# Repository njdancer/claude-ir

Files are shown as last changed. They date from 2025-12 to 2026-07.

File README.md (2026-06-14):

# claude-ir — ESP32 IR smart controller for ActronAir AC

A smart IR controller for an **ActronAir** (rebranded Midea) air conditioner.
The remote's IR protocol has been fully reverse-engineered, and a working
ESP8266 breadboard transmits real commands to the AC. The active mission is a
custom **ESP32-C3** dev board, taken from schematic → PCB → fabricated,
verified unit → production firmware → eventual HomeKit.

> 🤖 **Designed end-to-end by [Claude](https://claude.ai)** (Anthropic),
> directed by Nick Dancer. Reverse engineering, schematic, PCB layout,
> firmware, and the web UI were produced autonomously. Non-commercial hobby
> project.

📦 **Published board artifacts** (regenerated on every merge):
**<https://njdancer.github.io/claude-ir/>** — interactive 3D board viewer,
schematic PDF/SVGs, BOM, and the JLCPCB fabrication package.

## Status

| Part | State |
|---|---|
| **IR protocol** | ✅ Reverse-engineered (BOSCH144 + COOLIX), documented in `re-findings.md` |
| **Breadboard POC** | ✅ Working — ESP8266 transmits to the real AC (the verified reference) |
| **ESP32-C3 board** | 🟢 v2 cost-down redesign — schematic + PCB complete, CI-green; **pre-fabrication** |
| **Firmware (ESP32-C3)** | 🟢 Ported (`pio run -e esp32-c3`); production hardening in progress |
| **Web control UI** | ✅ React Router app with mock + real serial |
| **HomeKit** | ⏸️ Not started |

See **[`ROADMAP.md`](./ROADMAP.md)** for the live project state and next
actions — it is the authoritative state file.

## Sources of truth

| Artifact | Truth for |
|---|---|
| `hardware/*.kicad_sch` / `.kicad_pcb` | The board design (edit only via KiCad) |
| `hardware/esp32-ir-remote.net` | Reviewable electrical state (regenerated by `scripts/hardware-check.sh`) |
| `specs/hardware-dev-board-v1.md` | Board requirements (RFC-style spec) |
| `re-findings.md` | IR protocol knowledge (byte maps, timings) |
| `ROADMAP.md` | Project state & next actions |
| `hardware/notes/*.md` | Design rationale (if a note contradicts the schematic, the schematic wins) |

## The ESP32-C3 board (`hardware/`)

The custom board uses an **ESP32-C3-WROOM-02** module whose native
USB-Serial-JTAG controller means no USB-UART bridge chip: flash and monitor run
straight over USB-C. Key subsystems: 4× IR-emitter array (TSAL6200 via an
AO3400A driver), TSOP38238 IR receiver, AHT20 I²C temp/humidity sensor,
AMS1117-3.3 LDO from USB-C 5 V, and status/user LEDs. GPIO map and
per-subsystem rationale live in [`hardware/notes/README.md`](./hardware/notes/README.md).

**CI is the authoritative hardware gate** (`.github/workflows/ci.yml`): every PR
runs ERC/DRC vs `hardware/ci-baseline.json`, netlist freshness, schematic↔PCB
parity, page-extent and 3D-model checks, BOM LCSC lint, firmware builds + native
tests, and the app's typecheck/unit/e2e. Open a PR and watch CI rather than
re-running the battery by hand.

```bash
./scripts/hardware-check.sh              # ERC + regenerate netlist (needs kicad-cli)
python3 scripts/ci/hardware_validate.py  # full design gate (what CI runs)
python3 scripts/fab-outputs.py           # regenerate the JLCPCB order package
./scripts/build-site.sh                  # build the Pages site (schematic, 3D viewer, fab)
```

> ⚠️ KiCad work happens on Nick's Mac (KiCad 9 + the kicad MCP). Remote/web
> sessions do firmware, analysis, app, docs, and planning only — they queue
> KiCad tasks in `ROADMAP.md`.

## IR protocol

ActronAir is controlled with two protocols, both natively supported by
IRremoteESP8266:

- **BOSCH144** (144-bit) — climate state: power-on, temperature, mode, fan.
- **COOLIX** (24-bit) — discrete commands: power-off (`0xB27BE0`), swing, boost, LED.

The two payloads carry **disjoint** attributes, so AC state can be partially
stale after any single command — firmware must track per-payload freshness.
Full byte maps and timings are in [`re-findings.md`](./re-findings.md).

## Breadboard reference (working POC)

The proven ESP8266 reference that the board is based on:

- **Board:** ESP8266 NodeMCU (ESP-12E)
- **IR RX:** TSOP/VS1838B-class receiver OUT → GPIO14 (D5)
- **IR TX:** IR LED (940 nm) driven by a 2N2222 on GPIO4 (D2), 470 Ω base / current-limited LED

Full wiring is in [`wiring.md`](./wiring.md). The firmware exposes a 115200-baud
serial command interface:

| Command | Example | Description |
|---|---|---|
| `POWER:ON` / `POWER:OFF` | `POWER:ON` | On (BOSCH144) / Off (COOLIX) |
| `TEMP:<16.0–30.0>` | `TEMP:22.5` | Set temperature (0.5° steps) |
| `MODE:<COOL\|HEAT\|DRY\|FAN\|AUTO>` | `MODE:COOL` | Set mode |
| `FAN:<AUTO\|20…100>` | `FAN:60` | Set fan speed |
| `SWING` / `BOOST` / `LED` | `BOOST` | Special functions (COOLIX) |
| `STATE` | `STATE` | Query tracked state |

Responses are `OK:<message>` or `ERROR:<message>`.

## Web control UI (`app/`)

A React Router (v7) full-stack app for AC control over serial, with a mock
serial mode for hardware-free development.

```bash
cd app && pnpm install
MOCK_SERIAL=true pnpm dev   # http://localhost:5173, no hardware needed
pnpm test                   # vitest unit tests
pnpm test:e2e               # playwright e2e
```

For real hardware, set the serial port in `app/app/lib/serial.server.ts`.

## Build & test

```bash
pio run -e esp32-c3              # build the ESP32-C3 board firmware
pio run -e nodemcuv2             # build the ESP8266 breadboard firmware
pio test -e native              # host-side unit tests
./scripts/flash.sh              # flash from the macOS host
./scripts/monitor.sh            # serial monitor (115200)
python3 scripts/capture.py <lbl># capture one IR signal to captures/
python3 analysis/decoder.py     # analyze the capture corpus
```

Firmware builds run in the podman devcontainer (or host); flash/monitor run on
the macOS host (USB passthrough doesn't work under podman/macOS).

## References

- [IRremoteESP8266](https://github.com/crankyoldgit/IRremoteESP8266)
- [PlatformIO](https://docs.platformio.org/)
- [Claude Code on the web](https://code.claude.com/docs/en/claude-code-on-the-web)

## License

Non-commercial, educational/personal hobby project. The spark mark on the
published site is an original homage to Claude's logo.

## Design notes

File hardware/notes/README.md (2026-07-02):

# Hardware Engineering Notes

> ⚠️ **The board is now the v2 ESP32-C3 cost-down redesign** (ESP32-C3-WROOM-02,
> AMS1117 LDO, AHT20 sensor, SMD USB-C; CH340C/JTAG/buck removed). Several notes
> below still describe the v1 WROOM-32E architecture and are being updated. The
> as-built description is the v2 change set in [`ROADMAP.md`](../../ROADMAP.md);
> where a note disagrees with the schematic, the schematic wins.

Design rationale for the ESP32 IR Remote Control Development Board (v1.1).

**Source of truth: the KiCad project** (`hardware/esp32-ir-remote.kicad_sch` /
`.kicad_pcb`). These notes capture *why* the circuit is the way it is — design
decisions, calculations, and constraints. They intentionally do not enumerate
connections; the schematic and exported netlist do that. If a note and the
schematic disagree, the schematic wins and the note should be fixed.

## Verification workflow

Every schematic change should be followed by:

```bash
./scripts/hardware-check.sh
```

This runs ERC and regenerates `hardware/esp32-ir-remote.net` via `kicad-cli`
(found in PATH or the macOS KiCad.app bundle). Commit the regenerated netlist
alongside the schematic change — the netlist diff is the reviewable record of
what changed electrically, since `.kicad_sch` diffs are dominated by graphics.

## Subsystems

| Note | Scope |
|---|---|
| [power-supply.md](./power-supply.md) | USB-C input, protection, AP63203 buck regulation |
| [usb-serial.md](./usb-serial.md) | v2 native USB (no bridge); USB-C connector data path + hand-solder note |
| [esp32-mcu.md](./esp32-mcu.md) | WROOM-32E module, strapping pins, buttons, breakout header |
| [ir-transmitter.md](./ir-transmitter.md) | 4× TSAL6200 array with MOSFET driver |
| [ir-receiver.md](./ir-receiver.md) | TSOP38238 development receiver |
| [temp-sensor.md](./temp-sensor.md) | DHT22/AM2302 for Follow Me |
| [status-leds.md](./status-leds.md) | Serial activity and user LEDs |
| [layout.md](./layout.md) | PCB layout constraints: placement, routing, stackup (H2) |

## GPIO pin assignments (v2 board, ESP32-C3; r2 GPIO remap 2026-07-02)

The r2 autoresearch loop remapped the free GPIOs so each signal exits the
module on the side facing its board zone (B.Cu ground-plane slotting fell
390→167 mm). `scripts/ci/golden_netlist_v2.py` asserts this map; firmware
pins live in `platformio.ini` `[env:esp32-c3]` build_flags.

| GPIO | Function | Direction | Notes |
|---|---|---|---|
| EN | Reset (SW1)  | Input | R5 pull-up + C6 POR RC |
| 9 | Boot (SW2) | Input | strapping, R6 pull-up |
| 10 | IR transmit  | Output | 38 kHz → R13 → Q3 gate; D10 TX indicator  |
| 6 | IR receive | Input | TSOP38238 |
| 20 | I2C SDA | I/O | AHT20 + J4; R28 pull-up (UART0-RX pin) |
| 21 | I2C SCL | Output | AHT20 + J4; R29 pull-up (UART0-TX pin) — ROM boot spew clocks the bus once per boot; firmware must bus-clear at init |
| 3 | User LED 1 | Output | direct drive, yellow 0805 |
| 1 | User LED 2 | Output | direct drive, yellow 0805 |
| 18/19| USB D−/D+ | I/O | native USB-Serial-JTAG |
| 2, 8 | (strapping)  | — | pull-ups only, left NC |
| 0,4,5,7 | spares | I/O | broken out on J4 |

## Top-level design rationale

**Power architecture.** v2 uses a single AMS1117-3.3 LDO from USB 5 V (the v1
AP63203 buck was dropped in the cost-down: a 1S LiPo can't feed the buck's
dropout anyway, and on USB power the LDO's ~0.85 W is handled by a ~1050 mm²
top-side thermal pour + B.Cu island stitched under the tab — θ_JA ≈ 45–55 °C/W,
T_J ≈ 72 °C worst case). See [power-supply.md](./power-supply.md).

**IR LED drive.** A single MOSFET drives all four LEDs so they emit
simultaneously for maximum coverage. ~86 mA per LED (22 Ω Basic-part series
resistors) gives good range at reasonable power.

**Boot configuration.** The C3's strapping pins (IO2, IO8, IO9) carry
pull-ups; flashing runs over native USB-Serial-JTAG (no auto-reset circuit
needed — SW1/SW2 remain for manual recovery).

**Development-board posture.** The board prioritizes ease of assembly and
debugging over miniaturization: hand-solderable packages only, DevKitC-
compatible breakout header, and features (IR receiver, extensive status LEDs)
that a production board would omit. See `specs/hardware-dev-board-v1.md` for
the full requirements spec.

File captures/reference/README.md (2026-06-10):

# Reference IR captures (protocol ground truth)

Curated, de-duplicated subset of the local capture corpus, copied here from
the gitignored `captures/*.txt` scratch files so the protocol fixtures are
version-controlled. Each file is a real capture of the ActronAir remote
decoded by the ESP8266 + IRremoteESP8266 (see `re-findings.md`).

Selection: one clean, valid-decode capture per documented state. The physical
remote is the only way to regenerate these, so treat them as fixtures —
cross-checked against the `include/bosch144_protocol.h` unit tests.

Notes:
- Temp sweep (`temp-16`..`temp-26`, COOL mode) shares the `3FC0` prefix; the
  temperature nibble varies. Half-degree variants (`16.5`, `18.5`) exercise the
  byte-14 bit-5 half-degree flag.
- `power-on` (3FC0) vs `power-on-2`/`power-button` (BF40) capture different base
  states; both retained intentionally.
- COOLIX commands are discrete toggles: power-off `0xB27BE0`, swing `0xB9F504/5`
  (alternating), boost `0xB9F501`, LED `0xB9F509`.
- No valid `temp-28` capture exists (both bench attempts failed to decode) —
  this is the open item flagged for F1.5 bench verification.

| Fixture | Protocol | Decoded code | Bits | Original capture |
|---|---|---|---|---|
| `boost-button-coolix.txt` | COOLIX | `0xB9F501` | 24 Bits | `20251229_145919_boost-button.txt` |
| `fan-press-1.txt` | BOSCH144 | `0xB24DFF0020DFB24DFF0020DFD514000000E9` | 144 Bits | `20251228_153501_fan-press-1.txt` |
| `fan-press-2.txt` | BOSCH144 | `0xB24D9F6020DFB24D9F6020DFD528000000FD` | 144 Bits | `20251228_153530_fan-press-2.txt` |
| `fan-press-3.txt` | BOSCH144 | `0xB24D5FA020DFB24D5FA020DFD53C00000011` | 144 Bits | `20251228_153548_fan-press-3.txt` |
| `fan-press-4.txt` | BOSCH144 | `0xB24D3FC020DFB24D3FC020DFD55000000025` | 144 Bits | `20251228_153621_fan-press-4.txt` |
| `fan-press-5.txt` | BOSCH144 | `0xB24D3FC020DFB24D3FC020DFD56400000039` | 144 Bits | `20251228_153656_fan-press-5.txt` |
| `fan-press-6-back-to-auto.txt` | BOSCH144 | `0xB24DBF4020DFB24DBF4020DFD5660000003B` | 144 Bits | `20251228_153724_fan-press-6-back-to-auto.txt` |
| `led-button-coolix.txt` | COOLIX | `0xB9F509` | 24 Bits | `20251229_145934_led-button.txt` |
| `mode-press-1-dry.txt` | BOSCH144 | `0xB24D1FE024DBB24D1FE024DBD5650000003A` | 144 Bits | `20251228_153224_mode-press-1.txt` |
| `mode-press-2-heat.txt` | BOSCH144 | `0xB24DBF402CD3B24DBF402CD3D5660000003B` | 144 Bits | `20251228_153253_mode-press-2.txt` |
| `mode-press-3.txt` | BOSCH144 | `0xB24DBF40E41BB24DBF40E41BD5660000003B` | 144 Bits | `20251228_153316_mode-press-3.txt` |
| `mode-press-4.txt` | BOSCH144 | `0xB24D1FE028D7B24D1FE028D7D5650000003A` | 144 Bits | `20251228_153337_mode-press-4.txt` |
| `mode-press-5-back-to-cool.txt` | BOSCH144 | `0xB24DBF4020DFB24DBF4020DFD5660000003B` | 144 Bits | `20251228_153409_mode-press-5-back-to-cool.txt` |
| `power-button.txt` | BOSCH144 | `0xB24DBF4040BFB24DBF4040BFD5662000005B` | 144 Bits | `20251229_145719_power-button.txt` |
| `power-off-coolix.txt` | COOLIX | `0xB27BE0` | 24 Bits | `20251229_145838_power-off.txt` |
| `power-on-2.txt` | BOSCH144 | `0xB24DBF4040BFB24DBF4040BFD5662000005B` | 144 Bits | `20251229_145901_power-on-2.txt` |
| `power-on.txt` | BOSCH144 | `0xB24D3FC040BFB24D3FC040BFD56400000039` | 144 Bits | `20251228_085537_power-on.txt` |
| `swing-test-coolix-a.txt` | COOLIX | `0xB9F504` | 24 Bits | `20251228_155349_swing-test.txt` |
| `swing-test-coolix-b.txt` | COOLIX | `0xB9F505` | 24 Bits | `20251228_155423_swing-test-2.txt` |
| `temp-16.5.txt` | BOSCH144 | `0xB24D3FC000FFB24D3FC000FFD56420100069` | 144 Bits | `20251228_091732_temp-16.5-retry.txt` |
| `temp-16.txt` | BOSCH144 | `0xB24D3FC000FFB24D3FC000FFD56400100049` | 144 Bits | `20251228_091151_temp-16.txt` |
| `temp-18.5.txt` | BOSCH144 | `0xB24D3FC010EFB24D3FC010EFD56420000059` | 144 Bits | `20251228_091832_temp-18.5.txt` |
| `temp-18.txt` | BOSCH144 | `0xB24D3FC010EFB24D3FC010EFD56400000039` | 144 Bits | `20251228_091759_temp-18.txt` |
| `temp-20.txt` | BOSCH144 | `0xB24D3FC020DFB24D3FC020DFD56400000039` | 144 Bits | `20251228_085719_temp-20.txt` |
| `temp-22.txt` | BOSCH144 | `0xB24D3FC0708FB24D3FC0708FD56400000039` | 144 Bits | `20251228_092757_temp-22.txt` |
| `temp-24.txt` | BOSCH144 | `0xB24D3FC040BFB24D3FC040BFD56400000039` | 144 Bits | `20251228_085741_temp-24.txt` |
| `temp-26.txt` | BOSCH144 | `0xB24D3FC0D02FB24D3FC0D02FD56400000039` | 144 Bits | `20251228_092834_temp-26.txt` |
| `temp-max-cool.txt` | BOSCH144 | `0xB24D3FC0B04FB24D3FC0B04FD56400000039` | 144 Bits | `20251228_092000_temp-max-cool.txt` |

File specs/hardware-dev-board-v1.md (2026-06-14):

# ESP32 IR Remote Control Development Board - Hardware Specification v1.4

## Overview

This specification defines the hardware requirements for a development board that enables testing and development of an ESP32-based smart AC remote control system using infrared transmission. The board serves as a transition from the current ESP8266 breadboard proof-of-concept to a manufacturable design suitable for firmware development and eventual production refinement.

> ⚠️ **SUPERSEDED ARCHITECTURE — read this first (v2.0, 2026-06).** The
> fabricated board is the **v2 ESP32-C3 cost-down redesign**, NOT the
> ESP32-WROOM-32E architecture described in the body of this document below.
> The as-built board:
> - **MCU: ESP32-C3-WROOM-02-N4** (LCSC C2934560), not WROOM-32E. The C3's
>   native USB-Serial-JTAG let the **entire CH340C USB-serial subsystem be
>   deleted** (no bridge, no auto-reset FETs).
> - **Power: AMS1117-3.3 LDO** (U1), not the AP63203 buck + inductor.
> - **Temp/humidity: AHT20** I2C sensor (U5), not the AM2302/DHT22.
> - **USB-C: SMD 16P XKB U262** receptacle (J2), not the THT GCT part.
> - Status LEDs moved to 0805 SMD; JTAG header and TX/RX activity LEDs removed.
>
> The **as-built description is the v2 change set in [`ROADMAP.md`](../ROADMAP.md)**
> (the project state file) and the live schematic/netlist under `hardware/`.
> The WROOM-32E content below is retained for v1.4 design rationale only and
> is being rewritten for v2 as a follow-up. Where this spec body and the
> schematic disagree, **the schematic wins.**

> **Revision note (v1.4):** Pre-order cost/availability pass. The assembly
> model is now explicitly **SMT-only machine assembly plus a hand-solder
> kit** (see [Assembly Considerations](#assembly-considerations)): JLCPCB
> places only top-side SMD parts, and every through-hole part plus the easy
> two-terminal SMD Extended parts ship loose. Two Basic-part substitutions:
> the IR driver MOSFET Q3 (IRLML6344 → AO3400A, same SOT-23/pinout, meets
> all stated requirements) and the BOOT/RESET switches (TS-1088R → XKB
> TS-1187A-B-A-B, SMD 5.1×5.1mm 4-pad — same-row terminals internally
> common). Only three Extended parts remain machine-placed: the buck
> regulator, the CH340C, and the WROOM module.
>
> **Revision note (v1.3):** Auto-reset transistors Q1/Q2 changed from NPN BJTs
> (S8050) to 2N7002 N-channel MOSFETs. The SOT-23 pinouts map 1:1 (B→G, E→S,
> C→D), so the change is layout-neutral; it consolidates Q1/Q2 onto the same
> BOM line as Q4/Q5 (JLCPCB Basic part C8545). Circuit topology and truth
> table are unchanged. The R21/R26 bypass links changed from 0Ω to **470Ω**
> to limit FET body-diode current into the CH340C while RESET/BOOT is held
> (restores BJT-grade benignity); they remain desolder-to-disable. See
> [Auto-Reset Circuit](#auto-reset-circuit).
>
> **Revision note (v1.2):** The board target shifted toward "get it fabricated." The
> bulky 2×19 ESP32-DevKitC debug breakout header is **removed** and replaced with a
> small set of purposeful connection points (I2C Qwiic, a compact spare-GPIO + power
> header, an external IR-emitter header, and an unpopulated JTAG footprint) — see
> [Connection Points and Expansion](#connection-points-and-expansion). The
> WROOM-32E (PCB antenna) is retained; the U.FL external-antenna option is deferred.
> This revision also reconciles the spec to the KiCad schematic (the source of
> truth): auto-reset bypass jumpers JP2/JP3 are now R21/R26 0Ω SMD links, and the
> buck inductor L1 is 4.7µH. Several H1.4 datasheet-review fixes are folded in (IR-TX
> gate resistor, IR-RX supply filter). The Bill of Materials below lags the schematic
> on reference designators and MUST be regenerated from it (see the BOM note).

### Design Philosophy

The board prioritizes ease of assembly and debugging over miniaturization. Components MUST be hand-solderable, which excludes packages like BGA but permits both through-hole and large SMD components (SOT-223, SOIC, etc.). Standard 2.54mm (0.1") pin headers are PREFERRED for development flexibility, but other pitches and connection methods are acceptable where hand assembly remains feasible.

The design intentionally includes features (such as IR receiver and extensive status LEDs) that may be omitted from production boards but facilitate rapid development iteration.

### Manufacturing Target

The board MUST be manufacturable through JLCPCB's standard PCB service with components readily available through common distributors (Digikey, Mouser, LCSC). Two-layer PCB construction is acceptable given the modest component count and frequency requirements.

## Functional Requirements

### Primary Functions

The board MUST provide:

1. **Omnidirectional IR Transmission**: Reliable infrared signal transmission across a 180-degree horizontal arc at distances up to 10 meters. The system must function with indirect line-of-sight (wall reflections) to match typical consumer remote control behavior.

2. **Environmental Sensing**: Accurate room temperature measurement (±1°C) for implementing "Follow Me" functionality where the AC unit adjusts output based on temperature at the remote's location.

3. **Development Support**: Comprehensive debugging capabilities including IR signal reception verification, serial communication monitoring, and visual feedback of system state.

### IR Transmission Characteristics

The IR transmitter MUST generate 940nm infrared pulses modulated at 38kHz carrier frequency compatible with the COOLIX and BOSCH144 protocols identified in the reverse engineering phase. The transmission pattern must support both sustained transmission (for BOSCH144's 144-bit messages) and short burst commands (for COOLIX's 24-bit special functions).

Unlike the current breadboard implementation which requires precise aiming, the production system must achieve reliable communication when the remote is casually pointed toward the AC unit or nearby surfaces. This requires multiple IR emitters with overlapping coverage areas rather than a single high-power directional emitter.

### Power Delivery

The board MUST operate from USB-C power (5V nominal) and maintain stable 3.3V regulation under varying load conditions. Peak current draw during WiFi transmission with simultaneous IR emission (approximately 350-400mA) must not cause voltage droop exceeding 100mV at the ESP32's power pins.

The power subsystem MUST implement overcurrent protection (trip at 2A) and overvoltage protection (clamp below 6V). Reverse polarity protection is omitted for the USB-C input as the connector enforces correct orientation; reverse protection MAY be added on the battery input path when that feature is implemented.

### Battery Support

Battery operation is **deferred to v2**. This development board is USB-powered only.

The spare-GPIO + power header (see [Connection Points and Expansion](#connection-points-and-expansion)) exposes 3.3V and 5V rails, enabling experimentation with external battery and power management circuits on a separate prototyping board. A jumper (JP1) on the buck converter's EN pin allows disabling the internal regulator when testing external power solutions (see Voltage Regulation section).

## Component Specifications

### Microcontroller Module

**Specified Module**: ESP32-WROOM-32E-N4 (Espressif WiFi+BT module)

The board MUST use the ESP32-WROOM-32E-N4 module directly, rather than a development board. This provides full control over the supporting circuitry while using a proven, FCC/CE certified RF module. The module integrates:

- ESP32-D0WD-V3 dual-core Xtensa LX6 @ 240MHz
- 4MB SPI flash (N4 variant)
- 520KB internal SRAM
- 40MHz crystal oscillator
- PCB trace antenna
- All required RF matching and filtering

**Module Specifications**:

- Dimensions: 18mm × 25.5mm × 3.1mm
- Pins: 38 castellated pads at 1.27mm pitch
- Operating voltage: 3.0-3.6V (3.3V nominal)
- Operating temperature: -40°C to +85°C
- Deep sleep current: <5µA

The module exposes sufficient GPIO pins to support:

- 4× IR LED driver signals
- 1× IR receiver input
- I2C interface (SDA/SCL) for temperature sensor
- UART0 (programming and debug)
- User programmable GPIO for expansion

**Required Support Circuitry**: Unlike a development board, the bare module requires external circuitry for:

1. **Power regulation**: 3.3V supply (provided by AP63203 synchronous buck converter per this spec)
2. **USB-to-UART bridge**: For programming and serial communication (see USB-to-UART Bridge section)
3. **Auto-reset circuit**: Transistor network for automatic bootloader entry (see Auto-Reset Circuit section)
4. **EN pin conditioning**: RC delay circuit for reliable power-on reset
5. **Strapping pin management**: Pull-ups/pull-downs on boot mode pins

**Power Architecture**: The board provides 3.3V regulation via the AP63203 synchronous buck converter specified in the Voltage Regulation section. The module draws:

- Typical: 80-120mA (WiFi idle)
- Peak: 240mA (WiFi TX burst)
- Deep sleep: <5µA

The 2A-rated buck converter provides adequate headroom for the module plus all peripherals.

**Mounting**: The module's castellated pads can be hand-soldered to the PCB. For easier assembly, the PCB layout SHOULD include:

- Extended pads beyond the module footprint for solder iron access
- Solder mask relief around pads
- Clear silkscreen indicating pin 1 orientation

### Infrared Emitters

**Quantity**: 4 emitters
**Package**: 5mm (T-1 3/4) through-hole or equivalent hand-solderable package

The board MUST position four IR LEDs with their optical axes oriented at approximately 0°, 45°, 90°, and 135° from the board's centerline, providing overlapping hemispherical coverage. All emitters drive simultaneously during transmission to maximize signal strength across the coverage area.

**LED Requirements**:

- Peak wavelength: 940nm ±10nm (matches TSOP receiver sensitivity peak)
- Continuous forward current: ≥100mA
- Peak pulsed current: ≥1A (at 10% duty cycle, for future high-power modes)
- Forward voltage: 1.2-1.5V typical
- Radiant intensity: ≥30 mW/sr @ 100mA
- Viewing angle: ≥20° for adequate coverage overlap

**Suggested Part**: Vishay TSAL6200 meets all requirements and is widely available.

Each LED MUST be driven through an independent NPN transistor with base current limiting and collector current limiting resistors. The current limiting resistor value MUST provide 80-100mA LED current when driven from the regulated supply, balancing transmission power against LED lifetime and power dissipation.

### Infrared Receiver

**Quantity**: 1
**Purpose**: Development and debugging only
**Package**: Through-hole 3-pin module or equivalent hand-solderable package

**Receiver Requirements**:

- Center frequency: 38kHz (matches COOLIX/BOSCH144 carrier frequency)
- Supply voltage: 3.3V compatible
- Output: Active-low demodulated signal
- Built-in bandpass filter and AGC
- Minimum detectable power: <1 mW/m² typical for IR receiver modules

**Suggested Parts**: Vishay TSOP1838, TSOP4838, or equivalent 38kHz receiver modules.

The IR receiver enables verification of transmitted waveforms and debugging of protocol encoding. It MUST connect to a GPIO pin configured with interrupt capability to capture timing-accurate signal edges. While essential during development, production boards may omit this component.

### Temperature Sensor

**Interface**: Single-wire (proprietary protocol)
**Mounting**: Through-hole module with pin headers

**Sensor Requirements**:

- Temperature accuracy: ±0.5°C across 18-28°C range (typical indoor AC environment)
- Supply voltage: 3.3V compatible
- Sleep current: <10µA (for battery operation testing)
- Response time: <2 seconds for room temperature changes

**Additional Capabilities**:

- Humidity sensing (enables comfort index calculations)

**Specified Part**: DHT22 (AM2302) temperature and humidity sensor module. The module includes the required pull-up resistor on the data line. Connect to any available GPIO pin.

### USB-C Power Connector

**Connector Requirements**:

- Mounting: Through-hole or large SMD with hand-solderable pins (not fine-pitch SMT-only)
- Pinout: USB 2.0 minimum (VBUS, GND, CC1, CC2 accessible; D+/D- optional)
- Mechanical strength: Through-hole anchor pins or large mounting pads
- Current rating: ≥3A continuous

**Specified Connector**: GCT USB4085-GF-A (fully through-hole USB-C receptacle)

This connector is specified due to its through-hole construction enabling reliable hand assembly and its availability from major distributors. Alternative through-hole USB-C receptacles with equivalent pinout are acceptable.

**Power Delivery Configuration**: CC1 and CC2 pins MUST connect to ground through 5.1kΩ ±5% resistors to signal 5V/3A power capability to USB-PD sources. This resistor configuration enables the board to draw sufficient current from modern USB-C chargers without implementing complex PD negotiation.

**USB Data Lines**: D+ and D- pins connect to the USB-to-UART bridge IC for programming and serial communication (see USB-to-UART Bridge section).

### USB-to-UART Bridge

The board MUST include a USB-to-UART bridge IC to enable programming and serial communication with the ESP32 module. This replaces the functionality provided by the CP2102 on the ESP32-DevKitC.

**Bridge IC Requirements**:

- USB 2.0 Full Speed (12 Mbps) support
- 3.3V I/O compatible (no level shifting required)
- Baud rates up to 921600 (required for fast firmware upload)
- DTR and RTS flow control signals (required for auto-reset circuit)
- Package: Hand-solderable (SOIC, SSOP, or QFN with exposed pad)
- Built-in oscillator preferred (reduces external component count)
- Windows/macOS/Linux driver support

**Recommended ICs** (in order of preference):

1. **CP2102N** (Silicon Labs) - QFN-28 or QFN-24
   - Direct replacement for DevKitC's CP2102
   - Excellent driver support across all platforms
   - Built-in oscillator, minimal external components
   - Configurable GPIO pins (optional features)
   - Note: QFN package requires careful hand-soldering or reflow

2. **CH340C** (WCH) - SOP-16
   - Lower cost alternative
   - Built-in oscillator (no external crystal needed)
   - Wider pin pitch (easier hand soldering than QFN)
   - Good driver support (built into modern OS versions)
   - Requires 100nF decoupling capacitor

3. **CH340G** (WCH) - SOP-16
   - Similar to CH340C but requires external 12MHz crystal
   - Slightly lower cost, slightly more complex BOM

**Recommended Implementation**: CH340C in SOP-16 package

The CH340C offers the best balance of hand-solderability, cost, and simplicity for this development board. Its SOP-16 package (1.27mm pitch) is manageable with a fine-tip soldering iron, and the built-in oscillator eliminates the need for an external crystal.

**CH340C Circuit Requirements**:

```
USB D+ ──────────────────── CH340C UD+
USB D- ──────────────────── CH340C UD-
3.3V ────┬─────────────── CH340C VCC
         │
         └─────────────── CH340C V3 ───[100nF]─── GND
GND ─────────────────────── CH340C GND
GND ─────────────────────── CH340C R232 (pin 15)
CH340C TXD ─────────────── ESP32 U0RXD (GPIO3)
CH340C RXD ─────────────── ESP32 U0TXD (GPIO1)
CH340C DTR# ────[R21 470Ω]── Auto-reset circuit (cross-coupled, DTR side)
CH340C RTS# ────[R26 470Ω]── Auto-reset circuit (cross-coupled, RTS side)
```

**Notes**:
- TX/RX are crossed: CH340C TXD connects to ESP32 RXD, and vice versa
- **3.3V Operation**: V3 must be tied to VCC (both connected to 3.3V). This bypasses the internal regulator. Add 100nF decoupling capacitor from V3 to GND.
- **R232 Pin**: Must be tied to GND for TTL-level output compatible with ESP32. If tied high, outputs RS232 levels (wrong).
- DTR# and RTS# are active-low outputs used by the auto-reset circuit
- Refer to CH340C datasheet for physical pin assignments during PCB layout

**ESD Protection**: A USB ESD protection device (e.g., USBLC6-2SC6) SHOULD be placed on D+/D- lines near the USB connector to protect the bridge IC from electrostatic discharge.

### Voltage Regulation

The board MUST regulate the USB 5V input to stable 3.3V for powering the ESP32 module, IR receiver, temperature sensor, and status LEDs. A synchronous buck (step-down) switching regulator is REQUIRED for efficiency and thermal performance.

**Regulator Requirements**:

- Type: Synchronous buck (step-down) switching regulator
- Input voltage: 3.8-32V (wide input range)
- Output voltage: 3.3V ±1%
- Output current: ≥2A continuous
- Switching frequency: ≥500kHz (enables smaller external components)
- Efficiency: ≥90% at typical loads
- Package: Hand-solderable (TSOT26 or larger)
- Protection: Thermal shutdown, overcurrent protection, overvoltage protection

**Specified Implementation**: AP63203 (Diodes Incorporated) - Fixed 3.3V synchronous buck converter

- **Datasheet**: https://www.diodes.com/assets/Datasheets/AP63200-AP63201-AP63203-AP63205.pdf
- Synchronous topology (no external catch diode needed)
- Fixed 3.3V output (±1% accuracy, no feedback resistors needed)
- 2A output capability (ample headroom)
- 1.1MHz switching frequency (small external components)
- ~92-93% efficiency at typical loads
- TSOT26 package (0.95mm pitch, hand-solderable with fine-tip iron)
- Built-in soft-start (4ms), OVP, OCP, thermal shutdown
- Frequency spread spectrum for EMI reduction

**Required Support Components**:

1. **Input capacitor (C1)**: 10µF ceramic, 10V or higher (placed close to VIN pin)
2. **Output capacitors (C2, C3)**: 2× 22µF ceramic, 10V or higher (placed close to output)
3. **Bootstrap capacitor (C4)**: 100nF ceramic (between BST and SW pins)
4. **Inductor (L1)**: 4.7µH, ≥2.7A saturation current, low DCR (AP63203 datasheet typical; prefer a JLCPCB Basic part)
   - Package: SMD power inductor (hand-solderable)
   - Size: 4x4mm or 5x5mm typical

**No catch diode required** - the AP63203's synchronous topology uses an integrated low-side MOSFET instead.

**PCB Layout Considerations**:

- Keep switching node (SW pin to inductor) trace short and away from sensitive signals
- Input capacitor must be placed immediately adjacent to VIN and GND pins
- Output capacitors placed close to FB pin and load
- Use multiple vias for ground connections to bottom plane
- Bootstrap capacitor placed close to BST and SW pins

**Buck Converter Disable Jumper (JP1)**:

A 2-pin header (JP1) connects the AP63203 EN pin to GND, allowing the internal regulator to be disabled for external power experimentation:

```
AP63203 EN pin ────┬──── (internal pullup to VIN)
                   │
                  JP1 (2-pin header)
                   │
                  GND
```

- **JP1 open (default)**: EN floats high via internal pullup → buck converter enabled, normal USB operation
- **JP1 shorted**: EN pulled to GND → buck converter disabled, output goes high-impedance

**Use case**: When prototyping external battery/buck-boost circuits on a separate board, install the JP1 jumper to disable the internal regulator, then feed external 3.3V via the GPIO expansion header's 3V3 pin.

### Protection Components

The power input path MUST include:

**Overcurrent Protection**:

- Type: Resettable PTC fuse (polyfuse) or equivalent resettable overcurrent device
- Hold current: 1.0-1.2A (allows normal operation)
- Trip current: 1.8-2.2A (protects against shorts)
- Package: Through-hole radial or SMD
- **Suggested Part**: Bourns MF-R110 or equivalent

**Overvoltage Protection**:

- Type: TVS (Transient Voltage Suppression) diode
- Clamp voltage: 5.5-6.5V (protects 5V circuit, below regulator absolute maximum)
- Transient power rating: ≥400W
- Package: Hand-solderable (DO-214AA/SMB, DO-214AB/SMC, or through-hole)
- Placement: After fuse, before voltage regulator
- **Suggested Part**: SMBJ5.0A or equivalent

**Reverse Polarity Protection**: Omitted for USB-C input. The USB-C connector physically enforces correct orientation, and the CC resistor configuration ensures proper power negotiation. Reverse protection SHOULD be added on the battery input path when that feature is implemented (P-MOSFET recommended for efficiency).

### Status Indicators

The board MUST include visible LED indicators for debugging and status monitoring. All status LEDs use 3mm through-hole package for compact layout while maintaining hand-solderability.

**Power Rail LEDs** (direct-driven from power rails):

These LEDs connect directly to their respective power rails through current-limiting resistors, providing immediate visual confirmation of power presence without GPIO involvement.

*5V Rail Indicator* (Red):
- Function: Illuminated whenever USB 5V input is present (before buck converter)
- Connection: 5V rail → resistor → LED → GND
- Resistor value: 680Ω for ~5mA with Vf=1.9V red LED
- Purpose: Distinguishes input power issues from buck converter failures

*3.3V Rail Indicator* (Green):
- Function: Illuminated whenever regulated 3.3V is present (after buck converter)
- Connection: 3.3V rail → resistor → LED → GND
- Resistor value: 470Ω for ~3mA with Vf=2.0V green LED
- Purpose: Confirms buck converter operation

**GPIO-Controlled LEDs** (MOSFET-driven from 5V rail):

All GPIO-controlled status LEDs are driven through individual N-channel MOSFETs configured as low-side switches. This design provides:
- Consistent brightness across all LED colors (including blue with Vf ~3.2V)
- Minimal GPIO current draw (~nA gate current vs mA LED current)
- GPIO protection from LED faults
- Ability to use any LED color regardless of forward voltage

*Circuit per LED*:
```
5V ─── R_limit ─── LED(+) ─── LED(-) ─── MOSFET drain
                                         MOSFET source ─── GND
                              GPIO ─── MOSFET gate
                              100kΩ ─── GND (gate pulldown)
```

*MOSFET Requirements*:
- Type: N-channel enhancement mode, logic-level
- Gate threshold: <2V (fully enhanced at Vgs=3.3V)
- Drain current: ≥50mA (adequate for indicator LEDs)
- Package: SOT-23
- **Suggested Part**: 2N7002 or equivalent small-signal MOSFET

*Serial TX/RX LEDs* (Amber, qty 2):
- Function: Visual confirmation of serial communication during programming
- Connection: GPIO-controlled via MOSFET
- Resistor value: 150Ω for ~10mA with Vf=2.0V amber LED (brighter for brief pulses)

*IR Transmit Indicator* (Red):
- Function: Indicates IR transmission activity
- Connection: GPIO-controlled via MOSFET
- Resistor value: 330Ω for ~10mA with Vf=1.9V red LED

*User Programmable LEDs* (Blue, qty 2):
- Function: Software-controlled for debugging and status indication
- Connection: GPIO-controlled via MOSFET
- Resistor value: 330Ω for ~5mA with Vf=3.2V blue LED
- PCB silkscreen MUST label GPIO numbers for firmware reference

**LED Package Requirements**:

- All status indicator LEDs: 3mm (T-1) through-hole package
- IR emitter LEDs remain 5mm (T-1 3/4) for maximum optical output
- Mounting: Positioned for visibility when board is horizontal

**LED Summary Table**:

| Function | Color | Qty | Drive Method | Supply | R_limit |
|---|---|-----|---|---|---|
| 5V Power | Red | 1 | Direct | 5V | 680Ω |
| 3.3V Power | Green | 1 | Direct | 3.3V | 470Ω |
| Serial TX | Amber | 1 | MOSFET | 5V | 150Ω |
| Serial RX | Amber | 1 | MOSFET | 5V | 150Ω |
| IR TX | Red | 1 | MOSFET | 5V | 330Ω |
| User LED 1 | Blue | 1 | MOSFET | 5V | 330Ω |
| User LED 2 | Blue | 1 | MOSFET | 5V | 330Ω |

### Control Switches

The board MUST include two momentary push buttons for ESP32 control:

**RESET Button**:

- Function: Initiates complete ESP32 system reset (equivalent to power cycle)
- Connection: Connects ESP32 EN (enable) pin to ground when pressed
- Pull-up: Shared with auto-reset circuit (see Auto-Reset Circuit section)

**BOOT Button**:

- Function: Enters bootloader/programming mode when held during reset
- Connection: Connects GPIO0 to ground when pressed
- Pull-up: Shared with auto-reset circuit (see Auto-Reset Circuit section)
- Usage: Hold BOOT, press RESET, release both to enter programming mode (manual override of auto-reset)

**Switch Requirements**:

- Type: Tactile momentary switch, normally-open (NO)
- Package: SMD or through-hole, hand-rework-friendly
- Actuation force: 100-300gf (comfortable for frequent development use)
- Positioning: Accessible while USB cable is connected
- **Specified Part (v1.4)**: XKB TS-1187A-B-A-B (LCSC C318884, JLCPCB Basic),
  SMD 5.1×5.1mm, 4 gull-wing terminals. Terminals on the same row are
  internally common, so the part behaves as SPST between the two rows; the
  footprint numbers the rows 1/1 and 2/2 and bridge tracks under the body
  join each pair. (Replaces the Extended TS-1088R from v1.2/v1.3.)

**Note**: With the auto-reset circuit in place, manual button presses are typically only needed for:
- Recovery from crashed firmware
- Debugging boot mode issues
- Testing without USB connection

Normal firmware upload uses the auto-reset circuit automatically.

### Connection Points and Expansion

The large 2×19 ESP32-DevKitC breakout header of earlier revisions is **removed**.
In its place the board MUST provide a small set of purposeful connection points so
that GPIO access, I2C expansion, and external-power prototyping survive without the
bulky header. The intent is to design in headroom now — footprints are cheap before
fabrication and impossible to add after — while keeping the populated board compact.

GPIO budget: after removing the breakout, the following ESP32 GPIOs are free and
safe to expose — GPIO5, 13, 14, 21, 22, 23, 25, 26, 27, 32, 33, 34, 35. GPIO6–11 are
the module's internal SPI-flash bus and MUST NOT be exposed or used as I/O. GPIO12 is
a flash-voltage strapping pin and MUST NOT be pulled high; it MAY be wired only to the
unpopulated JTAG footprint (see below), which presents no load unless a debugger is
attached.

**I2C Qwiic/STEMMA-QT connector** (REQUIRED): A 4-pin JST-SH (1.0mm) Qwiic-standard
connector on `GND, 3V3, SDA=GPIO21, SCL=GPIO22`. This is the primary expansion path —
it gives plug-and-play access to the I2C sensor/display ecosystem (light level,
pressure, air quality, an OLED status display, etc.) with no future board changes,
satisfying the deferred "additional I2C sensors" provision. Onboard I2C pull-ups
(see Optional Components) MUST have footprints; populate them if the attached module
lacks its own.

**Spare-GPIO + power header** (REQUIRED): A compact 2.54mm header exposing a versatile
subset of the free GPIOs plus power rails, replacing the breakout's "user GPIO" and
"3V3/5V rails for external-power prototyping" roles. RECOMMENDED signal set, chosen for
peripheral coverage: GPIO25 (DAC1), GPIO26 (DAC2), GPIO32 (ADC1/touch), GPIO33
(ADC1/touch), GPIO34 (ADC1, input-only), GPIO23 (general). The header MUST also expose
`3V3`, `5V`, and at least one `GND`. A 2×5 (10-pin) arrangement is suggested. The 3V3/5V
pins together with the buck-disable jumper JP1 provide the external-battery prototyping
hook referenced in [Battery Support](#battery-support).

**External IR-emitter header** (REQUIRED): A 2-pin 2.54mm header allowing an IR LED on
a flying lead to be aimed at the AC unit when the enclosure lacks line-of-sight. It
MUST tie an additional IR-LED branch (its own series current-limit resistor footprint)
across the existing IR drive — anode side to the IR supply rail through the resistor,
cathode to the IR MOSFET (Q3) drain — so the external emitter switches with the onboard
array and no extra driver is needed. The series-resistor footprint MAY be left
unpopulated until an external emitter is used.

**JTAG debug footprint** (OPTIONAL, unpopulated): A 2×5 2.54mm footprint on the ESP32
JTAG pins (GPIO12=TDI, GPIO13=TCK, GPIO14=TMS, GPIO15=TDO) plus 3V3 and GND, for an
ESP-PROG/OpenOCD hardware debugger. Left unpopulated (DNP); serial flashing over the
CH340C is the default path. Because the footprint is unloaded when no debugger is
attached, the GPIO12 flash-voltage strap and the GPIO15 default state are preserved.

**Common requirements**: 2.54mm pitch where pin headers are used, for jumper-wire and
ribbon compatibility. Every exposed pin MUST be silkscreen-labelled with its function
(e.g. `GPIO21/SDA`, `5V`, `GND`, `TDI`). Connectors SHOULD be selected from JLCPCB
**Basic** parts where a suitable one exists, to avoid assembly feeder fees.

## Circuit Design Requirements

### IR Transmitter Driver Circuit

All four IR LEDs are driven through a single N-channel MOSFET configured as a low-side switch. This design was chosen over individual NPN transistors for:

- **Power efficiency**: MOSFETs have no base current draw and lower on-state losses
- **Simpler drive**: Single GPIO controls all LEDs simultaneously
- **3.3V compatibility**: Logic-level MOSFET fully enhances at 3.3V gate drive

**MOSFET Requirements**:

- Type: N-channel enhancement mode MOSFET
- Drain current: ≥500mA continuous (handles 4 × 100mA LEDs)
- Gate threshold: <2V (must be fully enhanced at Vgs = 3.3V)
- Rds(on): <50mΩ at Vgs = 2.5V (minimizes power loss)
- Package: SOT-23 (hand-solderable with fine-tip iron)
- **Specified Part (v1.4)**: AO3400A (Alpha & Omega, LCSC C20917, JLCPCB
  Basic) - Vgs_th ≤ 1.45V, Rds_on = 48mΩ @ Vgs = 2.5V, Id = 5.7A. Meets
  every requirement above; replaces the Extended IRLML6344 (~19mV / ~8mW
  difference at the 0.42A burst — immaterial).

**LED Power Supply**:

LEDs are powered from the 3.3V regulated rail (not 5V) for improved efficiency:

- 3.3V supply reduces voltage drop across current-limiting resistors
- Power dissipated in resistors: 0.18W per LED (vs 0.35W from 5V)
- Total system efficiency improved ~28% during IR transmission
- Buck converter has adequate headroom (675mA peak vs 2A rating)

**Current Limiting Circuit**:

- Supply voltage (3.3V) → Current-limiting resistor → IR LED anode
- IR LED cathode → MOSFET drain (all 4 cathodes joined)
- Current-limiting resistor calculation for 100mA target current:
  ```
  R_limit = (V_supply - V_LED_forward - V_DS_on) / I_target
  R_limit = (3.3V - 1.5V - 0.01V) / 0.1A = 17.9Ω
  ```
- Use nearest standard value (18Ω, E24 series)
- Resistor power rating: ≥0.25W (dissipates ~0.18W during transmission)

**Gate Drive Circuit**:

- ESP32 GPIO18 (IR_TX) → gate series resistor → MOSFET gate
- 100kΩ pull-down resistor from gate to GND
- MOSFET source → GND
- Gate series resistor provides ESD protection and edge control, but MUST be small
  enough to switch the MOSFET cleanly at the 38kHz carrier: a 10kΩ value against
  the MOSFET input capacitance slows the gate edges to several microseconds — a
  large fraction of the ~13µs carrier half-period. The gate series resistor MUST
  be in the **~330Ω–1kΩ** range (H1.4 review; the schematic fits 470Ω).
- Gate pull-down ensures MOSFET is OFF during boot/reset when GPIO is high-impedance

The external IR-emitter header (see [Connection Points and Expansion](#connection-points-and-expansion))
adds an optional fifth IR branch on this same drain node, switched by the same MOSFET.

### IR Receiver Interface

The IR receiver module connects directly to the 3.3V rail, ground, and an ESP32 GPIO pin.

**Connection Requirements**:

- Power: 3.3V and GND from regulated supply
- Signal: GPIO19 (IR_RX), interrupt-capable, not a strapping pin
- Supply filter: the TSOP datasheet RECOMMENDS a series resistor (~100Ω) from 3.3V to
  the receiver Vs pin plus a ≥100nF capacitor from that local Vs node to GND. This RC
  filter MUST be provided here: the high-current IR transmitter shares the same 3.3V
  rail, so TX-induced supply spikes are exactly the disturbance the filter rejects.
  Place the cap as close to the receiver package as practical. (H1.4 review.)
- Output pull-up: NOT required. The TSOP382 output stage has an internal ~30kΩ
  pull-up; no external pull-up should be added.

**Signal Characteristics**:

- Output type: Active-low demodulated pulses (receiver outputs LOW when 38kHz modulated IR detected)
- Timing: Preserves pulse timing from original IR transmission after demodulation
- Pull-up: none required (TSOP382 has an internal ~30kΩ pull-up; see above)
- **GPIO Assignment**: GPIO19 (IR_RX) - interrupt-capable, not a strapping pin

The GPIO pin MUST support external interrupts to capture timing-accurate signal edges for protocol decoding.

### Temperature Sensor Interface

The DHT22 temperature/humidity sensor connects via a single-wire proprietary protocol to any available GPIO pin.

**Connection Requirements**:

- Data pin: GPIO4 (TEMP_DATA) - not a strapping pin
- Pull-up resistor: 10kΩ on data line (typically included on DHT22 module)
- Supply voltage: 3.3V and GND from regulated supply

**Mounting**:

- Connection method: Pin headers (female headers on main board recommended)
- Rationale: Allows sensor removal for testing or replacement without desoldering
- Alternative: Direct soldering acceptable if header mounting is impractical

### USB-C Power Entry

The USB-C connector's VBUS pin connects to the protection circuit as follows:

```
USB VBUS ----[PTC Fuse]----+----[TVS to GND]----[Voltage Regulator]
                           |
                          GND (TVS clamps overvoltage)
```

CC1 and CC2 pins each connect through 5.1kΩ resistors to GND. Shield pins connect to PCB ground plane. D+/D- pins connect to the USB-to-UART bridge IC for programming and serial communication.

### Auto-Reset Circuit

The auto-reset circuit enables automatic bootloader entry when programming tools (esptool, cargo-espflash) assert DTR and RTS signals. This eliminates the need to manually press BOOT and RESET buttons during firmware upload.

**Circuit Function**:

The ESP32 enters bootloader mode when:
- EN (enable) pin is pulsed LOW (reset)
- GPIO0 is held LOW during reset release

The auto-reset circuit uses two cross-coupled N-channel MOSFETs (2N7002) that form an XOR-like gate. This prevents the chip from being held in reset when both DTR and RTS are asserted together (which happens when opening a serial port).

**Truth Table**:

| DTR | RTS | EN | GPIO0 |
|-----|-----|----|---|
| 0 | 0 | HIGH | HIGH | (normal operation) |
| 0 | 1 | HIGH | LOW | (boot mode select) |
| 1 | 0 | LOW | HIGH | (reset) |
| 1 | 1 | HIGH | HIGH | (normal operation) |

**Circuit Schematic** (per ESP32-S2-SAOLA-1 reference design):

```
                    ┌────────────────────────────────────────┐
                    │                                        │
DTR ───┬───[10kΩ]───┴──┤Gate                                 │
       │               │     Q1 (2N7002)                     │
       │          ┌────┤Drain ────────┬──[10kΩ]── 3.3V       │
       │          │    │              │                      │
       │          │    └Source────────│────┐                 │
       │          │                   │    │                 │
       │          │                   EN   │                 │
       │          │                   │    │                 │
       │          │              [1µF cap] │                 │
       │          │                   │    │                 │
       │          │                  GND   │                 │
       │          │                        │                 │
       └──────────│────────────────────────│─────────────────┘
                  │                        │
RTS ───┬──────────│────────────────────────┘
       │          │
       └──[10kΩ]──┴──┤Gate
                     │     Q2 (2N7002)
                ┌────┤Drain ────────┬──[10kΩ]── 3.3V
                │    │              │
                │    └Source────────│──── DTR (cross-coupled)
                │                   │
                │                 GPIO0
                │
                └──── RTS (to Q1 source, cross-coupled)
```

**Key insight**: The sources are NOT grounded - each transistor's source connects to the opposite input signal (DTR to Q2 source, RTS to Q1 source). This cross-coupling creates the XOR behavior: with both inputs asserted, neither FET sees a gate-source voltage, so neither can pull its output low.

**MOSFET body diodes**: Each 2N7002's body diode (source→drain) creates a path from its input line into its output node (RTS→EN via Q1, DTR→GPIO0 via Q2) that conducts only when the output is pulled ~0.6V below the source line — in practice only while RESET or BOOT is held pressed with the serial port idle (lines high). The 470Ω R21/R26 links (v1.3) limit this current to ~5mA; the buttons still dominate the node, and desoldering R21/R26 breaks the paths entirely.

**Component Requirements**:

| Ref | Value | Purpose |
|-----|---|---|
| Q1, Q2 | 2N7002 N-channel MOSFET | Cross-coupled signal translation (shared BOM line with Q4/Q5) |
| R (×2) | 10kΩ | Gate series resistors (carried over from the BJT design; not required for FETs but layout-neutral) |
| R (×2) | 10kΩ | Pull-ups for EN and GPIO0 |
| C | 1µF ceramic | EN pin RC delay (power-on reset) |

**Reference**: This circuit matches the ESP32-S2-SAOLA-1 topology from Espressif (which uses NPN BJTs; this board substitutes pin-compatible 2N7002 MOSFETs on the same SOT-23 pads). See also: [Espressif's Automatic Reset](https://qsantos.fr/2025/05/09/espressifs-automatic-reset/) for detailed explanation.

**Manual Override**:

The BOOT and RESET buttons (see Control Switches section) remain functional and can override the auto-reset circuit for manual bootloader entry when needed.

**Auto-Reset Bypass Links (R21, R26 — 470Ω)**:

Two inline links allow disabling the auto-reset circuit for debugging. Earlier
revisions used through-hole header+shunt jumpers (JP2/JP3), then 0Ω SMD links;
since v1.3 they are **470Ω** so they also limit the 2N7002 body-diode current
into the CH340C during button presses (see MOSFET body diodes above). 470Ω is
electrically transparent to auto-reset: EN/GPIO0 still reach ~0.15V against
their 10kΩ pull-ups, well below the 0.825V V_IL. JLCPCB places them at assembly
and the populated board stays low-profile.

```
CH340C DTR# ────[R21 470Ω]──── Auto-reset circuit (DTR side)
CH340C RTS# ────[R26 470Ω]──── Auto-reset circuit (RTS side)
```

| Link | Populated (default) | Removed |
|---|---|---|
| R21 | DTR connected, auto-reset enabled | DTR disconnected |
| R26 | RTS connected, auto-reset enabled | RTS disconnected |

- **Default configuration**: Both links populated. Auto-reset works normally for programming.
- **Debug configuration**: Desolder one or both links to use serial communication without triggering resets.

The board ships with R21 and R26 populated. (Note: the cross-coupled circuit ties each
transistor's emitter to the *opposite* DTR/RTS signal rather than to ground — verified
correctly wired in the H1.4 netlist review, but it is a finicky topology worth
confirming during bring-up.)

## Power Budget Analysis

### Current Consumption Estimates

**3.3V Rail Loads** (WiFi active, periodic IR transmission):

- ESP32 module: 80-120mA (WiFi idle)
- WiFi transmission peaks: 240mA for <1s bursts
- CH340C USB-UART bridge: ~15mA (active)
- IR receiver: 0.5mA
- BME280: 1.8µA (negligible)
- Status LEDs (6× @ 3mA): 18mA
- **3.3V rail total: ~345mA average, ~485mA peak**

**5V Rail Loads** (IR transmission):

- IR LEDs (4× @ 100mA, 30% duty cycle): 120mA average during active periods
- IR LEDs powered directly from 5V (not through buck converter)

**Buck Converter Power Analysis**:

- Input power (from USB): ~345mA × 3.3V / 0.92 efficiency = ~1.24W → 248mA @ 5V
- Peak input power: ~485mA × 3.3V / 0.92 = ~1.74W → 348mA @ 5V
- Buck converter power dissipation: ~0.09W at average load (vs 0.6W for LDO)
- Thermal performance: Minimal heat generation, TSOT26 package adequate without heatsinking

**Total USB Current Draw**:

- Average: 268mA (3.3V loads) + 120mA (IR LEDs) = ~388mA
- Peak: 376mA (3.3V loads) + 400mA (IR LEDs 100% duty) = ~776mA
- Well within USB-C 3A capability

### Voltage Rail Requirements

The board requires two voltage rails:

**5V Rail** (from USB-C):

- Powers IR LED driver circuits directly (for maximum LED brightness)
- Input to buck converter
- Available at header pins for 5V-tolerant peripherals
- Protected by PTC fuse and TVS diode

**3.3V Rail** (buck converter output):

- Powers ESP32 module via its 3V3 pin
- Powers IR receiver module
- Powers temperature sensor breakout board
- Powers status LEDs
- Maximum load: 2A continuous (AP63203 rated capacity)

## PCB Design Constraints

### Board Dimensions

The board SHOULD maintain dimensions approximately 100mm × 70mm (similar to Arduino Mega footprint) providing adequate spacing for through-hole components while fitting standard project enclosures. Exact dimensions may adjust based on final component layout.

### Layer Stack

A standard 2-layer PCB is REQUIRED:

- **Top Layer**: Component placement and signal routing
- **Bottom Layer**: Continuous ground plane with minimal signal routing

### Copper Requirements

**Power Traces**:

- USB 5V input: ≥25 mil (0.635mm) width
- Buck converter switching node (SW pin to inductor/diode): ≥30 mil (0.762mm) width, keep as short as possible
- 3.3V regulated output: ≥20 mil (0.508mm) width
- IR LED collector traces: ≥15 mil (0.381mm) width

**Buck Converter Critical Traces**:

- VIN to buck IC: ≥25 mil, keep input capacitor close
- SW (switching node): ≥30 mil, minimize length and area to reduce EMI
- Output (VOUT): ≥20 mil, place output capacitor close to load
- Ground connections: Use multiple vias to bottom ground plane

**Signal Traces**:

- General GPIO: 10 mil (0.254mm) minimum
- I2C lines (SDA/SCL): 12 mil (0.305mm) with matched lengths where practical

**Ground Plane**:

- Solid pour on bottom layer
- Top layer ground fills in unused areas
- Thermal reliefs on through-hole ground connections to enable soldering
- Buck converter ground connections: NO thermal reliefs (direct connection for low impedance)

### Component Spacing

Through-hole components MUST maintain minimum 2.54mm (0.1") spacing between adjacent component bodies to enable hand soldering with standard soldering irons. Pin headers SHOULD align on 2.54mm grid to support standard jumper wires and ribbon cables.

### Mounting Holes

The board MUST include four mounting holes (3.2mm diameter) positioned near corners, inset 5mm from board edges. These holes enable standoff mounting at standard 3mm spacing.

### Silkscreen Requirements

The silkscreen MUST clearly label:

- All pin headers with function (e.g., "GPIO21/SDA", "BAT+", "GND")
- Positive orientation for polarized components (LEDs, electrolytic capacitors, diodes)
- Reference designators for all components
- USB-C connector position and orientation
- Board revision number and date code

Component values MAY be omitted from silkscreen if space is limited, relying on reference designator cross-reference to BOM.

## Manufacturing Notes for JLCPCB

### PCB Specification

Order the PCB with the following JLCPCB standard options:

- Base Material: FR-4
- Layers: 2
- Thickness: 1.6mm
- Copper Weight: 1 oz (35µm)
- Surface Finish: HASL (lead-free) or ENIG if budget permits
- Silkscreen: White on green solder mask
- Remove Order Number: No (specify location if desired)

### Assembly Considerations

The board targets **JLCPCB SMT-only machine assembly** (top side only) with parts
sourced from **LCSC**, plus a **hand-solder kit** of loose parts ordered alongside.
The split is definitive and lives in one place — the `HAND_SOLDER` table in
`scripts/fab-outputs.py`, which generates the assembly BOM/CPL and the kit list
(`hardware/fab/esp32-ir-remote-hand-solder-kit.csv`) so they cannot drift apart.

The kit MUST contain every through-hole part (machine assembly cannot bend the IR
LEDs over the board edge at their fan angles, and THT lines carry both Extended
loading and per-joint fees) and SHOULD contain easy two-terminal SMD Extended parts
(TVS, polyfuse, power inductor) and optional connectors (Qwiic). Parts in the
series power path (USB-C receptacle, polyfuse, inductor, TVS) MUST be flagged
fit-before-first-power in the kit notes and in `hardware/bring-up.md`.

To minimize assembly cost, part selection MUST prefer JLCPCB **"Basic"** parts (kept
permanently loaded on the pick-and-place, no per-part feeder fee) over **"Extended"**
parts wherever a suitable Basic part exists. Where a choice forces an Extended part,
that SHOULD be noted with the reason — as of v1.4 the machine-placed Extended lines
are exactly three: the AP63203 buck regulator, the CH340C bridge, and the
ESP32-WROOM-32E module (no Basic equivalents exist). Every SMD component MUST carry
an LCSC part number and footprint in the schematic so the BOM and CPL export cleanly
to JLCPCB.

### Component Sourcing

All components SHOULD be sourced from LCSC. Prefer JLCPCB Basic parts (see above). Where
a required through-hole component is unavailable from LCSC, specify a Digikey/Mouser
alternative.

## Expansion and Future Provisions

### Deferred Features

Several previously-deferred provisions are now **implemented as on-board connection
points** (see [Connection Points and Expansion](#connection-points-and-expansion)):
the I2C Qwiic connector covers "additional I2C sensors", and the unpopulated JTAG
footprint covers hardware debug. The following remain genuinely deferred:

**Battery Charging Circuit** (deferred to v2):

Battery operation requires power-path management beyond simple charging (charger IC,
load-sharing, protection, reverse-polarity). It is more than a footprint and stays out
of v1. The spare-GPIO + power header exposes 3.3V and 5V rails, and JP1 disables the
internal buck converter, enabling external battery-circuit prototyping before
integrating into a future battery-capable board.

**External Antenna** (deferred):

The board retains the WROOM-32**E** module with its built-in PCB trace antenna — the
simplest, lowest-cost path, adequate for an in-room AC remote. Adding a U.FL external
antenna would require switching to the WROOM-32**UE** variant plus a U.FL footprint;
this is deferred unless WiFi range proves inadequate during bring-up.

**Additional I2C Sensors** — *now provided* via the Qwiic connector; no separate
per-sensor footprints are designed in (any I2C light/pressure/air-quality sensor or
OLED display attaches over Qwiic).

**JTAG Debug** — *now provided* as an unpopulated 2×5 footprint on GPIO12–15.

### Future Board Revisions

Subsequent board revisions MAY:

- Migrate to SMD components for reduced size
- Remove IR receiver (development-only component)
- Integrate battery charging circuit
- Reduce status LED count
- Minimize GPIO header exposure
- Integrate external antenna permanently

This development board intentionally over-provisions debugging and expansion features. Production boards will optimize for cost and size based on lessons learned during development.

## Bill of Materials

> **⚠️ This BOM lags the schematic and MUST be regenerated from it.** The KiCad
> schematic is the source of truth for reference designators and parts. The tables
> below were authored earlier and use stale designators (e.g. they list `J2` as the
> breakout header, whereas in the schematic `J2` is the USB-C receptacle; LED and
> resistor numbers also differ). Once the schematic carries an LCSC field on every
> symbol, regenerate the BOM with `kicad-cli sch export bom` (or the kicad MCP) and
> treat that export — plus `hardware/BOM.md`'s curated LCSC numbers, matched **by
> function, not by designator** — as the live BOM. The tables here are retained only
> for requirement intent (values, ratings, suggested parts), not designators. See
> ROADMAP H1.2.

This BOM specifies exact parts only where necessary for compatibility (e.g., ESP32 module pinout, USB-C connector footprint). For other components, requirements are listed with suggested parts.

**BOM Status**: Work in progress. The following items require confirmation after selecting specific vendor parts:

- **TVS diode (D1)**: Confirm polarity orientation (unidirectional vs bidirectional) based on selected part
- **Status LED resistors (R11-R16)**: Calculate values based on selected LED forward voltage to achieve 2-5mA target current
- **IR LED resistors (R3-R6)**: Verify 18Ω value against selected LED forward voltage for 100mA target

### Core Components

| Qty | Reference | Part/Requirement | Description | Package/Notes |
| --- | --- | --- | --- | --- |
| 1 | U1 | **ESP32-WROOM-32E-N4** | ESP32 WiFi+BT Module (4MB flash) | 38-pin castellated, 1.27mm pitch |
| 1 | U2 | **CH340C** | USB-to-UART Bridge IC | SOP-16 (1.27mm pitch) |
| 4 | LED1-LED4 | 940nm IR LED, ≥100mA | Suggested: TSAL6200 (Vishay) | 5mm through-hole |
| 1 | Q1 | **IRLML6344** | IR LED driver MOSFET (logic-level N-ch)  | SOT-23 |
| 2 | Q5-Q6 | **2N7002** N-channel MOSFET | Auto-reset circuit (schematic refs Q1/Q2) | SOT-23 |
| 1 | U3 | 38kHz IR Receiver | Suggested: TSOP1838, TSOP4838 (Vishay) | 3-pin through-hole module |
| 1 | U4 | DHT22 (AM2302) | Temperature/humidity sensor module | 3-pin through-hole module |
| 1 | J1 | USB-C Receptacle | Through-hole preferred for hand assembly | Through-hole |
| 1 | U5 | **AP63203** | Synchronous buck converter (fixed 3.3V)  | TSOT26 |

### Protection and Power

| Qty | Reference | Part/Requirement | Description | Package/Notes |
| --- | --- | --- | --- | --- |
| 1 | F1 | PTC Fuse, 1.1A/2A | Overcurrent protection | Through-hole or SMD |
| 1 | D1 | TVS Diode, 5.5-6.5V clamp | Overvoltage protection | DO-214AA or larger |
| 2 | R1-R2 | 5.1kΩ ±5% | USB-C CC resistors | 0805 or 1206 SMD |

### USB-to-UART Bridge Circuit

| Qty | Reference | Part/Requirement | Description | Package/Notes |
| --- | --- | --- | --- | --- |
| 1 | C9 | 100nF ceramic | CH340C V3 pin decoupling | 0805 or 1206 SMD |
| 2 | R23-R24 | 10kΩ 1/4W | Auto-reset base resistors | Axial or 1206 SMD  |

### Buck Converter Support Components

| Qty | Reference | Part/Requirement | Description | Package/Notes |
| --- | --- | --- | --- | --- |
| 1 | L1 | 4.7µH, Isat ≥2.7A, DCR <100mΩ | Power inductor for AP63203 (datasheet typical; better JLCPCB Basic stock than 3.9µH) | SMD 4x4mm or 5x5mm |
| 1 | C1 | 10µF ceramic, ≥10V | Buck input capacitor | 0805 or 1206 SMD |
| 2 | C2-C3 | 22µF ceramic, ≥10V | Buck output capacitors | 0805 or 1206 SMD |
| 1 | C4 | 100nF ceramic | Bootstrap capacitor (BST to SW) | 0603 or 0805 SMD |

### IR Transmitter Circuit

| Qty | Reference | Part/Requirement | Description | Package/Notes |
| --- | --- | --- | --- | --- |
| 4 | R3-R6 | 18Ω ≥0.25W | LED current limiting (~100mA) | Axial or 1206 SMD  |
| 1 | R7 | 10kΩ 1/4W | MOSFET gate series resistor | Axial or 1206 SMD  |
| 1 | R8 | 100kΩ 1/4W | MOSFET gate pull-down | Axial or 1206 SMD  |

### Status LEDs

| Qty | Reference  | Part/Requirement | Description | Package/Notes |
| --- | --- | --- | --- | --- |
| 1 | LED5 | LED (Green sugg.)  | Power indicator | 3mm or 5mm through-hole |
| 2 | LED6-LED7  | LED (Amber sugg.)  | Serial TX/RX indicators | 3mm or 5mm through-hole |
| 1 | LED8 | LED (Red sugg.) | IR transmit indicator | 3mm or 5mm through-hole |
| 2 | LED9-LED10 | LED (Blue sugg.) | User programmable | 3mm or 5mm through-hole |
| 6 | R11-R16 | Resistor, calc. | LED current limiting (2-5mA) | Calculated per LED Vf |

### Controls and Headers

| Qty | Reference | Part/Requirement | Description | Package/Notes |
| --- | --- | --- | --- | --- |
| 2 | SW1-SW2 | Tactile Switch, NO | RESET and BOOT buttons | Through-hole, 6×6mm typical |
| 2 | R17-R18 | 10kΩ 1/4W | Pull-up resistors (EN, GPIO0) | Axial or 1206 SMD |
| 1 | C10 | 1µF ceramic | EN pin RC delay capacitor | 0805 or 1206 SMD |
| 1 | — | 4-pin JST-SH (Qwiic) | I2C Qwiic/STEMMA-QT connector (GPIO21/22 + 3V3/GND) | 1.0mm SH; prefer JLCPCB Basic |
| 1 | — | 2×5 2.54mm header | Spare-GPIO + power header (GPIO25/26/32/33/34/23 + 3V3/5V/GND) | 2.54mm |
| 1 | — | 2-pin 2.54mm header | External IR-emitter header (+ series-resistor footprint) | 2.54mm |
| 1 | JP1 | 2-pad solder jumper | Buck converter disable (EN→GND) | SMD, open by default |
| 2 | R21, R26  | 470Ω SMD resistor | Auto-reset bypass links (DTR/RTS) + body-diode current limit, populated by default | 0603 SMD |

*(Designators marked "—" are assigned in the schematic; the 2×19 breakout header of
earlier revisions is removed.)*

### Optional Components (Unpopulated)

These components have PCB footprints but are not populated in initial builds:

| Qty | Reference | Part/Requirement | Description | Purpose/Notes |
| --- | --- | --- | --- | --- |
| 2 | — | 4.7kΩ SMD | I2C pull-ups for the Qwiic bus | Populate if attached module lacks its own |
| 1 | — | 2×5 2.54mm header | JTAG debug footprint (GPIO12–15 + 3V3/GND) | DNP; for ESP-PROG/OpenOCD |
| 1 | — | series resistor (IR) | External IR-emitter current limit | Populate when an external emitter is used |

*(U.FL external-antenna footprint is **not** designed in — the board keeps the
WROOM-32E PCB antenna; adding U.FL would require the WROOM-32UE variant. See Deferred
Features.)*

---

**Document Version**: 1.3
**Date**: 2026-06-11
**Author**: Development Team
**Status**: In Implementation - layout complete, fab outputs ready; auto-reset Q1/Q2 moved to 2N7002 MOSFETs (v1.3)

**Design Decisions Made**:
- ESP32 Module: ESP32-WROOM-32E-N4 selected for full control over support circuitry while using certified RF module (PCB antenna retained; U.FL/-32UE deferred)
- USB-to-UART Bridge: CH340C selected for hand-solderability (SOP-16), built-in oscillator, and low cost
- Auto-Reset Circuit: Cross-coupled 2N7002 N-channel MOSFETs (v1.3; pin-compatible swap from S8050 NPN BJTs, BOM-consolidated with Q4/Q5) with R21/R26 470Ω bypass links (debug disconnect + body-diode current limit)
- Voltage Regulation: AP63203 synchronous buck converter (L1 = 4.7µH) with disable jumper (JP1) for external power experimentation
- Protection: PTC fuse + TVS diode; USB D+/D- ESD protection omitted (adequate for dev board use)
- IR LED Driver: Single IRLML6344 logic-level MOSFET (SOT-23) with gate pull-down (gate series resistor ~330Ω–1kΩ, not 10kΩ); LEDs powered from 3.3V rail
- IR GPIO Assignment: GPIO18 (IR_TX), GPIO19 (IR_RX) - adjacent pins, avoids strapping pins
- Temperature Sensor GPIO: GPIO4 (TEMP_DATA)
- User LEDs: GPIO16 (USER_LED1), GPIO17 (USER_LED2)
- Temperature Sensor: DHT22 (AM2302) single-wire module replacing BME280
- Connection Points: 2×19 DevKitC breakout header REMOVED; replaced by I2C Qwiic (GPIO21/22), spare-GPIO + power header, external IR-emitter header, and an unpopulated JTAG footprint (GPIO12–15)
- Jumper Configuration: JP1 ships open (buck enabled); R21/R26 470Ω auto-reset links ship populated
- Assembly: JLCPCB PCBA from LCSC parts, preferring JLCPCB "Basic" parts; through-hole parts hand-soldered or via JLCPCB THT option; BGA excluded

**Remaining Implementation Tasks**:
- Footprint assignment for all schematic components
- PCB layout design following constraints in this specification
- BOM finalization with specific vendor part numbers (see BOM Status section for pending confirmations)

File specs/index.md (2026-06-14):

# Specifications Index

This directory contains technical specifications for the ActronAir IR Remote Control project.

## Hardware Specifications

- [Development Board v1.4](./hardware-dev-board-v1.md) - **⚠️ Superseded by the v2 ESP32-C3 redesign** (as-built: ESP32-C3-WROOM-02, AMS1117 LDO, AHT20 sensor, SMD USB-C; CH340C/JTAG/buck removed — see [`ROADMAP.md`](../ROADMAP.md)). The v1.4 doc describes the prior ESP32-WROOM-32E board: 4× IR emitter array, IR receiver, DHT22 temp/humidity, USB-C power (AP63203 buck), CH340C UART with cross-coupled auto-reset (2N7002 MOSFETs). Connection points: I2C Qwiic, spare-GPIO + power header, external IR-emitter header, unpopulated JTAG footprint (the large DevKitC breakout header was removed in v1.2). Targets JLCPCB SMT-only assembly (LCSC Basic parts, only 3 Extended lines machine-placed) plus a hand-solder kit for all THT and easy 2-terminal SMD parts.

The KiCad project in [`hardware/`](../hardware/) is the source of truth for the board design. Per-subsystem design rationale lives in [`hardware/notes/`](../hardware/notes/README.md), and `scripts/hardware-check.sh` runs ERC and regenerates the netlist after schematic changes.

## Protocol Documentation

See [re-findings.md](../re-findings.md) in the project root for comprehensive ActronAir IR protocol reverse engineering documentation including BOSCH144 and COOLIX protocol specifications.

---

**Last Updated**: 2026-06-11

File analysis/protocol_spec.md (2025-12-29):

# ActronAir IR Protocol Specification (BOSCH144)

## Overview
- **Protocol**: BOSCH144 (144 bits / 18 bytes)
- **Transmission**: Message sent 3× for redundancy
- **Structure**: State-based (complete AC state in every transmission)
- **Remote**: Compatible with multiple ActronAir remote models

## Byte Structure

```
Bytes 0-5:   First copy of state (header + temp + mode/fan bits)
Bytes 6-11:  Exact duplicate of bytes 0-5
Bytes 12-17: Footer (mode/fan/swing flags + checksums)
```

## Detailed Byte Map

| Byte | Function | Description |
|---|---|---|
| 0 | Header | Always 0xB2 |
| 1 | Header | Always 0x4D |
| 2 | Fan Speed (High) | Upper bits of fan encoding |
| 3 | Fan Speed (Low) | Lower bits of fan encoding |
| 4 | Temperature + Mode | Combined temp and mode encoding |
| 5 | Checksum | Bitwise inverse of byte 4 (~byte[4]) |
| 6-11 | Repeat | Exact duplicate of bytes 0-5 |
| 12 | Footer | Always 0xD5 |
| 13 | Fan Speed % | Direct fan percentage (or 0x66 for AUTO) |
| 14 | Temperature +0.5°C | 0x00=whole degree, 0x20=+0.5°C |
| 15 | Unknown | Usually 0x00 |
| 16 | Unknown | Usually 0x00 |
| 17 | Checksum | Likely checksum of footer bytes |

## Temperature Encoding

### Whole Degrees (Byte 4 - Base Component)
Temperature uses a **lookup table** (non-linear encoding):

| Temp (°C) | Byte 4 (COOL mode) | Byte 4 (hex) | Binary |
|---|---|---|---|
| 16 | 0 | 0x00 | 0000 0000 |
| 18 | 16 | 0x10 | 0001 0000 |
| 20 | 32 | 0x20 | 0010 0000 |
| 21 | 96 | 0x60 | 0110 0000 |
| 22 | 112 | 0x70 | 0111 0000 |
| 23 | 80 | 0x50 | 0101 0000 |
| 24 | 64 | 0x40 | 0100 0000 |
| 25 | 192 | 0xC0 | 1100 0000 |
| 26 | 208 | 0xD0 | 1101 0000 |
| 27 | 144 | 0x90 | 1001 0000 |
| 30 | 176 | 0xB0 | 1011 0000 |

**Note**: Values above are for COOL mode. Other modes add mode bits to byte 4 (see Mode Encoding).

### Half Degree (Byte 14)
- `0x00` = whole degree (e.g., 20.0°C)
- `0x20` = add 0.5°C (e.g., 20.5°C)

### Temperature Range
- **COOL mode**: 16°C - 30°C (may vary by model)
- **Other modes**: Range may differ

## Mode Encoding

Modes are encoded in **bytes 2-3** and **byte 4** (mode bits added to temperature value):

### Byte 2-3 Patterns
- **Group A** (0xBF, 0x40): COOL, HEAT, FAN
- **Group B** (0x1F, 0xE0): DRY, AUTO

### Byte 4 Mode Bits (at 20°C example)
| Mode | Byte 4 | Binary | Mode Bits |
|---|---|---|---|
| COOL | 0x20 | 0010 0000 | (base) |
| DRY  | 0x24 | 0010 0100 | bit 2 |
| HEAT | 0x2C | 0010 1100 | bits 2+3 |
| FAN  | 0xE4 | 1110 0100 | bits 2+5+6+7 |
| AUTO | 0x28 | 0010 1000 | bit 3 |

**Pattern**: Mode bits are **OR'd** with the base temperature value.

### Complete Mode Map
| Mode | Bytes 2-3 | Byte 4 (20°C) | Byte 13 |
|---|---|---|---|
| COOL | 0xBF, 0x40 | 0x20 | varies by fan |
| DRY  | 0x1F, 0xE0 | 0x24 | varies by fan |
| HEAT | 0xBF, 0x40 | 0x2C | varies by fan |
| FAN  | 0xBF, 0x40 | 0xE4 | varies by fan |
| AUTO | 0x1F, 0xE0 | 0x28 | varies by fan |

## Fan Speed Encoding

Fan speed is encoded in **bytes 2-3** and **byte 13**:

### Byte 13 - Direct Percentage
| Fan Speed | Byte 13 (hex) | Byte 13 (decimal) |
|---|---|---|
| AUTO | 0x66 | 102 |
| 20% | 0x14 | 20 |
| 40% | 0x28 | 40 |
| 60% | 0x3C | 60 |
| 80% | 0x50 | 80 |
| 100% | 0x64 | 100 |

**Pattern**: Byte 13 = fan percentage in decimal (except AUTO = 0x66)

### Bytes 2-3 - Fan Encoding
| Fan Speed | Byte 2 | Byte 3 | Bytes 2-3 |
|---|---|---|---|
| AUTO | 0xBF | 0x40 | 10111111 01000000 |
| 20% | 0xFF | 0x00 | 11111111 00000000 |
| 40% | 0x9F | 0x60 | 10011111 01100000 |
| 60% | 0x5F | 0xA0 | 01011111 10100000 |
| 80% | 0x3F | 0xC0 | 00111111 11000000 |
| 100% | 0x3F | 0xC0 | 00111111 11000000 |

**Note**: 80% and 100% share same bytes 2-3 (0x3F, 0xC0), differentiated only by byte 13.

## Swing / Air Direction

**Finding**: SWING button does **NOT** send standalone IR signals.

Swing may be:
- A local remote display feature only
- Encoded within other command transmissions (not yet identified)
- Model-specific feature not present in all remotes

## Checksums

### Byte 5
- **Always** bitwise inverse of byte 4: `byte[5] = ~byte[4]`
- Validates temperature + mode encoding

### Byte 17
- Appears to be checksum of footer bytes (12-16)
- Algorithm not yet fully reverse-engineered
- Changes with byte 13, 14, and other footer bytes

## Example State Decoding

### Example 1: Cool 24°C, Fan AUTO
```
State: {0xB2, 0x4D, 0xBF, 0x40, 0x40, 0xBF, 0xB2, 0x4D, 0xBF, 0x40, 0x40, 0xBF, 0xD5, 0x66, 0x00, 0x00, 0x00, 0x39}

Byte 0-1: 0xB2, 0x4D (header)
Byte 2-3: 0xBF, 0x40 (Group A - COOL/HEAT/FAN)
Byte 4: 0x40 (temp 24°C in COOL mode)
Byte 5: 0xBF (checksum: ~0x40 = 0xBF ✓)
Byte 6-11: Repeat of 0-5
Byte 12: 0xD5 (footer)
Byte 13: 0x66 (Fan AUTO)
Byte 14: 0x00 (whole degree, not +0.5°C)
Byte 17: 0x39 (checksum)

Decoded: COOL mode, 24.0°C, Fan AUTO
```

### Example 2: Heat 20.5°C, Fan 60%
```
State: {0xB2, 0x4D, 0x5F, 0xA0, 0x2C, 0xD3, 0xB2, 0x4D, 0x5F, 0xA0, 0x2C, 0xD3, 0xD5, 0x3C, 0x20, 0x00, 0x00, 0x??}

Byte 2-3: 0x5F, 0xA0 (Fan 60%)
Byte 4: 0x2C (0x20 temp base + 0x0C HEAT mode bits)
Byte 5: 0xD3 (checksum: ~0x2C = 0xD3 ✓)
Byte 13: 0x3C (60 decimal = Fan 60%)
Byte 14: 0x20 (+0.5°C)

Decoded: HEAT mode, 20.5°C, Fan 60%
```

## Implementation Notes

### Encoding a Command
1. Start with header: `0xB2, 0x4D`
2. Set bytes 2-3 for fan speed (see fan table)
3. Look up temperature base value from table
4. Add mode bits to temperature value → byte 4
5. Calculate byte 5 = ~byte 4
6. Duplicate bytes 0-5 to bytes 6-11
7. Set byte 12 = 0xD5
8. Set byte 13 = fan percentage (or 0x66 for AUTO)
9. Set byte 14 = 0x00 (whole) or 0x20 (+0.5°C)
10. Set bytes 15-16 = 0x00
11. Calculate byte 17 checksum (TBD algorithm)

### Decoding a Capture
1. Verify byte 0-1 = 0xB2, 0x4D (valid header)
2. Verify bytes 6-11 match bytes 0-5 (redundancy check)
3. Verify byte 5 = ~byte 4 (checksum)
4. Read byte 13 for fan speed percentage
5. Read bytes 2-3 to determine mode group
6. Read byte 4 and lookup temperature from table
7. Read byte 14 for +0.5°C flag

## Testing Coverage

✅ Temperature: 16-30°C in 0.5°C increments
✅ Modes: COOL, DRY, HEAT, FAN, AUTO
✅ Fan Speeds: AUTO, 20%, 40%, 60%, 80%, 100%
✅ Swing: Confirmed no standalone IR signal
⚠️ Power: Not yet tested (likely separate command)
⚠️ Other features: Boost, LED, Humidity, Timer (if present)

## Known Limitations

1. **Temperature lookup table incomplete**: Only tested 16-30°C range
2. **Byte 17 checksum algorithm**: Not fully reverse-engineered
3. **Swing encoding**: Not identified (may not be transmitted)
4. **Mode-specific temperature ranges**: Not fully tested
5. **Power ON/OFF**: Separate command format (if different)

## Hardware Used

- **ESP8266 NodeMCU** with CHQ1838 IR receiver
- **ActronAir Remote** (multiple models tested)
- **IRremoteESP8266 library** for protocol decoding

## Capture Date

Initial reverse engineering: 2025-12-28

---

*This specification is based on empirical testing and may not cover all edge cases or remote models.*

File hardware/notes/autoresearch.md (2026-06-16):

# Autoresearch loop for board layout + routing

> Nick (2026-06-16): "take a look at Andrej Karpathy's autoresearch project and
> see if there's anything we might try to replicate here in terms of iteratively
> improving the board layout and routing. I'm happy to give you plenty of time
> to iterate. Also if it helps we can totally remap GPIO — I don't care what
> pins we use."

## What Karpathy's autoresearch is

[autoresearch](https://github.com/karpathy/autoresearch) (released 2026-03) is a
**ratchet loop** for autonomous ML research. Three-file contract:

| File | Owner | Role |
|---|---|---|
| `prepare.py` | nobody (immutable) | data + the **single fitness metric** (`val_bpb`). Never edited, so every experiment is measured identically. |
| `train.py` | the agent | the ~630-line artifact under optimisation (model + training loop). The agent rewrites it freely. |
| `program.md` | the human | research directions, constraints, exact run commands, and the rule **"NEVER STOP — don't pause to ask the human."** |
| `results.tsv` | the harness | audit trail: commit, score, pass/fail, description. The agent reads it to inform the next hypothesis. |

The **loop**: read `program.md` + `results.tsv` → propose a hypothesis → edit
`train.py` → run a **fixed-budget** experiment → evaluate the one metric → **keep
the commit if it improved, else `git reset` it**. Unidirectional: experiments
either advance the artifact or vanish. The LLM is *both* the mutation operator
(proposes edits) *and* the selection pressure (decides what to try from history);
the harness only enforces the immutable metric + the budget. ~12 experiments/hr.

## The 1:1 mapping onto this board

We already had the **dumb** version of this (`pcb_search.py`: random `rng.choice`
over placement zones — an AutoML fixed parameter space). Autoresearch's lessons
upgrade it on two axes: a wider, *physically-meaningful* search space, and an
*intelligent, history-aware* mutation operator instead of a random sampler.

| autoresearch | here | artifact |
|---|---|---|
| `prepare.py` (immutable metric) | the route+legality+score **oracle** | `pcb_experiment.py` runs `floorplan → gpio_remap → place_v2 → rip → route_fr → pour → DRC → pcb_score`. FreeRouting is the routability oracle (~12 s, deterministic), `pcb_score` the fitness, kicad-cli DRC the legality gate. **Edit only with care — it is the ruler.** |
| `train.py` (editable artifact) | the **candidate spec** = floorplan anchors **+ GPIO→pad assignment** | `pcb_floorplan.ANCHORS` + a GPIO map (`pcb_gpio_remap.py`). Nick opened up GPIO remap, which is the big new degree of freedom (below). |
| `program.md` (direction + protocol) | this note's **Protocol** section | goal, hard constraints, run commands, ratchet rule. |
| `results.tsv` | experiment log | `hardware/fab/experiments.jsonl` (gitignored; one line per candidate: tag, score, drc, unrouted, usb metrics, the spec). |
| the LLM (mutation + selection) | **the agent driving the loop** | reads the log + the routed board's *which-nets-are-unrouted/long*, reasons geometrically, proposes the next spec. This is the faithful replication — the agent IS the loop, exactly as autoresearch uses an external LLM to edit `train.py`. |
| keep-if-better ratchet | keep the best board aside, restore pristine otherwise | the driver keeps `/tmp/ar_best.kicad_pcb`; the working tree stays pristine until a winner is finalised through the normal ritual. |

## The new lever: GPIO remap (Nick unlocked it)

On a 2-layer board, routability is dominated by **which module pad each net
attaches to** — a signal whose module pad faces *away* from its peripheral zone
forces a crossing (this is exactly why the USB pair is stuck: IO18/IO19 are
hardware-fixed and face away from the USB-C). The ESP32-C3's GPIO matrix means
*almost every peripheral function can be assigned to almost any GPIO*, so we can
permute net→pad to make each signal exit the side facing its zone.

U3 (ESP32-C3-WROOM-02) pad map (from the netlist), classed by remappability:

| class | pads (GPIO) | nets | search role |
|---|---|---|---|
| **free** | 3(IO4) 4(IO5) 5(IO6) 6(IO7) 10(IO10) 15(IO3) | USER_LED2, IR_TX, IR_RX, SDA, SCL, USER_LED1 | permute freely |
| **spare** | 11(IO20) 12(IO21) 17(IO1) 18(IO0) | SPARE_RX/TX/IO1/IO0 → J4 | permute (J4 just breaks out whatever lands here) |
| **strap** | 7(IO8) 16(IO2) | strap pull-ups | leave fixed (boot-level risk) |
| **fixed** | 1(3V3) 2(EN) 8(IO9/BOOT) 9/19(GND) 13(IO18/USB-) 14(IO19/USB+) | power / reset / boot / USB | never touch (USB is hardware) |

So 6 peripheral signals (and 4 spares) permute over 10 pads spread across all
four module edges. The placement re-seat (`pcb_place_v2`) is **net-driven**, so
it automatically re-clusters each peripheral's support parts (R13/R19, pull-ups,
RC) against the new pad — remap + re-place is self-consistent.

**Caveat — reflecting a remap into the sources of truth.** A GPIO remap is a real
schematic change (a different module pad wired to the peripheral) + a firmware
`build_flags` change. The *search* manipulates PCB net assignments in-container
(cheap routability probing); a *winning* remap is then reflected as: firmware
`-D *_PIN=` (trivial), schematic net reattach (KiCad GUI / Mac, or a validated
surgical script), netlist regen → CI parity. The search's job is to prove a
remap is worth that reflection before we spend it.

## Protocol (the "program.md")

**Goal.** Minimise `pcb_score` on a **2-layer** board subject to the hard gates
**0 DRC errors + 0 unrouted**, with a strong preference for **USB D± on F.Cu, 0
vias** (the SI win that motivated the whole U3-rotation thread). Beat the merged
baseline (USB-on-B.Cu 56 mm, score ~710).

**Hard constraints (never violated by a candidate).**
- 2 layers only (no 4-layer escape).
- Physics-fixed anchors stay put: antenna over a board edge (RF keepout clear),
  IR LED fan firing E, TSOP lens clear of the fan, USB-C on the edge by U3's USB
  pads.
- USB pads 13/14 (IO18/19) never remapped; strap/boot/power pads never remapped.

**Run commands.**
```bash
export JAVA25=/tmp/fr/jdk-25.0.3+9-jre/bin/java
export FREEROUTING_JAR=/tmp/fr/freerouting-2.2.4.jar
# one candidate (floorplan from pcb_floorplan.ANCHORS, optional gpio map json):
/usr/bin/python3.12 scripts/pcb_experiment.py --tag <name> [--gpio gpio.json]
# logs a line to hardware/fab/experiments.jsonl, keeps best at /tmp/ar_best.*
```

**Loop (the agent runs this, NEVER STOP mid-search).**
1. Read `experiments.jsonl` + the last routed board's unrouted/long nets.
2. Form a hypothesis: a placement nudge and/or a GPIO swap that removes a
   specific crossing (geometric reasoning, not random).
3. Edit the spec (ANCHORS and/or the gpio map), run `pcb_experiment.py`.
4. Ratchet: if score improved (and gates pass) keep it as the new base; else
   discard and try the next hypothesis.
5. Repeat until a candidate clears the gates with USB on F.Cu, or the space is
   demonstrably exhausted (then report the best + why).

**Finalise the winner** through the normal ritual (ldo_pour, silk, stamp,
`hardware_validate.py`, baseline refresh in `kicad/kicad:10.0.2`), render for a
human serviceability call, and write up the GPIO-remap reflection (firmware +
schematic) if the win needed one.

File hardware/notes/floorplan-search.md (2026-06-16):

# Generative floorplan search

> Bold approach to "find a better layout" (Nick, 2026-06-15): stop hand-nudging
> anchors — **generate many candidate floorplans, route each with FreeRouting,
> score the routed result, and rank.** FreeRouting (~10 s/board, deterministic)
> is the routability *oracle*; `scripts/pcb_score.py` is the fitness function.
> This orchestrates the mature tools we already use (pcbnew place / FreeRouting
> route / kicad-cli DRC) — it does **not** reinvent routing or DRC, so it clears
> the CLAUDE.md "stand on giants / has a machine validator" bar.

## Pieces

| Script | Role |
|---|---|
| `scripts/pcb_score.py` | Read a *routed* board, emit a quality vector + scalar (lower = better): USB-on-B.Cu length + vias, B.Cu signal slotting, total track/via, decoupling distance, sensor↔heat separation. |
| `scripts/pcb_floorplan.py` | `apply_anchors(b, anchors, holes, draw_outline)` places a candidate anchor dict (refactored out of Phase A `main()`). |
| `scripts/pcb_place_v2.py` | Phase B support re-seat (ASSIGN map) — reused per candidate. |
| `scripts/pcb_search.py` | The driver: generate → legalize → route → DRC-gate → score → rank. |

## Search space

Physics-fixed anchors are **never moved** (only treated as obstacles): the
antenna/MCU at the N long edge, USB-C at the W short edge, the IR LED fan firing
E, the TSOP on the S edge, the VBUS chain in the W power zone. The search varies
the **flexible** groups Nick flagged:

- status-LED row (D6/D7/D10/D11/D12): zone + orientation
- buttons (SW1/SW2): zone
- J4 spare header: zone (incl. "under the ESP")
- LDO group (U1): NW corner vs. NW
- sensor (U5): far-from-heat corner (SE vs. E)

plus ±0.6 mm jitter. Two named candidates always run: **baseline** (the merged
floorplan — a control that must reproduce its exact score) and **user_hyp**
(Nick's LEDs+buttons-bottom-left / J4-under-ESP / LDO-alone idea).

## Per-candidate pipeline (each stage its own process — SWIG-safe)

```
copy pristine board → _apply (place anchors + LEGALIZE flex off collisions +
outline) → pcb_place_v2 (re-seat support) → pcb_rip → FreeRouting
(export/route/import) → pcb_pour (GND) → kicad-cli DRC → pcb_score
```

Hard gates: **0 DRC errors + 0 unconnected** (illegal candidates are scored
below every legal one). The **legalizer** (`_legalize`) spiral-nudges each flex
anchor to the nearest collision-free slot near its zone target (reusing
`pcb_place_v2`'s courtyard/overlap/keepout helpers) so a chosen zone arrangement
becomes a *legal* placement before routing — without it every rearrangement
collided.

## Run

```bash
JAVA25=/tmp/fr/jdk-25*/bin/java FREEROUTING_JAR=/tmp/fr/freerouting-2.2.4.jar \
  /usr/bin/python3.12 scripts/pcb_search.py <N> <seed>
# results -> hardware/fab/search_results.json (gitignored); best -> /tmp/search_best.kicad_pcb
```

The winner is a *placement*; finalize it through the normal route ritual
(ldo_pour, silk, DRC, `hardware_validate.py`, baseline refresh in
`kicad/kicad:10.0.2`) and **render the top few for a human serviceability call**
(the scorer rewards SI/routability, not button reachability or aesthetics).

## Results (2026-06-15, N=40 + item-2 probe)

**Verdict: the merged 2-layer floorplan is already near-optimal; the board is
the constraint, not the placement.**

- Of 40 candidates only **3 were DRC-legal**; the best (`rand31`, score **687.9**
  vs baseline **709.7**, ~3 %) differs from baseline in **one** way — the **LDO
  tucked into the NW corner** (everything else identical), which trims
  USB-on-B.Cu 56→49 mm and decoupling distance. That margin is within the
  run-to-run jitter noise (the same zone combo scored 619 legal in one pilot and
  6553 illegal in another when ±0.6 mm jitter tipped a tight courtyard) — i.e.
  not a robust win, not worth churning the board + re-baselining for.
- Nick's "everything bottom-left + J4 under the ESP" hypothesis routed **worse /
  illegal** — a 5-LED row + 2 buttons + caps don't fit cleanly in the SW corner.
- **Item 2 (USB → F.Cu) does NOT yield to a keepout here (hard data).** Forcing
  the pair off B.Cu pushed USB-on-B.Cu **49→108 mm with +1 unrouted** — strictly
  worse. Root cause is geometric: U3's USB pins (IO18/IO19) sit on the module's
  **east** side (x≈158) facing *away* from the **west** USB-C (J2, x≈113), so the
  shortest path ducks **under the module on B.Cu** (F.Cu is blocked by the module
  pads; N is the antenna keepout). The B.Cu run is the natural optimum and is
  functional for full-speed USB (note: `autorouting-freerouting.md`). `pcb_usb_keepout.py`
  is kept for the record / a future 4-layer board.

**Real levers (for a future re-spin, where the search has room):**
1. **Module orientation/placement** so the C3's USB pins face J2 — the only
   placement fix for the USB pair, but it moves the antenna off the N edge
   (RF implications — needs care).
2. **4-layer board** (dedicated GND plane + coupled D+/D−) — already the
   documented next-rev lever; the search tooling will have real degrees of
   freedom there (layer assignment, module rotation).

## Notes / limits

- The scorer rewards USB-on-F.Cu but placement alone can't force it to 0 vias —
  that needs the B.Cu-keepout / per-net layer rule (brief item 2). Run that on
  the chosen winner.
- Weights in `pcb_score.WEIGHTS` are for *ranking*, not physical units — tune
  them if priorities shift.
- Determinism: FreeRouting is single-threaded sequential (no seed needed); the
  generator's RNG is seeded, so a run is reproducible.

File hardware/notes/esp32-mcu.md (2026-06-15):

# ESP32 MCU

> ⚠️ **v2 (as-built): ESP32-C3-WROOM-02-N4** (LCSC C2934560), swapped in during
> the v2 cost-down redesign — see the v2 change set in
> [`ROADMAP.md`](../../ROADMAP.md). The C3 has a **native USB-Serial-JTAG**
> controller, so the CH340C bridge + auto-reset FETs were deleted (flash/monitor
> run straight over USB-C). The WROOM-32E rationale below is retained for v1
> history; where it disagrees with the schematic, the schematic wins.

ESP32-WROOM-32E-N4 module (WiFi+BT, 4MB flash) used directly rather than as a
dev board — the module integrates antenna, crystal, and RF matching, so the
board only needs to supply power, boot configuration, and GPIO breakout.

## Power and decoupling

3.3V supply with 100nF close to the VDD pin (high-frequency decoupling) plus
10µF bulk for load transients. WiFi TX bursts are the demanding case; the
spec budget allows ≤100mV droop at the module pins.

## Boot configuration (strapping pins)

| Pin | Requirement at boot | Provision |
|-----|---|---|
| EN | HIGH for normal operation | 10kΩ pull-up + 1µF to GND (RC ≈ 10ms power-on reset delay); auto-reset Q1 can pull LOW |
| GPIO0 | HIGH = flash boot, LOW = download mode | 10kΩ pull-up; auto-reset Q2 / BOOT button pull LOW |
| GPIO2 | LOW or floating | 10kΩ pull-down |
| GPIO15 | sets UART debug output | 10kΩ pull-down — deliberately suppresses boot ROM messages |

## Manual buttons

- **RESET (SW1):** pulls EN low. Recovery from crashed firmware.
- **BOOT (SW2):** pulls GPIO0 low. Hold BOOT, press RESET, release both to
  force download mode if auto-reset fails.

## Expansion connectors

The original 2×19 DevKitC-style breakout header (J1) was removed in the v1.2
change set — it dominated routing for little benefit and exposed the module's
internal flash pins (GPIO6–11). Expansion is now:

- **J4 spare-GPIO header (2×5):** 3V3, 5V, GPIO23/32/33/34, 2× GND.
  GPIO25/26 were sacrificed to routing congestion during layout (pins NC'd at
  the module). Note **GPIO34 is input-only** (no output driver, no internal
  pulls) — don't try to drive it.
- **On-board I²C (v2):** the AHT20 sensor (U5) sits on the C3's I²C bus —
  SDA = IO7, SCL = IO10 — with **populated** 4.7 kΩ pull-ups (R28/R29). The
  bus is also broken out on J4. (v1's separate J3 Qwiic connector was dropped;
  the GPIO21/22 mapping above was the WROOM-32E's.)
- **J6 JTAG (2×5, DNP):** ARM 10-pin layout, EN wired as nRESET.

The exposed power rails on J4 are the hook for v2 battery/power experiments
on an external board (with JP1 disabling the onboard buck).

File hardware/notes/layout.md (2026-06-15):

# PCB Layout Constraints (H2.1)

> ⚠️ Predates the **v2 ESP32-C3 redesign** (see [`ROADMAP.md`](../../ROADMAP.md)).
> The WROOM-32E antenna-keepout constraint below still applies in spirit to the
> C3 module (U3), but exact references are v1; the schematic/PCB win.

Placement and routing constraints for the v1.2 board. Written before any
placement so layout (H2.2+) is execution against a checklist, not
improvisation. Board design rules and net classes live in the KiCad project
(`.kicad_pro` net_settings + board rules) — this note records *why* and the
constraints that rules can't express.

## Stackup & fab rules (set in project, 2026-06-11)

- JLCPCB 2-layer, 1oz copper. Board minimums: clearance 0.15 mm, track
  0.15 mm, via 0.5/0.3 mm, through-hole drill 0.3 mm, copper-to-edge 0.3 mm.
  (JLCPCB's absolute floor is 0.127 mm/5 mil; we keep margin.)
- Net classes:
  - **Power** (0.6 mm track, 0.8/0.4 via): `+5V`, `+3.3V`, `GND`,
    `Net-(U1-SW)`, `Net-(F1-Pad2)` — sized for ~400 mA IR pulses + WiFi
    peaks (≥0.5 mm @1oz handles 1 A+ with trivial rise).
  - **IR_Drive** (0.5 mm): `IR_DRAIN`, `EXT_IR_A`, `Net-(D2-A..D5-A)` —
    each LED string pulses ~100 mA; the shared drain return carries all four.
  - Default 0.2 mm for signals.

## Placement constraints (hard)

1. **WROOM-32E antenna keepout (U3):** module at a board edge, antenna
   section overhanging or flush with the edge; **no copper on any layer
   under the antenna** (the section past the module's shield can), and keep
   other components ≥5 mm from the antenna zone. KiCad's footprint shows the
   keepout outline — respect it on both layers and in the GND pour.
2. **IR LEDs (D2–D5, THT, 5 mm) on the board edge**, each bent 90° at
   solder time to lie horizontal and fire outward over the edge, fanned at
   −67.5°/−22.5°/+22.5°/+67.5° from the edge normal (TSAL6200 half-intensity
   beam is ±17°, so 45° splay covers a ~170° arc — the spec's 180°
   requirement leans on wall reflections at the extremes, per
   ir-transmitter.md). Footprints sit ≥4 mm behind the edge for the bend
   radius, rotated to their fan angle, with silkscreen aim guides. Each LED
   is an independent string (own 18Ω resistor from +3.3V, all cathodes to
   `IR_DRAIN`) — they are NOT series pairs. Hand-soldered; leave finger room.
3. **AMS1117 LDO (U1) caps tight (v2 — no buck):** the v2 board uses a
   SOT-223 AMS1117-3.3 linear LDO, NOT the v1 AP63203 buck — there is no
   inductor or SW node. Place the input cap (C1) hard against VIN/GND and the
   **10 µF output cap within ~3 mm of VOUT** (PSRR/transient for the C3 WiFi
   bursts — SI review). No switching loop / SW-keepout applies any more.
4. **USB-C (J2) native USB (v2 — no CH340C):** v2 uses the C3's native USB
   PHY (the CH340C bridge is gone). J2 on the board edge; route D+/D− as a
   tight pair on F.Cu over continuous ground, < 30 mm, no layer
   change if possible. ESD/TVS (D1) and fuse (F1) sit between J2 and the
   rest: order on VBUS must be J2 → F1 → D1 → U1 (fuse before TVS,
   per H1.4).
5. **AHT20 (U5) away from heat (v2 — was DHT22):** the v2 sensor is the
   **AHT20 I²C** part (SCL = C3 IO10, SDA = C3 IO7; bus also broken out on
   header J4), NOT the v1 AM2302/DHT22 single-wire part. Place it the maximum
   practical distance from U1 (LDO) and U3 (WiFi heat); prefer a board corner
   with slots/perimeter routing between it and heat sources if space allows.
   Sensor must sample room air, not board air. Its 100 nF decoupling and the
   I²C pull-ups (R28/R29, 4.7 kΩ, populated) travel with it — see constraint 10.
6. **TSOP receiver (U4) faces the user/room AND keeps its distance from the
   TX array (revised 2026-06-14):** board edge, lens unobstructed; its RC
   filter (R27/C9, net `IR_RX_VS`) directly at the Vs pin. **Hard separation:
   ≥20 mm from Q3 and from *every* IR LED (D2–D5).** Rationale: U4 is a
   dev/debug part used both to capture fresh reference signals from the OEM
   remote and to self-validate our own TX. The earlier east-corner placement
   put it ~11 mm from D2 and ~19 mm from Q3 — that is *near-field*: the TSOP's
   wide (~±45°) acceptance cone + enclosure reflection saturate its AGC during
   TX, so self-validation reads a clipped blob, not recoverable mark/space
   timing, and the receiver (the most EMI-sensitive part on the board) sits in
   the 400 mA / 38 kHz drive loop's near field. **As-built (2026-06-14):** U4
   moved to the **south long edge at (153.0, 110.5), rot 180 so the lens fires
   south (+y, outward)**, between the MCU and the U5 sensor; the Vs RC filter
   sits in-line to its west — C9 at (144.5, 110.5), R27 at (140.0, 110.5).
   Achieved separation: **31 mm to Q3, 34–46 mm to D2–D5**, 44 mm to USB. At
   that distance it still hears its own TX via room/enclosure bounce (good for
   "did it fire + coarse timing") without saturating. Re-routed via the
   standard pipeline (rip → router → stub_heal → pour); DRC = 0 errors (the
   lone unconnected is the pre-existing accepted USB_D+ J2/A6 item, unrelated).
   **Enclosure: add an optical baffle rib between the TX window (east) and the
   RX window (south) in the 3D print.** Tight near-field loopback timing, if
   ever wanted, is a job for an external aimed RX (breadboard-style), not the
   onboard window.

## Placement constraints (soft / serviceability)

7. **Connection points on edges:** J3 (Qwiic JST-SH) on an edge for cable
   access; J4 (spare-GPIO 2×5) and J6 (JTAG 2×5, DNP) in reachable positions
   with pin-1 marked; J5 (ext-IR, DNP) near the IR array edge.
8. **Buttons (SW1 RESET, SW2 BOOT)** on the same edge/face, reachable when
   the board is on a bench with USB plugged in; don't put them under the
   antenna end.
9. **Status LEDs (D6–D12)** visible from one viewing angle; group serial
   TX/RX (D8/D9) together; user LEDs (D11/D12) together. THT 3 mm,
   hand-soldered.
10. **Decoupling (v2 — U2/CH340C and C4 deleted):** the +3.3V rail carries
    **two identical bypass banks, one per IC** — *not* a duplication bug.
    There are two consumers on the rail: U3 (the C3 module) and U5 (the AHT20),
    so each gets a 100 nF + 10 µF pair (C5/C7 are the 100 nF, C8/C10 the 10 µF;
    all four sit on +3.3V↔GND, so the exact ref↔IC assignment is free — Phase B
    picks by shortest route).
    - **U3 (ESP32-C3):** 100 nF + 10 µF hard against the 3V3 pin (pin 1); the
      100 nF gets the shorter loop. The module courtyard bounds the caps to
      ~7 mm on this 2-layer board (accepted — see ROADMAP; the module also has
      internal decoupling).
    - **U5 (AHT20):** 100 nF at VDD (pin 2); the second 10 µF rides along as
      local rail bulk. (The AHT20 strictly needs only the 100 nF — the 10 µF is
      generous; keep for rail stiffness or drop to save a part.)
    - **As-built the placer scattered these** (both 10 µF landed at U3, both
      100 nF orphaned ~50 mm SW, U5 left with no local cap). **Phase B must
      re-pair one bank to each IC.**
    - **C6 (1 µF) is NOT a decoupling cap** — it is U3's EN power-on-reset RC
      (with the 10 kΩ EN pull-up, ~10 ms POR delay) at the EN pin. (The old
      "CH340C V3" note was wrong; that chip is gone.)
    - LDO caps (C1 at VIN; C2/C3 at VOUT) are covered by constraint 3.
11. **No jumpers / no auto-reset links (v2):** JP1 (LDO-disconnect), the
    R21/R26 auto-reset 0 Ω links, and the Q1/Q2 reset FETs were all **deleted**
    in v2 — the C3's native USB-Serial-JTAG handles reset/boot/download over
    USB-C, and the rail runs from the single LDO (desolder U1 to bench-inject).
    Silkscreen pin-1 / button labels still required (H2.4).

## Layer policy (signal vs power on a 2-layer GND-pour board)

The rule for what drops to B.Cu when a power trace and a signal trace must
cross on F.Cu:

- **Keep the high-frequency / sensitive signal contiguous on F.Cu; dip the
  POWER trace to B.Cu to cross — short and perpendicular.** The signal needs
  the intact GND plane directly beneath it as its return reference; a DC power
  trace does not (it carries current at ~0 Hz and only wants copper + low IR
  drop). Routing the *signal* on B.Cu instead would strip its reference (B.Cu's
  "reference" up on F.Cu is signals/power, not a plane) and add via
  discontinuities — all to a trace whose edges are the thing that cares.
- The one cost of a B.Cu power dip is that it **slots the GND pour** for its
  length, forcing return currents of any signal crossing that slot to detour.
  So keep the dip short, cross perpendicular, **flank it with GND stitching
  vias**, and never run a long power trace on B.Cu. Priority order: (1) signal
  on F.Cu over solid GND, (2) power on F.Cu if it can, (3) when they must
  cross, power takes the short B.Cu dip — never the signal.
- On *this* board the stakes are modest (38 kHz IR carrier; fastest edges are
  the C3's digital/flash/crystal, not controlled-impedance nets), but the
  discipline is free and pays off for WiFi-adjacent and IR_RX nets.

**Autorouter rulesets — what's standard vs not (researched 2026-06-15):**

- **Per-layer "preferred direction" (H-on-top/V-on-bottom) does NOT apply
  here.** It's a multi-*signal*-layer convention to reduce crossings when both
  layers route; with B.Cu as a near-solid GND pour it would just force more
  vias and break the reference. KiCad doesn't even export a `(direction …)`
  token to the DSN; FreeRouting's `preferred_direction_horizontal` is a soft
  cost set via CLI/`.rules`, not the board. Skip it. To reduce layer changes,
  raise FreeRouting's `via_costs` (CLI/JSON) instead.
- **Set width/clearance/via-size/membership in KiCad net classes** — these *do*
  export into the Specctra DSN (`(class …)` with per-class `(rule (width…)
  (clearance…))` + `(via …)`), so FreeRouting consumes them. Prefer this over
  hand-coding per-net geometry in our pcb_*.py. (Gap: KiCad always writes the
  *default* netclass clearance for copper-to-hole in the DSN — verify hole
  clearance with DRC after import.)
- **Keep USB on F.Cu** the only way FreeRouting honours it: a B.Cu keepout
  corridor under the J2→module USB lane, or a saved FreeRouting `.rules` file
  fed with `-dr` (KiCad can't express "this net F.Cu-only" in the DSN). USB-FS
  needs no length/skew matching (skew budget ≫ our lengths).
- **Net classes are already the rule home** (Default/IR_Drive/Power in
  `.kicad_pro`, JLC-appropriate via 0.3/0.6), and FreeRouting + DRC honour
  them — nothing to migrate out of Python here. The JLC floors (edge clearance,
  via/track/hole minima, silk) are already enforced by `design_settings`, so a
  wholesale community `.kicad_dru` (labtroll) would be redundant. We added a
  *focused* `hardware/esp32-ir-remote.kicad_dru` instead: an **IR_Drive
  min-track-width (0.45 mm)** rule that locks the 400 mA drive nets.
- ⚠️ **Finding:** the FreeRouting `+3.3V` (Power-class) routing has 0.2 mm
  segments (only IR_Drive is uniformly at class width). Not dangerous at our
  currents but under the Power nominal 0.6 mm — widen on the next re-route, then
  add a Power min-width DRU. (This is why the bridge across the old JP1 gap is
  0.4 mm: 0.6 mm clears the GND pour by <0.3 mm there, and the rail is the weak
  link anyway, not the bridge.)
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

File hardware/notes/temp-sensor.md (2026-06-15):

# Temperature / Humidity Sensor

> **v2 (as-built): AHT20** (U5), an **I²C** temperature + humidity sensor,
> swapped in during the v2 redesign. It replaced the v1 AM2302/DHT22 single-wire
> part. Where this note disagrees with the schematic, the schematic wins.

The AHT20 provides temperature (±0.3 °C, inside the spec's ±1 °C requirement)
and relative humidity for the "Follow Me" feature, where the AC adjusts output
based on the temperature at the remote's location.

## Interface

- **I²C bus** (not single-wire): SCL on C3 **IO10** (U3 pin 10), SDA on C3
  **IO7** (U3 pin 6). The bus is also broken out on the spare header **J4**
  (SCL = pin 4, SDA = pin 3) for external I²C devices.
- **VDD** on +3.3V (pin 2), **GND** on pin 5; pins 1 and 6 are NC.
- **Decoupling:** 100 nF at VDD, placed with the sensor (see `layout.md`
  constraint 10 — U5 gets one 100 nF + 10 µF bank).
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

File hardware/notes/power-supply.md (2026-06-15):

# Power Supply

USB-C power entry with overcurrent and overvoltage protection, followed by an
**AMS1117-3.3 LDO** for 3.3V regulation. (This replaced the v1 AP63203 buck in
the v2 cost-down redesign — see the v2 change set in `ROADMAP.md`.)

## USB-C input
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

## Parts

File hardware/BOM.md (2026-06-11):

# ESP32 IR Remote - Bill of Materials (HISTORICAL — do not order from this)

> **⚠️ DEMOTED 2026-06-11.** This hand-curated document is **stale**: it
> disagrees with the schematic on reference designators (it predates the
> v1.2 changes: J1 removed, J3–J6 added, R27–R30 added) and carried several
> wrong LCSC codes that have since been fixed in the schematic (R13/R22 had
> the 18Ω code, Q3 had the 2N7002 code, R14/R15 had 0805 codes on 1206
> footprints). **The schematic is the single source of truth for parts;
> the generated [`esp32-ir-remote_bom.csv`](esp32-ir-remote_bom.csv)
> (regenerate via `kicad-cli sch export bom`, see `scripts/build-site.sh`)
> is the orderable BOM.** This file is kept only for the part-selection
> rationale and supplier notes below.

## Status

- [x] Power - complete
- [x] USB-UART - complete
- [x] ESP32 & Auto-Reset - complete
- [x] IR Transmitter - complete
- [x] IR Receiver & Sensors - complete
- [x] Status LEDs - complete
- [x] Headers & Mechanical - complete

## Preferences

- **Passives**: Through-hole preferred
- **LCSC**: Basic or Extended OK

---

## 1. Power Subsection

| Ref | Description | Value | LCSC Part | Stock | Datasheet | Verified | Notes |
| ----- | --- | --- | --- | --- | --- | --- | --- |
| U5 | Buck Converter | AP63203WU-7 | C780769 | 3838 | local | ✓ | Fixed 3.3V, TSOT-23-6 |
| D1 | TVS Diode | SMBJ5.0A | C83333 | 71460 | | ✓ | Littelfuse, DO-214AA, 5V standoff |
| F1 | Polyfuse | 1812L110/33MR | C142747 | 62380 | | ✓ | Littelfuse, 1.1A hold, 1812 SMD |
| L1 | Inductor | SRP5030T-4R7M | C2045677  | 222 | | ✓ | BOURNS, 4.7µH, 4.6A, 5x5mm |
| C1 | Input Cap | 10µF 16V X5R  | C18185764 | 413200 | | ✓ | CCTC, 0805 MLCC |
| C2,C3 | Output Cap | 22µF 16V X5R  | C98190 | 1694250  | | ✓ | Samsung, 0805 MLCC, qty 2 |
| C4 | Bootstrap Cap  | 100nF 50V X7R | C1591 | 20454800 | | ✓ | Samsung, 0603 MLCC |

---

## 2. USB-UART Subsection

| Ref | Description | Value | LCSC Part | Stock | Datasheet | Verified | Notes |
| ----- | --- | --- | --- | --- | --- | --- | --- |
| U2 | USB-UART Bridge | CH340C | C84681 | 12199 | | ✓ | WCH, SOP-16 |
| J1 | USB-C Connector | USB4085-GF-A | C7095263  | 342 | | ✓ | GCT, through-hole USB-C |
| R1,R2 | CC Resistors | 5.1kΩ 1% | C26033 | 230100 | | ✓ | UNI-ROYAL, 1206 SMD, qty 2 |
| C9 | V3 Decoupling | 100nF 50V | C1591 | 20454800 | | ✓ | Samsung, 0603 (same as C4) |

---

## 3. ESP32 & Auto-Reset Subsection

| Ref | Description | Value | LCSC Part | Stock | Datasheet | Verified | Notes |
| --- | --- | --- | --- | --- | --- | --- | --- |
| U1 | ESP32 Module | ESP32-WROOM-32E-N4 | C701341 | 1001 | local | ✓ | ESPRESSIF, 4MB flash |
| Q1,Q2 | N-MOSFET | 2N7002 | C8545 | 779450  | | ✓ | CJ, SOT-23, qty 2 (v1.3: was S8050 NPN; shares line with Q4,Q5) |
| C6 | EN Delay Cap | 1µF 16V X5R | C52923 | 1182500 | | ✓ | Samsung, 0805 MLCC |
| R4,R5,R17,R18 | Pull-ups/Base  | 10kΩ 1% | C17902 | 896900  | | ✓ | UNI-ROYAL, 1206, qty 4 |
| SW1,SW2 | Tactile Switch | TS-1088R-02026 | C455280 | 52750 | | ✓ | XUNPU, 6x6mm TH, qty 2 |

---

## 4. IR Transmitter Subsection

| Ref | Description | Value | LCSC Part | Stock | Datasheet | Verified | Notes |
| --- | --- | --- | --- | --- | --- | --- | --- |
| D2,D3,D4,D5 | IR LED | TSAL6200  | C55528 | 955 | | ✓ | Vishay, 940nm 5mm TH, qty 4  |
| Q3 | N-ch MOSFET | IRLML6344 | C5364313  | 38870 | | ✓ | Hottech, SOT-23, logic-level |
| R3,R6,R10,R12 | LED Current | 18Ω 1% | C711458 | 75600 | | ✓ | FOJAN, 1206, qty 4 |
| R7 | Gate Resistor | 10kΩ 1% | C17902 | 896900  | | ✓ | (same as pull-ups) |
| R8 | Gate Pulldown | 100kΩ 1%  | C25803 | 1034300 | | ✓ | UNI-ROYAL, 1206 |

---

## 5. IR Receiver & Sensors Subsection

| Ref | Description | Value | LCSC Part | Stock | Datasheet | Verified | Notes |
| --- | --- | --- | --- | --- | --- | --- | --- |
| U3  | IR Receiver | TSOP38238 | C141632 | 2829 | | ✓ | Vishay, 38kHz, 3-pin TH |
| U4  | Temp/Humidity | AM2302N | C6705248  | 1680 | | ✓ | VBsemi, DHT22 compatible |
| C7  | Decoupling | 100nF 50V | C1591 | 20454800 | | ✓ | Samsung, 0603 (same as C4,C9) |

---

## 6. Status LEDs Subsection

All indicator LEDs are 3mm through-hole Everlight 204 series. Target brightness: ~15-30 mcd.
- Power rail LEDs: direct-driven from rails
- TX/RX LEDs: direct-driven active-low from 3.3V to GPIO
- IR TX LED: direct-driven active-high from GPIO
- Blue user LEDs: MOSFET low-side switching from 5V (Vf=3.4V requires 5V supply)

### 6a. 3mm LEDs

| Ref | Description | Value | LCSC Part | Stock  | Vf | Iv@20mA | Notes |
| --- | --- | --- | --- | --- | ---- | --- | --- |
| D6 | 5V Power LED | 204-10SURD/S530-A3  | C99772 | 14860  | 2.0V | 80mcd | Everlight, 3mm Red |
| D7 | 3.3V Power LED  | 204-10SYGD/S530-E3  | C85161 | 66860  | 2.0V | 100mcd  | Everlight, 3mm Y-Green |
| D8,D9 | Serial TX/RX | 204-10UYD/S530-A3-L | C85160 | 103440 | 2.0V | 200mcd  | Everlight, 3mm Amber ×2 |
| D10 | IR TX Indicator | 204-10SURD/S530-A3  | C99772 | 14860  | 2.0V | 80mcd | Everlight, 3mm Red |
| D11,D12 | User LEDs | 204-10SUBC/S400-A4  | C86881 | 33130  | 3.4V | 800mcd  | Everlight, 3mm Blue ×2 |

### 6b. LED Driver MOSFETs (for blue LEDs only)

| Ref | Description | Value  | LCSC Part | Stock  | Notes |
| ----- | --- | --- | --- | --- | --- |
| Q4,Q5 | LED Drivers | 2N7002 | C8545 | 798650 | JSCJ, SOT-23, N-ch, qty 2 |

### 6c. LED Resistors

Target: ~20-30 mcd brightness. Using only 470Ω and 1kΩ to minimize unique parts.

| Ref | Description | Value | LCSC Part | Stock | Current | ~mcd | Notes |
| --- | --- | --- | --- | --- | --- | ---- | --- |
| R15 | 5V LED Resistor | 1kΩ 1% | C4410 | 870400  | 3.0mA | 12 | UNI-ROYAL 1206 |
| R16 | 3.3V LED Resistor  | 470Ω 1%  | C4502 | 53000 | 2.8mA | 14 | UNI-ROYAL 1206 |
| R17,R18 | TX/RX Resistors | 470Ω 1%  | C4502 | 53000 | 2.8mA | 28 | UNI-ROYAL 1206, qty 2 |
| R19 | IR TX LED Resistor | 470Ω 1%  | C4502 | 53000 | 2.8mA | 11 | UNI-ROYAL 1206 |
| R20,R21 | Blue LED Resistors | 1kΩ 1% | C4410 | 870400  | 1.6mA | 64 | UNI-ROYAL 1206, qty 2 |
| R23,R24 | Gate Pulldowns | 100kΩ 1% | C25803 | 1034300 | - | - | UNI-ROYAL 1206, qty 2 |

**Note**: Only 3 unique resistor values for LEDs: 470Ω, 1kΩ, 100kΩ. Blue LEDs brighter due to InGaN efficiency.

---

## 7. Headers & Mechanical

| Ref | Description | Value | LCSC Part | Stock  | Datasheet | Verified | Notes |
| --- | --- | --- | --- | --- | --- | --- | --- |
| J2 | Breakout Header | 2x20 Female | C50982 | | | ✓ | BOOMELE, 2.54mm, cut to 2x19 |
| JP1 | Buck Disable | 1x2 Male | C124375 | | | ✓ | Ckmtw, 2.54mm TH |
| JP2,JP3 | Auto-reset Bypass | 1x2 Male | C124375 | | | ✓ | qty 2 (same as JP1) |
| - | Jumper Shunts | 2.54mm | C5305 | 165800 | | ✓ | BOOMELE, qty 2-3 |

---

## Summary

| Category | Unique Parts | Total Qty |
| --- | --- | --- |
| ICs | 5 | 5 |
| Transistors | 2 | 3 |
| Diodes/LEDs | 6 | 12 |
| Capacitors | 4 | 9 |
| Resistors | ~7 | ~22 |
| Inductors | 1 | 1 |
| Connectors | 2 | 2 |
| Switches | 1 | 2 |
| Jumpers/Shunts | 2 | 5-6 |
| Fuses | 1 | 1 |
| **Total** | **~31** | **~62** |

---

## Schematic Update Notes

1. **Blue LEDs use MOSFET drivers** - 2× 2N7002 with 100kΩ gate pulldowns, powered from 5V rail
2. **LED resistor values** - use 1kΩ for 5V LEDs (red power, blue user), 470Ω for 3.3V LEDs (green power, amber TX/RX, red IR)
3. **Fix R15** - currently shows "22µF" (should be 1kΩ)
4. **L1** - BOM specifies 4.7µH, schematic may show 3.9µH (both acceptable per AP63203 datasheet)

Reference designators in this BOM are indicative only. The schematic is the source of truth for designators.

---

## Notes

- Datasheets stored in `hardware/datasheets/`
- Existing datasheets: AP63203WU-7.pdf, ESP32-WROOM-32E-N4.pdf
- All LEDs are Everlight 204 series 3mm for consistency
- Blue LEDs (InGaN) are inherently brighter; reduced current via 1kΩ resistor for similar perceived brightness

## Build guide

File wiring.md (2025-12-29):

# IR Transmitter Wiring Guide

## Overview

Add an IR LED transmitter circuit to your ESP8266 NodeMCU to enable IR transmission. The circuit uses a transistor to drive the IR LED with sufficient current.

---

## Components Needed

| Component | Quantity | Notes |
| --- | --- | --- |
| 940nm IR LED (5mm) | 1-2 | Standard IR LED, get extras for parallel config if needed |
| 2N2222 NPN Transistor | 1 | Or BC547, PN2222 - any general-purpose NPN |
| 470Ω resistor | 1 | Base resistor (controls transistor) |
| 10Ω resistor | 1 | LED current limiting resistor |
| Breadboard | 1 | For prototyping |
| Jumper wires | 5-6 | Male-to-male for breadboard |

---

## Circuit Diagram

### Schematic

```
ESP8266 NodeMCU

GPIO4 (D2) ----[470Ω]----> Base (B)
                              |
                         2N2222 NPN
                              |
                         Collector (C)
                              |
                         IR LED Cathode (short leg, flat side)
                              |
                         IR LED Anode (long leg)
                              |
                           [10Ω]
                              |
                            3.3V

GND --------------------> Emitter (E)
```

### Pin Identification

**2N2222 Transistor (TO-92 package, flat side facing you):**

```
    ___
   /   \
  | 2N2 |
  | 222 |
  |_____|
   | | |
   E B C
```

- **E** = Emitter (leftmost) → ESP8266 GND
- **B** = Base (middle) → GPIO4 via 470Ω resistor
- **C** = Collector (rightmost) → IR LED cathode

**IR LED:**

- **Anode** (+, longer leg) → 10Ω resistor → 3.3V
- **Cathode** (-, shorter leg, flat side) → Transistor collector

---

## Breadboard Layout

```
ESP8266 NodeMCU Layout:
         ┌─────────┐
    3V3  │1      30│  GND
    GND  │2      29│  ...
    D1   │3      28│  ...
    D2   │4 ← TX  27│  ...  (GPIO4 - IR Transmit)
    D3   │5      26│  ...
    D4   │6      25│  ...
    D5   │7 ← RX  24│  ...  (GPIO14 - IR Receive, already wired)
    ...  │8      23│  ...
         └─────────┘
```

### Breadboard Wiring Steps

1. **Place the transistor** on breadboard (flat side facing you)

   - Emitter (left pin) → breadboard ground rail
   - Base (middle pin) → empty row
   - Collector (right pin) → empty row

2. **Connect 470Ω resistor** (base resistor)

   - One end → GPIO4 (D2) on ESP8266
   - Other end → transistor base (middle pin)

3. **Place IR LED** on breadboard

   - Cathode (short leg, flat side) → same row as transistor collector
   - Anode (long leg) → empty row

4. **Connect 10Ω resistor** (LED current limiting)

   - One end → IR LED anode
   - Other end → 3.3V power rail

5. **Connect ground**

   - Transistor emitter → ground rail
   - ESP8266 GND → ground rail

6. **Connect power**
   - ESP8266 3V3 → power rail
   - 10Ω resistor → power rail

---

## Power Calculations

**Current through IR LED:**

- Supply voltage: 3.3V
- IR LED forward voltage: ~1.2V @ 20mA
- Current limiting resistor: 10Ω
- **Current: (3.3V - 1.2V) / 10Ω = 210mA**

This provides sufficient IR power for 2-5 meter range (typical room distance).

**Transistor specifications:**

- 2N2222 max collector current: 600mA
- Our circuit: ~210mA
- **Safety margin: >2.8x** ✓

---

## Testing Procedure

### 1. Visual Inspection

- ✓ Transistor oriented correctly (E-B-C)
- ✓ IR LED polarity correct (long leg = anode to power)
- ✓ No short circuits
- ✓ All connections tight

### 2. Resistance Check (Power OFF)

Use multimeter to verify:

- GPIO4 to GND through resistor+transistor: Should read ~470Ω + transistor resistance
- 3.3V to GND through LED circuit: Should read ~10Ω + LED resistance

### 3. IR LED Test (Use Phone Camera)

1. Upload the firmware (main.cpp)
2. Open Serial Monitor at 115200 baud
3. Send command: `POWER:OFF`
4. **Point phone camera at IR LED**
5. You should see **purple/white flashing** on camera screen
6. (Note: IR light is invisible to human eye but visible on phone cameras)

### 4. Loopback Test

1. IR receiver already on GPIO14 (D5)
2. Enable debug mode: `DEBUG:ON`
3. Send command: `POWER:OFF`
4. Check Serial Monitor for: `DEBUG: Received IR - Protocol: COOLIX`
5. This confirms IR LED is transmitting and receiver is picking it up

### 5. Protocol Verification

Send each command and verify IR transmission:

```
POWER:OFF     → Should see IR flash (COOLIX)
TEMP:22       → Should see IR flash (BOSCH144)
MODE:COOL     → Should see IR flash (BOSCH144)
SWING         → Should see IR flash (COOLIX)
```

---

## Troubleshooting

### IR LED Not Transmitting (No flash on camera)

**Check 1: Transistor connections**

- Verify E-B-C pinout matches your transistor datasheet
- Try swapping collector and emitter if using different transistor

**Check 2: IR LED polarity**

- Long leg (anode) should go to 3.3V via resistor
- Short leg (cathode) should go to transistor collector
- Try reversing if not working

**Check 3: Power supply**

- Measure voltage at 3.3V pin: should be 3.2-3.4V
- If using USB power, try different USB port/cable

**Check 4: Resistor values**

- Verify 470Ω resistor (Yellow-Purple-Brown or Yellow-Purple-Black-Black)
- Verify 10Ω resistor (Brown-Black-Black or Brown-Black-Gold-Gold)

### IR LED Weak/Short Range

**Solution 1: Add second IR LED in parallel**

```
                         [LED1 Cathode]---[LED1 Anode]---[10Ω]---3.3V
                              |
Transistor Collector ---------|
                              |
                         [LED2 Cathode]---[LED2 Anode]---[10Ω]---3.3V
```

This doubles the IR power output.

**Solution 2: Reduce current limiting resistor**

- Change 10Ω → 5Ω for more current (~350mA)
- Monitor ESP8266 temperature (should stay cool)

**Solution 3: Focus the beam**

- Point IR LED directly at AC unit's receiver
- Use reflector or lens to focus IR beam
- Keep distance under 5 meters for best results

### IR Transmission But AC Not Responding

**Check 1: Aim**

- Point IR LED directly at AC unit's IR receiver
- AC receiver is usually near display/indicator lights
- Try different angles

**Check 2: Distance**

- Start at 1-2 meters
- Gradually increase distance
- Optimal range: 2-5 meters

**Check 3: Protocol verification**

- Use `DEBUG:ON` mode
- Send command
- Verify firmware is transmitting correct protocol (BOSCH144 or COOLIX)
- Compare with captures in `/captures` directory

---

## Advanced: Multiple IR LEDs for Extended Range

If you need longer range (>5m) or wider coverage, add 2-3 IR LEDs in parallel:

```
                         [LED1]---[10Ω]
                              |
Transistor Collector ---------|---[LED2]---[10Ω]---3.3V
                              |
                         [LED3]---[10Ω]
```

**Benefits:**

- Increased range (up to 8-10m)
- Wider beam angle
- More reliable transmission

**Note:** Total current = 210mA × number of LEDs. Keep under 500mA to avoid overloading ESP8266's 3.3V regulator.

---

## Permanent Installation

Once testing is successful:

1. **PCB/Perfboard** - Transfer circuit to permanent board
2. **Enclosure** - 3D print or use project box
3. **Status LED** - Add visible LED on GPIO2 (D4, built-in) for transmission indicator
4. **Power supply** - Use 5V USB wall adapter for reliable power

---

## Final Checklist

Before considering hardware complete:

- [ ] IR LED transmits (verified with phone camera)
- [ ] Loopback test successful (receiver picks up transmission)
- [ ] All protocols tested (POWER:OFF, TEMP:22, SWING)
- [ ] AC unit responds to Power OFF command
- [ ] AC unit responds to temperature changes
- [ ] Range tested (works at 2-5 meters)
- [ ] Circuit stable (no intermittent issues)

---

## Next Steps

Once hardware is working:

1. Test all serial commands with Serial Monitor
2. Verify AC unit responds to all commands
3. Proceed to React Router app development
4. Final integration testing

**Good luck with the build!** 🔧

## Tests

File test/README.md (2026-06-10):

# C++ Unit Tests

Unit tests for the ActronAir IR Controller firmware using PlatformIO's native testing framework.

## Test Suites

- `test_parsing/` - serial command parsing and validation logic
- `test_bosch144_protocol/` - BOSCH144 frame construction
  (`include/bosch144_protocol.h`) asserted byte-for-byte against the captured
  protocol tables in `re-findings.md` and IRremoteESP8266's bit layout

## Running Tests

### Run all tests

```bash
pio test -e native
```

### Run with verbose output

```bash
pio test -e native -v
```

### Run specific test

```bash
pio test -e native --filter test_parsing
```

## Test Coverage

### Temperature Validation (`validateTemperature`)

- ✓ Valid whole numbers (16.0, 20.0, 22.0, 25.0, 30.0)
- ✓ Valid half increments (16.5, 20.5, 22.5, 25.5, 29.5)
- ✓ Invalid below minimum (<16.0)
- ✓ Invalid above maximum (>30.0)
- ✓ Invalid wrong increments (20.1, 22.3, 25.7)
- ✓ Boundary conditions (exactly 16.0 and 30.0)

### Mode Parsing (`parseMode`)

- ✓ Valid modes (COOL, HEAT, DRY, FAN, AUTO)
- ✓ Invalid modes (returns 255)
- ✓ Case sensitivity (uppercase required)

### Fan Speed Parsing (`parseFanSpeed`)

- ✓ Valid speeds (AUTO, 20, 40, 60, 80, 100)
- ✓ Invalid speeds (returns 255)
- ✓ Unsupported values (50, 0)

### String Formatting (`getModeString`, `getFanString`)

- ✓ Valid mode/fan codes → correct strings
- ✓ Invalid codes → "UNKNOWN"

### Round-trip Tests

- ✓ Parse → Format should return original string
- ✓ All modes tested
- ✓ All fan speeds tested

## Test Output

Example successful test run:

```
test/test_parsing.cpp:48:test_temperature_valid_whole_numbers       [PASSED]
test/test_parsing.cpp:55:test_temperature_valid_half_increments     [PASSED]
test/test_parsing.cpp:62:test_temperature_invalid_below_min         [PASSED]
test/test_parsing.cpp:69:test_temperature_invalid_above_max         [PASSED]
test/test_parsing.cpp:76:test_temperature_invalid_wrong_increments  [PASSED]
test/test_parsing.cpp:83:test_temperature_boundary_conditions       [PASSED]
test/test_parsing.cpp:92:test_parseMode_valid_modes                 [PASSED]
test/test_parsing.cpp:100:test_parseMode_invalid_modes              [PASSED]
test/test_parsing.cpp:108:test_parseMode_case_sensitive             [PASSED]
test/test_parsing.cpp:117:test_parseFanSpeed_valid_speeds           [PASSED]
test/test_parsing.cpp:126:test_parseFanSpeed_invalid_speeds         [PASSED]
test/test_parsing.cpp:133:test_getModeString_valid_modes            [PASSED]
test/test_parsing.cpp:141:test_getModeString_invalid_mode           [PASSED]
test/test_parsing.cpp:147:test_getFanString_valid_speeds            [PASSED]
test/test_parsing.cpp:156:test_getFanString_invalid_speed           [PASSED]
test/test_parsing.cpp:162:test_mode_roundtrip                       [PASSED]
test/test_parsing.cpp:173:test_fan_roundtrip                        [PASSED]

-----------------------
17 Tests 0 Failures 0 Ignored
OK
```

## Adding More Tests

To add new tests:

1. Create a new test directory under `/test` (e.g., `test_newfeature/test_newfeature.cpp`)
2. Include `<unity.h>` header
3. Write test functions with `TEST_ASSERT_*` macros
4. Add tests to `main()` with `RUN_TEST()`
5. Run with `pio test -e native`

## Test Framework

Uses **Unity** test framework (built into PlatformIO):

- `TEST_ASSERT_TRUE(condition)` - Assert condition is true
- `TEST_ASSERT_FALSE(condition)` - Assert condition is false
- `TEST_ASSERT_EQUAL(expected, actual)` - Assert values are equal
- `TEST_ASSERT_EQUAL_STRING(expected, actual)` - Assert strings are equal
- `TEST_ASSERT_EQUAL_UINT8(expected, actual)` - Assert uint8_t values are equal

[Full Unity documentation](http://www.throwtheswitch.org/unity)

## CI Integration

These tests can run in CI/CD pipelines:

```yaml
# Example GitHub Actions
- name: Run Unit Tests
  run: pio test -e native
```

No ESP8266 hardware required - tests run on the host machine!

## Limitations

**What these tests cover:**
- Command parsing logic
- Temperature validation
- String formatting
- State management functions

**What these tests DON'T cover:**
- Actual IR transmission (hardware-dependent)
- Serial communication (hardware-dependent)
- Arduino-specific functionality
- ESP8266-specific features

For full integration testing, use the actual hardware with Serial Monitor testing.

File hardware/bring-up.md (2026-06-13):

# Board bring-up procedure — esp32-ir-remote rev 1.4

Per-subsystem power-on test sequence. Do these **in order**; each step gates
the next. Bench kit: USB-C cable + current-limited supply or USB power meter,
multimeter, the ESP8266 breadboard rig (known-good IR reference), a phone
camera (sees 940nm as purple glow).

**Boards arrive SMT-only** (rev 1.4 fab package): JLCPCB places the 47 SMD
parts; everything else is in the hand-solder kit
(`esp32-ir-remote-hand-solder-kit.csv` in the fab package — regenerated by
CI, download from the Pages site or the `fab-package` CI artifact at the
ordered/tagged commit; per-part polarity notes included).

## 0. Hand-solder the power path, then inspect (before any power)

- [ ] **Solder the fit-before-first-power kit parts:** J2 (USB-C, THT),
      F1 (polyfuse 1812 — VBUS is open-circuit without it), L1 (4.7µH —
      no 3.3V without it), D1 (TVS, **align cathode band with the
      on-board silk band marker** — the band end is the +5V pad; the
      marking was corrected 2026-06-13, rev 1.4 boards are true).
      Optionally D6/D7 power LEDs now for visible rails.
- [ ] No solder bridges around U1 (TSOT-23-6), U2 (SOIC-16), Q3-Q5 (SOT-23),
      and your own J2/F1/L1/D1 joints.
- [ ] L1, C1-C3 orientation n/a (non-polarized).
- [ ] JP1 intact (not cut) — buck enabled.
- [ ] Continuity: GND at J2 shell ↔ U3 GND pads ↔ mounting-hole-adjacent
      pour. No continuity +5V↔GND, +3.3V↔GND (>1kΩ rising = caps charging).

## 1. Bare power (no firmware)

- [ ] Power from a current-limited supply via USB-C (limit 200mA first).
      Expect idle draw < 60mA (WROOM unprogrammed boot loop is bursty;
      brief 200-300mA spikes are normal on a non-limited supply).
- [ ] **Probe TP order:** VBUS at F1 west pad ≈ 5.0V → D1 node ≈ 5.0V →
      U1 VIN (pin 3) ≈ 5.0V → **+3.3V at C3 = 3.25-3.35V** (buck output).
- [ ] D6 (5V red) and D7 (3V3 green) LEDs lit (if THT LEDs populated).
- [ ] Nothing warm: U1 barely warm at no load; U3 cool.
- [ ] If +3.3V missing: check JP1 not cut, L1 solder, U1 EN (pin 2 — JP1
      pulls it up via R14/R15 divider per power-supply.md).

## 2. USB enumeration

- [ ] Plug into the Mac. `ls /dev/tty.*` → a `tty.usbserial-*` /
      `tty.wchusbserial-*` appears (CH340C).
- [ ] Both USB-C cable orientations enumerate (CC1/CC2 5.1k pulldowns OK).
- [ ] If no enumeration: check CH340C V3 (pin 4) = 3.3V, crystal-less C
      variant needs VCC=3.3V exactly; D+/D- continuity J2→U2 pins 5/6.

## 3. Flash + serial

- [ ] `pio run -e esp32dev -t upload` — auto-reset via DTR/RTS (Q1/Q2)
      should enter bootloader without holding BOOT. If it fails, hold
      BOOT (SW2) while tapping RESET (SW1) — then investigate Q1/Q2
      (this rev fixed the BCE/BEC pinout swap; verify EN pulses low on
      flash start with a scope if auto-reset still fails).
- [ ] `./scripts/monitor.sh` at 115200: boot banner, no brownout resets.
- [ ] D8/D9 (TX/RX ambers) flicker during flash/monitor traffic.

## 4. GPIO smoke test (fw: blink + button echo)

- [ ] User LEDs D11/D12 blink (GPIO16/17 → Q4/Q5 → blue LEDs from 5V rail).
- [ ] D10 (IR-TX red indicator) flashes when sending IR (it parallels the
      gate drive, visible even with no IR LEDs fitted).
- [ ] SW1 resets; SW2 reads low on GPIO0 when pressed.

## 5. Sensors

- [ ] DHT22 (U5, hand-solder): TEMP_DATA on GPIO4, read temp+humidity;
      sanity 15-35°C indoors. R22 10k pullup on the data line.
- [ ] TSOP38238 (U4, hand-solder): point the ActronAir remote at it,
      capture on GPIO19 (`python3 scripts/capture.py bench-rx-1`), decode
      must match re-findings tables. Vs RC filter (R27/C9) means clean 3V3
      at U4 pin 3.

## 6. IR transmit (the mission)

- [ ] Hand-solder D2-D5 bent 90° per silkscreen fan guides (lens over the
      north edge, -67.5/-22.5/+22.5/+67.5).
- [ ] Phone camera check: all four LEDs glow purple on send.
- [ ] Current check: IR burst draw ≈ 360-400mA above idle during send
      (4×~90-100mA). If one string is dark: that LED's 18Ω resistor or
      orientation.
- [ ] **AC test:** replay the breadboard regression set — POWER on/off,
      TEMP sweep incl. half-degree (`TEMP:22.5`), MODE, FAN. AC must
      respond from ≥3m, then from across the room (~8-10m, off-axis).
- [ ] Ext-IR header J5 (if fitted): scope EXT_IR_A for the 38kHz burst.

## 7. WiFi soak

- [ ] Join network; `ping -c 100` packet loss <2% at usable distance.
      The antenna overhangs the west edge with a copper keepout; if range
      disappoints, check H1's screw (use **nylon** for H1 — it sits at the
      edge of the antenna keepout wedge) and clearance to the enclosure.
- [ ] 24h idle soak: no watchdog resets in the log; report RSSI drift.

## Known rev-1.4 quirks to watch

- H1 mounting hole encroaches the RF keepout corner — nylon screw there.
- JP1 is a solder-bridge/test-point pair, not a header (no part fitted):
  cut the bridge trace to disable the buck for external 3.3V injection.
- J6 JTAG and R28-R30 are DNP by design; J5 ext-IR header is in the kit
  but optional.
- SW1/SW2 are 4-pad TS-1187A (rev 1.4, Basic part swap): same-row pads are
  internally common; bridge tracks under the body join the pad pairs.
- Q3 is an AO3400A (rev 1.4, was IRLML6344 — electrically equivalent here).
- AM2302 (U5, hand-solder) was near stock-out at LCSC at design time — if
  unfitted, all step-5 DHT checks are skipped; Qwiic (J3, also in the kit)
  carries I2C as the sensor fallback path (R28/R29 pullups DNP — fit if the
  Qwiic device doesn't have its own).

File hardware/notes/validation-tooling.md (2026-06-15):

# Validation/fab tooling: adopt KiBot

**Status (2026-06-15): DONE — gate + ibom adopted; fab deliberately kept.**

- ✅ **KiBot owns the ERC/DRC error gate** in CI (its preflights fail on real
  violations). `hardware_validate.py` keeps the bespoke checks (netlist
  freshness, polarity truth table, page-extent, BOM-LCSC) + parity/unconnected
  and still emits the PR-report count facts.
- ✅ **Version-drift killed.** WARNING-severity baseline count changes
  (lib/silk heuristics that drift across KiCad patch releases) are now
  informational, not failures. Errors + parity/unconnected (version-stable)
  still gate. (Answers the 10.0.3↔10.0.2 drift question directly.)
- ✅ **InteractiveHtmlBom** generated in CI into the fab package.
- 🟰 **Fab outputs stay in `scripts/fab-outputs.py` (for now)** — a deliberate
  decision, not a TODO. Its assembly-split logic (the hand-solder kit,
  no-LCSC→DNP, the kit CSV + orientation report, the "refuse to emit on an
  unclassified footprint" safety guard) is genuinely project-specific.
  **Premise correction (2026-06-15):** the earlier reasoning here assumed the
  KiBot win was "its built-in JLC rotation DB." That DB **does not exist** —
  KiBot's `rot_footprint` ships an *empty* `rotations` list; you supply the
  table (same as us). The maintained community values now live in
  `bennymeg/Fabrication-Toolkit` (`transformations.csv`), which KiBot's
  `bennymeg_mode: true` tracks — our old `matthewlai/JLCKicadTools` cite is
  deprecated. So migrating to KiBot's `position`+`rot_footprint`+`bom`
  consolidates onto a *maintained CPL/BOM engine* (stop hand-rolling the
  rotate/offset trig) but does **not** hand us a free DB; the values + the
  refuse-on-unclassified guard remain ours to keep. Worth doing, gated by the
  byte-diff below — see "Plan once unblocked".

The schematic instance-path bug that blocked KiBot is fixed (see below).

Same "shoulders of giants" pass as the FreeRouting one: our CI gate
(`scripts/ci/hardware_validate.py`) and fab generation (`scripts/fab-outputs.py`,
`bom_report.py`, the `pcb_checks.py`/`pcb_metrics.py` geometry parsers) reinvent
a lot that **KiBot** + native KiCad rules already do.

## Recommendation

| We hand-rolled | Adopt |
|---|---|
| ERC/DRC/parity gate + `ci-baseline.json` counts (`hardware_validate.py`) | **KiBot** `erc`/`drc` preflights (fail on errors; allow-list noise via `filters:`) |
| Gerbers/drill/pos/BOM + the rotate/offset CPL trig (`fab-outputs.py`) | **KiBot** `gerber`/`position`/`bom` + `rot_footprint` (we supply the values — KiBot has no built-in DB) → shrink `fab-outputs.py` to its special core |
| Interactive BOM (none today) | **InteractiveHtmlBom** (KiBot `ibom` output) — useful for the hand-solder kit |
| Geometry checks (`pcb_checks.py`) | mostly **already native** — see below |

**Stays bespoke Python** (no standard tool expresses these): netlist
partition-freshness, the polarity/orientation truth table (our best dead-board
catcher), schematic page-extent, LDO thermal **copper-area** (DRU has no
area constraint), and `bom_report.py` (LCSC/JLC-specific; KiCost has no LCSC).

### `.kicad_dru` is narrower than the research assumed

The project's `design_settings` (in `.kicad_pro`) already enforce edge clearance
(0.2), via/track/hole minimums, silk, text height etc. via native
`kicad-cli pcb drc`, and `antenna_keepout` is a real keepout rule-area
(FreeRouting + DRC already honour it — 0 intrusions). FreeRouting also respects
the per-netclass widths (Power 0.6 / IR_Drive 0.5 / Default 0.2, verified). So
the only genuinely *additive* DRU rules would be **per-netclass minimum track
width** (catch a manually-narrowed Power/IR track) and a **USB diff-pair**
gap/skew rule.

**ADDED (2026-06-15): `hardware/esp32-ir-remote.kicad_dru`** with the
IR_Drive minimum-track-width rule (`min 0.45mm`) — kicad-cli DRC + KiBot's drc
preflight auto-load it; verified it loads (forcing min 0.6 flags all 33
IR_Drive tracks) and passes at 0.45. This hard-locks the 400 mA drive nets
against a future neck-down. **Power-class min-width is intentionally NOT set
yet:** the current FreeRouting `+3.3V` routing still contains 0.2 mm segments
(only IR_Drive is uniformly at-class), so a Power min-width rule would fail the
board today — widen the power rail in the next re-route, then add it. The USB
diff-pair gap rule is moot until USB is forced onto F.Cu (the remaining
FreeRouting `.rules`/keepout lever — see `autorouting-freerouting.md`).

## ✅ RESOLVED — schematic instance-path inconsistency (was the blocker)

KiBot 1.9.0 (pip, `--no-compile` + `lxml`/`requests`/`pyyaml`/`colorama`/
`qrcodegen`) installs and the config is correct, but it **crashes parsing our
schematic**: `v6_sch.py load_project → instances[0].path.split('/')[0]`
IndexError. Cause: **16 of the v2-redesign symbols** (U1, U3, U5, J4, J5, R7,
R8, R20, R25, R27–R30, JP1, + 2 power flags) carry instance `(path "/")`
instead of the root-sheet UUID `(path "/09f96520-…-04cd")` that the other 61
symbols use. KiCad itself tolerates the mix; KiBot's stricter parser does not.

This is a genuine latent schematic bug from the v2 re-architecture, not just a
KiBot quirk. **Do NOT hand-edit it:** normalizing the paths by hand *changes the
netlist* (U5's NC pads gain `unconnected-(U5-NC-Pad1/6)` nets → schematic-parity
19→21), so it must be done by **re-saving the schematic in KiCad 10** (Nick's
Mac), which will normalize the paths the canonical way. Heads-up: that re-save
**will change the committed netlist** (regenerate `esp32-ir-remote.net` + refresh
the parity/netlist baseline in the same commit) — expect the 2 U5 NC nets.

## Plan once unblocked

1. ✅ **DONE (2026-06-15): KiBot CPL/BOM + cross-check.**
   `hardware/esp32-ir-remote-fab.kibot.yaml` produces the JLCPCB `position`
   (with a `rot_footprint` pre_transform carrying **our** reviewed rotations:
   `^SOT-223-3_TabPin2`→180, `^SOT-23`→270, USB-C +1.44 mm X offset;
   `bennymeg_mode: true`) + a JLCPCB `bom`. `scripts/ci/cpl_crosscheck.py`
   (gating in CI, after fab-outputs.py + the KiBot install) asserts the two
   engines agree: every assembled designator → same rotation (mod 360), same
   position (≤1 µm), same side, same LCSC. **Verified equivalent: 43/43
   placements, 0 delta**, and the negative test (flip `^SOT-23` to 180) fails
   the gate as intended. So the dead-board concern (KiBot vs our trig applying
   the same values) is closed; the CPL ROTATION GATE is now automated.
2. **Cutover (when ready):** point CI's order package at KiBot's
   `position`+`bom`+`gerber`/`excellon`/zip and slim `fab-outputs.py` to its
   special core (hand-solder kit narrative + the refuse-on-unclassified guard +
   the orientation report). **Still gated by the mandatory JLC-preview check**
   for SOT-23/USB-C on the first assembled order — the cross-check proves the
   two tools agree, not that the absolute rotation is right on real silicon.
3. Slim `hardware_validate.py` to the 3 bespoke checks wrapping KiBot's exit code;
   keep `bom_report.py`.
4. CI: swap `kicad/kicad:10.0.2` → pinned `ghcr.io/inti-cmnb/kicad10_auto[_full]`
   by digest; `kibot -c …`. (Confirm a published k10.0.2/10.0.3 KiBot image.)

## Env (this container)

KiBot 1.9.0 in `/tmp/kv10` (install with `pip install --no-compile kibot` then
`pip install --no-compile lxml requests pyyaml colorama qrcodegen`; delete any
`*.pyc` under `site-packages/kibot`). Run with `/tmp/kv10/bin/kibot`.

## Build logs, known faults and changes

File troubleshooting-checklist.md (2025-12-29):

# IR LED Circuit Troubleshooting Checklist

## Current Symptoms
- Serial commands work ✓
- IR LED not visible on camera ✗
- Collector voltage: 2.4V (should be ~0.2V when ON, ~3.3V when OFF)
- Current through LED: ~10mA (should be ~190mA when transmitting)

## Verification Steps

### Step 1: Power OFF - LED Polarity (Diode Mode)
- [ ] Set multimeter to diode test mode (⏵|◁ symbol)
- [ ] Red probe on longer leg, black probe on shorter leg
  - **Expected**: ~0.6-1.2V reading (forward voltage)
- [ ] Reverse probes
  - **Expected**: "OL" or very high reading (reverse bias)
- [ ] **Confirm**: Longer leg = Anode, connects to 3.3V side
- [ ] **Confirm**: Shorter leg/flat edge = Cathode, connects to Collector

### Step 2: Power OFF - Transistor Pinout (Continuity Mode)
- [ ] 2N2222 flat side facing you, pins are E-B-C (left to right)
- [ ] Left pin (Emitter) has continuity to ESP8266 GND pin
- [ ] Middle pin (Base) has continuity through resistor to D2
- [ ] Right pin (Collector) has continuity to IR LED cathode

### Step 3: Power OFF - Full Circuit Continuity
- [ ] 3.3V → 10Ω resistor → IR LED anode (path exists)
- [ ] IR LED cathode → Transistor collector (direct connection)
- [ ] Transistor base → 470Ω resistor → D2 (path exists)
- [ ] Transistor emitter → GND (direct connection, beep sound)

### Step 4: Power ON - Idle Voltages
- [ ] D2: Should be ~0V when idle
- [ ] Base: Should be ~0V when idle
- [ ] Collector: Should be ~3.2-3.3V when transistor OFF
- [ ] Emitter: Should be 0V (GND reference)

### Step 5: Power ON - Active Transmission
**Send command**: `POWER:OFF` (sends Coolix code)

**Measure immediately during transmission:**
- [ ] D2: Should pulse between 0V-3.3V rapidly (38kHz)
- [ ] Collector: Should drop to ~0.2V when transistor saturated
- [ ] Current through 10Ω resistor: (3.3V - 1.2V - 0.2V) / 10Ω = ~190mA

### Step 6: Visual Confirmation
- [ ] Point IR LED at phone camera
- [ ] Send `POWER:OFF` command
- [ ] Camera should show bright purple/white flashing

## Diagnostic Results

### If LED polarity is backwards:
- **Symptom**: Collector ~2.4V, low current (~10mA)
- **Fix**: Flip the IR LED 180 degrees

### If transistor pins are wrong:
- **Symptom**: No voltage change on any pin during command
- **Fix**: Re-check 2N2222 pinout, rewire if needed

### If resistor is wrong value:
- **Symptom**: Very low current OR LED not visible
- **Fix**: Verify 10Ω resistor (brown-black-black bands)

### If LED is damaged:
- **Symptom**: All voltages correct but no light on camera
- **Fix**: Replace IR LED with new 940nm LED

### If transistor is damaged:
- **Symptom**: Collector stays at 3.3V, never drops
- **Fix**: Replace 2N2222 transistor

## Expected Voltage Summary

| Point | Idle (Transistor OFF) | Transmitting (Transistor ON) |
|---|---|---|
| 3.3V  | 3.3V | 3.3V |
| IR Anode | 3.3V | 3.3V |
| IR Cathode (Collector) | 3.3V | ~0.2V |
| Base  | 0V | ~2.6V (pulsing) |
| Emitter | 0V | 0V |
| D2 | 0V | 3.3V (pulsing at 38kHz) |

**Current LED behavior**: Collector at 2.4V suggests LED barely conducting (~10mA) → likely backwards or damaged

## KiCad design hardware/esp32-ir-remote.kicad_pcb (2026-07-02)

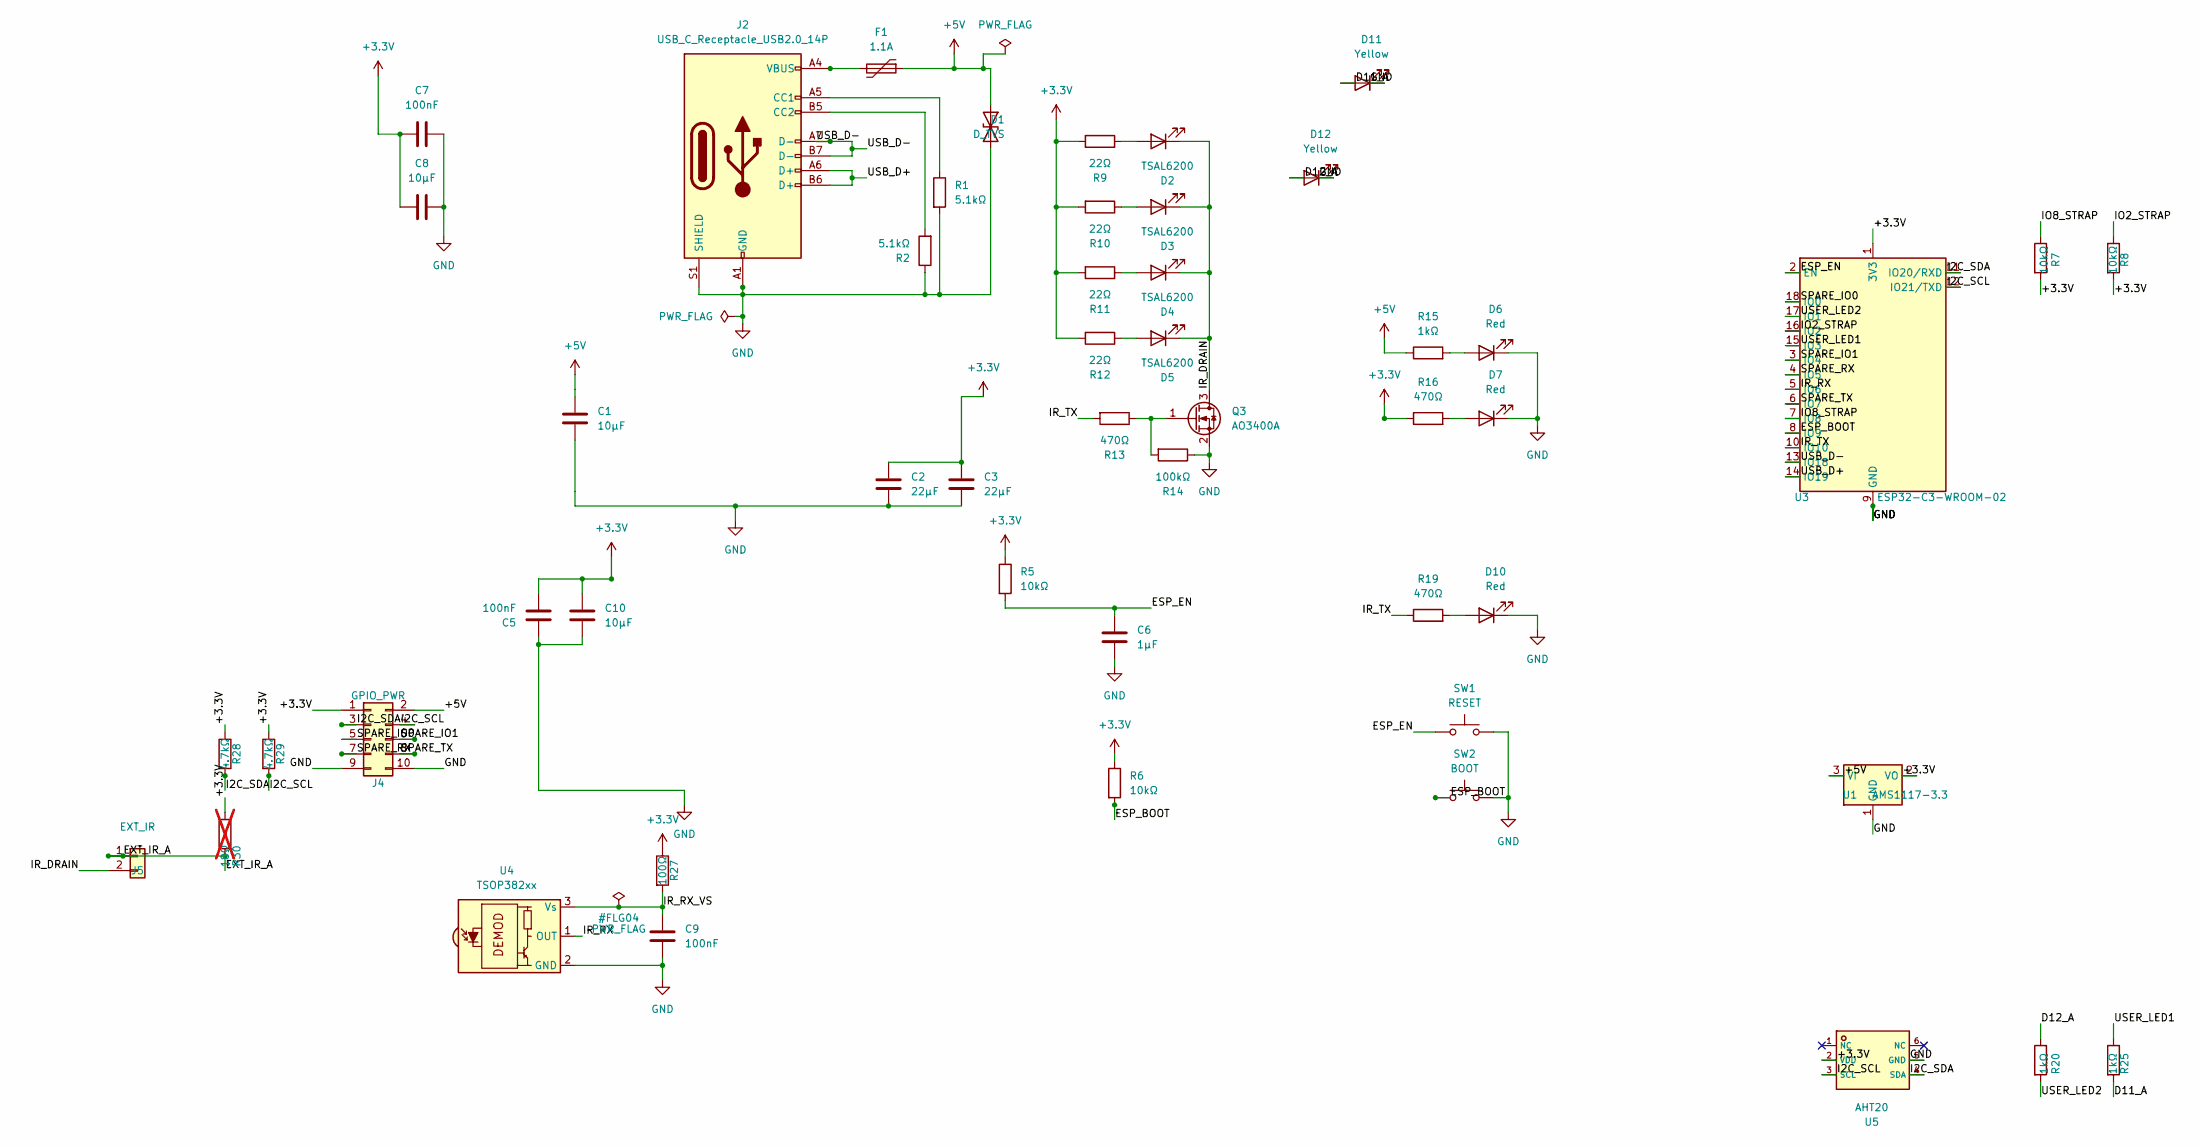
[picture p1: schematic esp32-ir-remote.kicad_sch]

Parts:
C1, C8: 10µF; C_0805_2012Metric; LCSC C15850
C2, C3: 22µF; C_0805_2012Metric; LCSC C45783
C5, C7, C9: 100nF; C_0603_1608Metric; LCSC C14663
C6: 1µF; C_0805_2012Metric; LCSC C28323
C10: 10µF; C_0603_1608Metric; LCSC C19702
D1: D_TVS; D_SMB; LCSC C83333
D2, D3, D4, D5: TSAL6200; LED_D5.0mm; LCSC C55528
D6, D7, D10: Red; LED_0805_2012Metric; LCSC C84256
D11, D12: Yellow; LED_0805_2012Metric; LCSC C2296
F1: 1.1A; Fuse_1812_4532Metric; LCSC C142747
J2: USB_C_Receptacle_USB2.0_14P; USB_C_Receptacle_XKB_U262-16XN-4BVC11; LCSC C393939
J4: GPIO_PWR; PinHeader_2x05_P2.54mm_Vertical
J5: EXT_IR; PinHeader_1x02_P2.54mm_Vertical
Q3: AO3400A; SOT-23; LCSC C20917
R1, R2: 5.1kΩ; R_0805_2012Metric; LCSC C27834
R5: 10kΩ; R_1206_3216Metric; LCSC C17902
R6: 10kΩ; R_0805_2012Metric; LCSC C17414
R7: 10kΩ; R_0805_2012Metric; LCSC C17414
R8: 10kΩ; R_1206_3216Metric; LCSC C17902
R9, R10, R11, R12: 22Ω; R_1206_3216Metric; LCSC C17958
R13, R16, R19: 470Ω; R_0805_2012Metric; LCSC C17710
R14: 100kΩ; R_1206_3216Metric; LCSC C17900
R15: 1kΩ; R_1206_3216Metric; LCSC C4410
R20, R25: 1kΩ; R_0805_2012Metric; LCSC C17513
R27: 100Ω; R_1206_3216Metric; LCSC C17901
R28, R29: 4.7kΩ; R_1206_3216Metric; LCSC C17936
R30: 18Ω; R_1206_3216Metric; LCSC C17922; not fitted
SW1: RESET; SW-SMD_TS-1187A-5.1x5.1; LCSC C318884
SW2: BOOT; SW-SMD_TS-1187A-5.1x5.1; LCSC C318884
U1: AMS1117-3.3; SOT-223-3_TabPin2; LCSC C6186
U3: ESP32-C3-WROOM-02; LCSC C2934560
U4: TSOP382xx; Vishay_MINICAST-3Pin; LCSC C141632
U5: AHT20; SENSOR-SMD_L3.0-W3.0-P1.00-BR; LCSC C2757850

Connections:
+3.3V: C2.1, C3.1, C5.2, C7.1, C8.1, C10.1, J4.1, R5.1, R6.1, R7.2, R8.2, R9.2, R10.2, R11.2, R12.2, R16.1, R27.1, R28.1, R29.1, R30.1, U1.2 (VO), U3.1 (3V3), U5.2 (VDD)
+5V: C1.1, D1.1 (A1), F1.1, J4.2, R15.1, U1.3 (VI)
/D11_A: D11.2 (A), R25.2
/D12_A: D12.2 (A), R20.1
/ESP_BOOT: R6.2, SW2.1, U3.8 (IO9)
/ESP_EN: C6.1, R5.2, SW1.1, U3.2 (EN)
/EXT_IR_A: J5.1, R30.2
/I2C_SCL: J4.4, R29.2, U3.12 (IO21/TXD), U5.3 (SCL)
/I2C_SDA: J4.3, R28.2, U3.11 (IO20/RXD), U5.4 (SDA)
/IO2_STRAP: R8.1, U3.16 (IO2)
/IO8_STRAP: R7.1, U3.7 (IO8)
/IR_DRAIN: D2.1 (K), D3.1 (K), D4.1 (K), D5.1 (K), J5.2, Q3.3 (D)
/IR_RX: U3.5 (IO6), U4.1 (OUT)
/IR_RX_VS: C9.1, R27.2, U4.3 (Vs)
/IR_TX: R13.2, R19.1, U3.10 (IO10)
/SPARE_IO0: J4.5, U3.18 (IO0)
/SPARE_IO1: J4.6, U3.3 (IO4)
/SPARE_RX: J4.7, U3.4 (IO5)
/SPARE_TX: J4.8, U3.6 (IO7)
/USB_D+: J2.A6 (D+), J2.B6 (D+), U3.14 (IO19)
/USB_D-: J2.A7 (D-), J2.B7 (D-), U3.13 (IO18)
/USER_LED1: R25.1, U3.15 (IO3)
/USER_LED2: R20.2, U3.17 (IO1)
GND: C1.2, C2.2, C3.2, C5.1, C6.2, C7.2, C8.2, C9.2, C10.2, D1.2 (A2), D6.1 (K), D7.1 (K), D10.1 (K), D11.1 (K), D12.1 (K), J2.A1 (GND), J2.A12 (GND), J2.B1 (GND), J2.B12 (GND), J2.S1 (SHIELD), J4.9, J4.10, Q3.2 (S), R1.2, R2.1, R14.1, SW1.2, SW2.2, U1.1 (GND), U3.9 (GND), U3.19 (GND), U4.2 (GND), U5.5 (GND)
unnamed: D2.2 (A), R9.1
unnamed: D3.2 (A), R10.1
unnamed: D4.2 (A), R11.1
unnamed: D5.2 (A), R12.1
unnamed: D6.2 (A), R15.2
unnamed: D7.2 (A), R16.2
unnamed: D10.2 (A), R19.2
unnamed: F1.2, J2.A4 (VBUS), J2.A9 (VBUS), J2.B4 (VBUS), J2.B9 (VBUS)
unnamed: J2.A5 (CC1), R1.1
unnamed: J2.B5 (CC2), R2.2
unnamed: Q3.1 (G), R13.1, R14.2

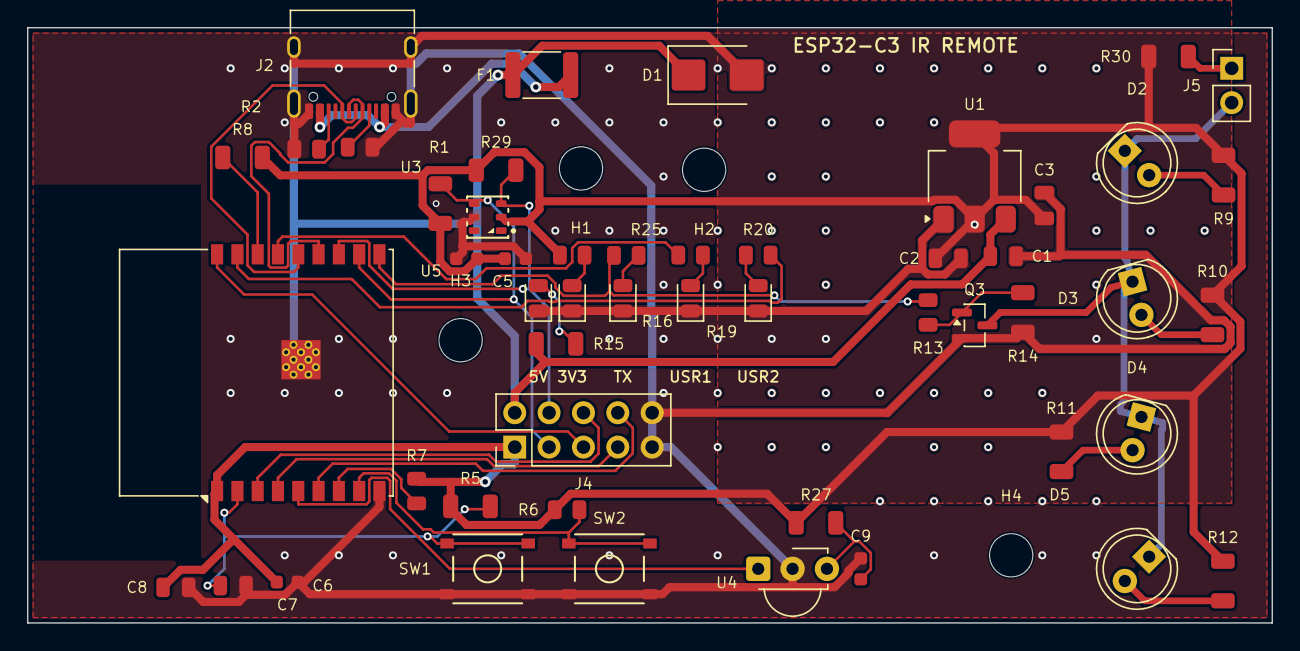
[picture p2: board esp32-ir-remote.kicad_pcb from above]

Board: 2 copper layers, 92.0 x 44.0 mm, 55 parts (0 on the bottom side), 35 nets.

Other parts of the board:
H1, H2, H3, H4: M3; MountingHole_3.2mm_M3

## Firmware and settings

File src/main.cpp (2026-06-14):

/*
 * IR Controller - ActronAir AC Control
 *
 * Hardware (pins set per-board via build_flags in platformio.ini):
 *   - nodemcuv2: ESP8266 NodeMCU breadboard - IR RX GPIO14 (D5),
 *     IR TX GPIO4 (D2) via 2N2222 transistor
 *   - esp32-c3: ESP32-C3-WROOM-02 custom board v2 - IR TX GPIO5 (MOSFET
 *     driver, 4x TSAL6200), IR RX GPIO6 (TSOP38238). Console is the chip's
 *     native USB-Serial-JTAG over USB-C (no CH340 bridge).
 *
 * Purpose:
 *   Full-duplex IR control for ActronAir AC unit
 *   - Receive IR signals for debugging
 *   - Transmit BOSCH144 (climate control) and COOLIX (special functions) commands
 *
 * Serial Protocol:
 *   Commands: POWER:ON|OFF, TEMP:<16-30>, MODE:<mode>, FAN:<speed>, SWING, BOOST, LED, STATE
 *   Response: OK:<message> or ERROR:<message>
 */

#include <Arduino.h>
#include <IRremoteESP8266.h>
#include <IRsend.h>
#include <IRrecv.h>
#include <IRutils.h>
#include <ir_Bosch.h>
#include <ir_Coolix.h>

#include "bosch144_protocol.h"

// Pin Configuration (from build_flags; defaults match the ESP8266 breadboard)
#ifndef IR_LED_PIN
#define IR_LED_PIN 4
#endif
#ifndef IR_RECV_PIN
#define IR_RECV_PIN 14
#endif
const uint16_t kIrLedPin = IR_LED_PIN;
const uint16_t kIrRecvPin = IR_RECV_PIN;

// Serial Configuration
const uint32_t kBaudRate = 115200;
const uint16_t kSerialTimeout = 5000;  // ms - Wait up to 5 seconds for newline

// IR Objects
IRsend irsend(kIrLedPin);
IRrecv irrecv(kIrRecvPin, 1024, 50, true);
IRBosch144AC acBosch(kIrLedPin);
IRCoolixAC acCoolix(kIrLedPin);

// AC State
struct ACState {
  bool power;
  float temperature;  // 16.0 to 30.0 in 0.5° steps
  uint8_t mode;       // kBosch144Cool, kBosch144Heat, etc.
  uint16_t fanSpeed;  // kBosch144FanAuto, kBosch144Fan20, etc. (uint16_t!)
} acState;

// Debug mode
bool debugMode = false;

// Special function state tracking
bool swingState = false;   // false = 0xB9F505 (OFF), true = 0xB9F504 (ON)
bool boostState = false;   // false = 0xB9F502 (OFF), true = 0xB9F501 (ON)

// Function Prototypes
void setup();
void loop();
void handleSerialCommand();
void sendBosch144Command();
void sendCoolixCommand(uint32_t code);
void printState();
String getModeString(uint8_t mode);
String getFanString(uint16_t fanSpeed);
uint8_t parseMode(const String& modeStr);
uint16_t parseFanSpeed(const String& fanStr);
bool validateTemperature(float temp);

void setup() {
  // Initialize serial
  Serial.begin(kBaudRate);
  Serial.setTimeout(kSerialTimeout);
  delay(500);

  // Print startup banner
  Serial.println();
  Serial.println(F("========================================="));
  Serial.println(F(" ActronAir IR Controller"));
  Serial.println(F("========================================="));
  Serial.println();

  // Initialize IR transmitter
  irsend.begin();
  acBosch.begin();
  acCoolix.begin();
  Serial.print(F("✓ IR Transmitter initialized on GPIO"));
  Serial.println(kIrLedPin);

  // Initialize IR receiver (for debugging)
  irrecv.enableIRIn();
  Serial.print(F("✓ IR Receiver initialized on GPIO"));
  Serial.println(kIrRecvPin);

  // Initialize AC state with defaults
  acState.power = false;
  acState.temperature = 22.0;
  acState.mode = kBosch144Cool;
  acState.fanSpeed = kBosch144FanAuto;

  Serial.println();
  Serial.println(F("Ready. Send commands via serial:"));
  Serial.println(F("  POWER:ON|OFF  - Power control"));
  Serial.println(F("  TEMP:<16-30>  - Set temperature (0.5° increments)"));
  Serial.println(F("  MODE:<mode>   - Set mode (COOL/HEAT/DRY/FAN/AUTO)"));
  Serial.println(F("  FAN:<speed>   - Set fan (AUTO/20/40/60/80/100)"));
  Serial.println(F("  SWING         - Toggle swing"));
  Serial.println(F("  BOOST         - Activate boost/turbo"));
  Serial.println(F("  LED           - Toggle LED display"));
  Serial.println(F("  STATE         - Query current state"));
  Serial.println(F("  DEBUG:ON|OFF  - Enable/disable IR receive echo"));
  Serial.println();
  Serial.println(F("Debug commands:"));
  Serial.println(F("  PIN:<pin>:<HIGH|LOW>      - Manually set GPIO pin"));
  Serial.println(F("                              Example: PIN:4:HIGH"));
  Serial.println(F("  RAW:<protocol>:<hex_code> - Send raw IR code"));
  Serial.println(F("                              Example: RAW:COOLIX:B27BE0"));
  Serial.println();
}

void loop() {
  // Handle serial commands
  if (Serial.available() > 0) {
    handleSerialCommand();
  }

  // Handle IR receive (debug mode)
  if (debugMode) {
    decode_results results;
    if (irrecv.decode(&results)) {
      Serial.print(F("DEBUG: Received IR - "));
      Serial.println(resultToHumanReadableBasic(&results));
      irrecv.resume();
    }
  }

  delay(10);
}

void handleSerialCommand() {
  String command = Serial.readStringUntil('\n');
  command.trim();

  if (command.length() == 0) {
    return;
  }

  // Parse command and parameter
  int colonPos = command.indexOf(':');
  String cmd = (colonPos == -1) ? command : command.substring(0, colonPos);
  String param = (colonPos == -1) ? "" : command.substring(colonPos + 1);

  cmd.toUpperCase();
  param.toUpperCase();

  // Handle commands
  if (cmd == "POWER") {
    if (param == "ON") {
      acState.power = true;
      sendBosch144Command();
      Serial.println(F("OK:Power ON, sent BOSCH144 command"));
    } else if (param == "OFF") {
      acState.power = false;
      sendCoolixCommand(0xB27BE0);  // COOLIX Power OFF
      Serial.println(F("OK:Power OFF, sent COOLIX command"));
    } else {
      Serial.println(F("ERROR:Invalid parameter. Use POWER:ON or POWER:OFF"));
    }
  }
  else if (cmd == "TEMP") {
    float temp = param.toFloat();
    if (validateTemperature(temp)) {
      acState.temperature = temp;
      acState.power = true;  // Setting temp implies power on
      sendBosch144Command();
      Serial.print(F("OK:Temperature set to "));
      Serial.print(temp, 1);
      Serial.println(F("C"));
    } else {
      Serial.println(F("ERROR:Invalid temperature. Use 16.0-30.0 in 0.5° steps"));
    }
  }
  else if (cmd == "MODE") {
    uint8_t mode = parseMode(param);
    if (mode != 255) {
      acState.mode = mode;
      acState.power = true;  // Setting mode implies power on
      sendBosch144Command();
      Serial.print(F("OK:Mode set to "));
      Serial.println(param);
    } else {
      Serial.println(F("ERROR:Invalid mode. Use COOL/HEAT/DRY/FAN/AUTO"));
    }
  }
  else if (cmd == "FAN") {
    uint16_t fanSpeed = parseFanSpeed(param);
    if (fanSpeed != 0xFFFF) {
      acState.fanSpeed = fanSpeed;
      acState.power = true;  // Setting fan implies power on
      sendBosch144Command();
      Serial.print(F("OK:Fan set to "));
      Serial.println(param);
    } else {
      Serial.println(F("ERROR:Invalid fan speed. Use AUTO/20/40/60/80/100"));
    }
  }
  else if (cmd == "SWING") {
    // Toggle between two swing states (swapped codes)
    swingState = !swingState;
    uint32_t swingCode = swingState ? 0xB9F504 : 0xB9F505;
    sendCoolixCommand(swingCode);
    Serial.print(F("OK:Swing "));
    Serial.println(swingState ? "ON" : "OFF");
  }
  else if (cmd == "BOOST") {
    // Toggle boost state
    boostState = !boostState;
    uint32_t boostCode = boostState ? 0xB9F501 : 0xB9F502;
    sendCoolixCommand(boostCode);
    Serial.print(F("OK:Boost "));
    Serial.println(boostState ? "ON" : "OFF");
  }
  else if (cmd == "LED") {
    sendCoolixCommand(0xB9F509);  // COOLIX LED toggle
    Serial.println(F("OK:LED toggled"));
  }
  else if (cmd == "STATE") {
    printState();
  }
  else if (cmd == "DEBUG") {
    if (param == "ON") {
      debugMode = true;
      Serial.println(F("OK:Debug mode enabled"));
    } else if (param == "OFF") {
      debugMode = false;
      Serial.println(F("OK:Debug mode disabled"));
    } else {
      Serial.println(F("ERROR:Invalid parameter. Use DEBUG:ON or DEBUG:OFF"));
    }
  }
  else if (cmd == "PIN") {
    // PIN:<pin>:<HIGH|LOW> - Manually control GPIO pins for debugging
    // Example: PIN:4:HIGH or PIN:D2:HIGH
    int secondColon = param.indexOf(':');
    if (secondColon == -1) {
      Serial.println(F("ERROR:Invalid format. Use PIN:<pin>:<HIGH|LOW>"));
      return;
    }

    String pinStr = param.substring(0, secondColon);
    String stateStr = param.substring(secondColon + 1);
    stateStr.toUpperCase();

    // Parse pin number (support both "4" and "D2" notation)
    uint8_t pinNum;
    if (pinStr == "D2" || pinStr == "4") {
      pinNum = 4;
    } else if (pinStr == "D5" || pinStr == "14") {
      pinNum = 14;
    } else {
      pinNum = pinStr.toInt();
    }

    // Parse state
    if (stateStr == "HIGH" || stateStr == "1") {
      pinMode(pinNum, OUTPUT);
      digitalWrite(pinNum, HIGH);
      Serial.print(F("OK:Pin "));
      Serial.print(pinNum);
      Serial.println(F(" set HIGH"));
    } else if (stateStr == "LOW" || stateStr == "0") {
      pinMode(pinNum, OUTPUT);
      digitalWrite(pinNum, LOW);
      Serial.print(F("OK:Pin "));
      Serial.print(pinNum);
      Serial.println(F(" set LOW"));
    } else {
      Serial.println(F("ERROR:Invalid state. Use HIGH or LOW"));
    }
  }
  else if (cmd == "RAW") {
    // RAW:<protocol>:<hex_code> - Send raw IR codes
    // Example: RAW:COOLIX:B27BE0 or RAW:NEC:FF00FF00
    int secondColon = param.indexOf(':');
    if (secondColon == -1) {
      Serial.println(F("ERROR:Invalid format. Use RAW:<protocol>:<hex_code>"));
      return;
    }

    String protocol = param.substring(0, secondColon);
    String hexCode = param.substring(secondColon + 1);
    protocol.toUpperCase();

    // Convert hex string to number
    uint64_t code = 0;
    for (unsigned int i = 0; i < hexCode.length(); i++) {
      char c = hexCode.charAt(i);
      code <<= 4;
      if (c >= '0' && c <= '9') {
        code |= (c - '0');
      } else if (c >= 'A' && c <= 'F') {
        code |= (c - 'A' + 10);
      } else if (c >= 'a' && c <= 'f') {
        code |= (c - 'a' + 10);
      }
    }

    if (protocol == "COOLIX") {
      irsend.sendCOOLIX(code, kCoolixBits);
      Serial.print(F("OK:Sent COOLIX code 0x"));
      Serial.println((uint32_t)code, HEX);
    } else if (protocol == "NEC") {
      irsend.sendNEC(code);
      Serial.print(F("OK:Sent NEC code 0x"));
      Serial.println((uint32_t)code, HEX);
    } else if (protocol == "BOSCH144") {
      // For BOSCH144, expect 36 hex characters (18 bytes)
      if (hexCode.length() != 36) {
        Serial.println(F("ERROR:BOSCH144 requires 36 hex characters (18 bytes)"));
        return;
      }
      uint8_t rawData[kBosch144StateLength];
      for (uint16_t i = 0; i < kBosch144StateLength; i++) {
        String byteStr = hexCode.substring(i * 2, i * 2 + 2);
        rawData[i] = strtol(byteStr.c_str(), NULL, 16);
      }
      irsend.sendBosch144(rawData);
      Serial.println(F("OK:Sent BOSCH144 raw data"));
    } else {
      Serial.print(F("ERROR:Unsupported protocol: "));
      Serial.println(protocol);
      Serial.println(F("Supported: COOLIX, NEC, BOSCH144"));
    }
  }
  else {
    Serial.print(F("ERROR:Unknown command: "));
    Serial.println(cmd);
  }
}

void sendBosch144Command() {
  // Configure BOSCH144 AC with current state
  acBosch.setPower(acState.power);
  const uint8_t wholeDegrees = (uint8_t)acState.temperature;
  const bool halfDegree = (acState.temperature - wholeDegrees) >= 0.25;
  acBosch.setTemp(wholeDegrees);
  acBosch.setMode(acState.mode);
  acBosch.setFan(acState.fanSpeed);

  if (halfDegree) {
    // The library's setTemp() is whole-degrees only; the +0.5C flag lives in
    // byte 14 bit 5 (re-findings.md). Patch the raw frame and resend the
    // checksum (getRaw() has already applied inverts + checksum).
    uint8_t* raw = acBosch.getRaw();
    raw[14] |= 0x20;
    bosch144::updateChecksum(raw);
    irsend.sendBosch144(raw);
  } else {
    acBosch.send();
  }

  #ifdef DEBUG_IR
  // Print raw state for debugging
  uint8_t* raw = acBosch.getRaw();
  Serial.print(F("DEBUG: BOSCH144 sent - "));
  for (uint16_t i = 0; i < kBosch144StateLength; i++) {
    Serial.printf("%02X ", raw[i]);
  }
  Serial.println();
  #endif
}

void sendCoolixCommand(uint32_t code) {
  // Send COOLIX command
  acCoolix.setRaw(code);
  acCoolix.send();

  #ifdef DEBUG_IR
  Serial.printf("DEBUG: COOLIX sent - 0x%06X\n", code);
  #endif
}

void printState() {
  Serial.print(F("OK:Power="));
  Serial.print(acState.power ? "ON" : "OFF");
  Serial.print(F(",Temp="));
  Serial.print(acState.temperature, 1);
  Serial.print(F(",Mode="));
  Serial.print(getModeString(acState.mode));
  Serial.print(F(",Fan="));
  Serial.println(getFanString(acState.fanSpeed));
}

String getModeString(uint8_t mode) {
  switch (mode) {
    case kBosch144Cool: return F("COOL");
    case kBosch144Heat: return F("HEAT");
    case kBosch144Dry:  return F("DRY");
    case kBosch144Fan:  return F("FAN");
    case kBosch144Auto: return F("AUTO");
    default: return F("UNKNOWN");
  }
}

String getFanString(uint16_t fanSpeed) {
  if (fanSpeed == kBosch144FanAuto) return F("AUTO");
  if (fanSpeed == kBosch144Fan20) return F("20");
  if (fanSpeed == kBosch144Fan40) return F("40");
  if (fanSpeed == kBosch144Fan60) return F("60");
  if (fanSpeed == kBosch144Fan80) return F("80");
  if (fanSpeed == kBosch144Fan100) return F("100");
  return F("UNKNOWN");
}

uint8_t parseMode(const String& modeStr) {
  if (modeStr == "COOL") return kBosch144Cool;
  if (modeStr == "HEAT") return kBosch144Heat;
  if (modeStr == "DRY")  return kBosch144Dry;
  if (modeStr == "FAN")  return kBosch144Fan;
  if (modeStr == "AUTO") return kBosch144Auto;
  return 255;  // Invalid
}

uint16_t parseFanSpeed(const String& fanStr) {
  if (fanStr == "AUTO") return kBosch144FanAuto;
  if (fanStr == "20")   return kBosch144Fan20;
  if (fanStr == "40")   return kBosch144Fan40;
  if (fanStr == "60")   return kBosch144Fan60;
  if (fanStr == "80")   return kBosch144Fan80;
  if (fanStr == "100")  return kBosch144Fan100;
  return 0xFFFF;  // Invalid (uint16_t max)
}

bool validateTemperature(float temp) {
  // Check range: 16.0 to 30.0
  if (temp < 16.0 || temp > 30.0) {
    return false;
  }

  // Check 0.5° increments
  float remainder = fmod(temp, 0.5);
  return (remainder < 0.01 || remainder > 0.49);  // Allow small floating point errors
}

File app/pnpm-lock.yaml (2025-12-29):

lockfileVersion: '9.0'

settings:
  autoInstallPeers: true
  excludeLinksFromLockfile: false

importers:

  .:
    dependencies:
      '@react-router/node':
        specifier: 7.10.1
        version: 7.10.1(react-router@7.10.1(react-dom@19.2.3(react@19.2.3))(react@19.2.3))(typescript@5.9.3)
      '@react-router/serve':
        specifier: 7.10.1
        version: 7.10.1(react-router@7.10.1(react-dom@19.2.3(react@19.2.3))(react@19.2.3))(typescript@5.9.3)
      '@serialport/parser-readline':
        specifier: ^13.0.0
        version: 13.0.0
      isbot:
        specifier: ^5.1.31
        version: 5.1.32
      react:
        specifier: ^19.2.3
        version: 19.2.3
      react-dom:
        specifier: ^19.2.3
        version: 19.2.3(react@19.2.3)
      react-router:
        specifier: 7.10.1
        version: 7.10.1(react-dom@19.2.3(react@19.2.3))(react@19.2.3)
      serialport:
        specifier: ^13.0.0
        version: 13.0.0
    devDependencies:
      '@playwright/test':
        specifier: ^1.57.0
        version: 1.57.0
      '@react-router/dev':
        specifier: 7.10.1
        version: 7.10.1(@react-router/serve@7.10.1(react-router@7.10.1(react-dom@19.2.3(react@19.2.3))(react@19.2.3))(typescript@5.9.3))(@types/node@22.19.3)(jiti@2.6.1)(lightningcss@1.30.2)(react-router@7.10.1(react-dom@19.2.3(react@19.2.3))(react@19.2.3))(typescript@5.9.3)(vite@7.3.0(@types/node@22.19.3)(jiti@2.6.1)(lightningcss@1.30.2))
      '@tailwindcss/vite':
        specifier: ^4.1.13
        version: 4.1.18(vite@7.3.0(@types/node@22.19.3)(jiti@2.6.1)(lightningcss@1.30.2))
      '@testing-library/jest-dom':
        specifier: ^6.9.1
        version: 6.9.1
      '@testing-library/react':
        specifier: ^16.3.1
        version: 16.3.1(@testing-library/dom@10.4.1)(@types/react-dom@19.2.3(@types/react@19.2.7))(@types/react@19.2.7)(react-dom@19.2.3(react@19.2.3))(react@19.2.3)
      '@types/node':
        specifier: ^22
        version: 22.19.3
      '@types/react':
        specifier: ^19.2.7
        version: 19.2.7
      '@types/react-dom':
        specifier: ^19.2.3
        version: 19.2.3(@types/react@19.2.7)
      '@vitejs/plugin-react':
        specifier: ^5.1.2
        version: 5.1.2(vite@7.3.0(@types/node@22.19.3)(jiti@2.6.1)(lightningcss@1.30.2))
      '@vitest/ui':
        specifier: ^4.0.16
        version: 4.0.16(vitest@4.0.16)
      happy-dom:
        specifier: ^20.0.11
        version: 20.0.11
      tailwindcss:
        specifier: ^4.1.13
        version: 4.1.18
      typescript:
        specifier: ^5.9.2
        version: 5.9.3
      vite:
        specifier: ^7.1.7
        version: 7.3.0(@types/node@22.19.3)(jiti@2.6.1)(lightningcss@1.30.2)
      vite-tsconfig-paths:
        specifier: ^5.1.4
        version: 5.1.4(typescript@5.9.3)(vite@7.3.0(@types/node@22.19.3)(jiti@2.6.1)(lightningcss@1.30.2))
      vitest:
        specifier: ^4.0.16
        version: 4.0.16(@types/node@22.19.3)(@vitest/ui@4.0.16)(happy-dom@20.0.11)(jiti@2.6.1)(lightningcss@1.30.2)

packages:

  '@adobe/css-tools@4.4.4':
    resolution: {integrity: sha512-Elp+iwUx5rN5+Y8xLt5/GRoG20WGoDCQ/1Fb+1LiGtvwbDavuSk0jhD/eZdckHAuzcDzccnkv+rEjyWfRx18gg==}

  '@babel/code-frame@7.27.1':
    resolution: {integrity: sha512-cjQ7ZlQ0Mv3b47hABuTevyTuYN4i+loJKGeV9flcCgIK37cCXRh+L1bd3iBHlynerhQ7BhCkn2BPbQUL+rGqFg==}
    engines: {node: '>=6.9.0'}

  '@babel/compat-data@7.28.5':
    resolution: {integrity: sha512-6uFXyCayocRbqhZOB+6XcuZbkMNimwfVGFji8CTZnCzOHVGvDqzvitu1re2AU5LROliz7eQPhB8CpAMvnx9EjA==}
    engines: {node: '>=6.9.0'}

  '@babel/core@7.28.5':
    resolution: {integrity: sha512-e7jT4DxYvIDLk1ZHmU/m/mB19rex9sv0c2ftBtjSBv+kVM/902eh0fINUzD7UwLLNR+jU585GxUJ8/EBfAM5fw==}
    engines: {node: '>=6.9.0'}

  '@babel/generator@7.28.5':
    resolution: {integrity: sha512-3EwLFhZ38J4VyIP6WNtt2kUdW9dokXA9Cr4IVIFHuCpZ3H8/YFOl5JjZHisrn1fATPBmKKqXzDFvh9fUwHz6CQ==}
    engines: {node: '>=6.9.0'}

  '@babel/helper-annotate-as-pure@7.27.3':
    resolution: {integrity: sha512-fXSwMQqitTGeHLBC08Eq5yXz2m37E4pJX1qAU1+2cNedz/ifv/bVXft90VeSav5nFO61EcNgwr0aJxbyPaWBPg==}
    engines: {node: '>=6.9.0'}

  '@babel/helper-compilation-targets@7.27.2':
    resolution: {integrity: sha512-2+1thGUUWWjLTYTHZWK1n8Yga0ijBz1XAhUXcKy81rd5g6yh7hGqMp45v7cadSbEHc9G3OTv45SyneRN3ps4DQ==}
    engines: {node: '>=6.9.0'}

  '@babel/helper-create-class-features-plugin@7.28.5':
    resolution: {integrity: sha512-q3WC4JfdODypvxArsJQROfupPBq9+lMwjKq7C33GhbFYJsufD0yd/ziwD+hJucLeWsnFPWZjsU2DNFqBPE7jwQ==}
    engines: {node: '>=6.9.0'}
    peerDependencies:
      '@babel/core': ^7.0.0

  '@babel/helper-globals@7.28.0':
    resolution: {integrity: sha512-+W6cISkXFa1jXsDEdYA8HeevQT/FULhxzR99pxphltZcVaugps53THCeiWA8SguxxpSp3gKPiuYfSWopkLQ4hw==}
    engines: {node: '>=6.9.0'}

  '@babel/helper-member-expression-to-functions@7.28.5':
    resolution: {integrity: sha512-cwM7SBRZcPCLgl8a7cY0soT1SptSzAlMH39vwiRpOQkJlh53r5hdHwLSCZpQdVLT39sZt+CRpNwYG4Y2v77atg==}
    engines: {node: '>=6.9.0'}
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

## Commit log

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2025-12-29 Add web control interface for AC remote
    Implement React Router v7 web application with:
    - Real-time AC control interface (temperature, mode, fan speed)
    - Serial communication with ESP8266 over USB
    - Mock serial manager for development/testing without hardware
    - Real serial manager using Node.js serialport package
    - SWING/BOOST/LED toggle buttons with visual state indication
    - Current state display (temperature, mode, fan, power)
    - Responsive UI with loading states and error handling
    Features:
    - Server-side rendering with React Router loaders/actions
    - E2E testing with Playwright (serial port mocking)
    - Unit tests with Vitest
    - TypeScript type safety
    - Serial buffer management (one-time drai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
    [pnpm-lock.yaml]
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2026-01-03 Add KiCad schematic for ESP32 IR remote dev board
    Complete schematic implementation including:
    - USB-C power input with PTC fuse and TVS protection
    - AP63203 buck converter (3.3V) with disable jumper (JP1)
    - CH340C USB-UART bridge with auto-reset circuit
    - Auto-reset bypass jumpers (JP2, JP3) for debugging
    - ESP32-WROOM-32E module with all GPIO exposed
    - IR transmitter: 4x LEDs driven by IRLML6344 MOSFET
    - IR receiver: TSOP1838 with decoupling
    - DHT22 temperature/humidity sensor
    - Status LEDs (power, TX/RX, IR, 2x user programmable)
    - RESET and BOOT buttons
    - DevKitC-compatible 2x19 breakout header
    GPIO assignments: IR_TX=GPIO18, IR_RX=GPIO19, TEMP_DATA=GPIO4,
    USER_LED1=GPIO16, USER_LED2=GP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
    [esp32-ir-remote.kicad_pcb, esp32-ir-remote.kicad_sch]
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2026-01-10 Add footprints, blue LED MOSFET drivers, and JLCPCB part assignments
    Schematic updates:
    - Add Q4, Q5 (2N7002) as low-side MOSFET drivers for blue LEDs
    - Add R23, R24 (100kΩ) gate pulldown resistors
    - Add R25 (1kΩ) as second blue LED current limiting resistor
    - Assign footprints to all components for PCB layout
    - Add LCSC part numbers for JLCPCB assembly
    - Add PWR_FLAG symbols for ERC compliance
    - Add no-connect flags on unused CH340C pins
    Library additions:
    - Add SRP5030T-4R7M inductor footprint and symbol from SnapEDA
    Note: CH340C VCC still needs to be rewired from +3.3V to +5V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
    [esp32-ir-remote.kicad_sch]
2026-01-15 Add circuit.md format and document ESP32 IR Remote schematic
    Introduces a new markdown-based circuit description format that captures
    both topology and design rationale. The format supports:
    - Net and component declarations with bracket syntax
    - Inline passives: [VCC --- 10kΩ --- EN]
    - Design properties: [dropout ==> 1.2V]
    - Subcircuit references: @./power-supply.circuit.md
    Circuit documentation for ESP32 IR Remote board:
    - power-supply.circuit.md: USB-C, protection, AP63203 buck
    - usb-serial.circuit.md: CH340C with auto-reset circuit
    - esp32-mcu.circuit.md: ESP32-WROOM-32E module
    - ir-transmitter.circuit.md: 4x TSAL6200 with MOSFET driver
    - ir-receiver.circuit.md: TSOP38238 for developmen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
    [esp32-ir-remote.kicad_pcb, esp32-ir-remote.kicad_sch, esp32-ir-remote_bom.csv]
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2026-06-10 Add ESP32 build env, BOSCH144 protocol tests, and half-degree fix
    Phase F1.1-F1.3 of the roadmap:
    - platformio.ini: common [env] base; new esp32dev env for the custom
    board (IR TX GPIO18, IR RX GPIO19 per hardware/notes); pins now flow
    through build_flags so main.cpp builds unchanged for both boards.
    Both envs compile; native excluded from default builds (test-only).
    - include/bosch144_protocol.h: pure-C++ BOSCH144 frame builder mirroring
    IRremoteESP8266's bit layout, cross-checked against captured tables in
    re-findings.md. Resolves the byte-17 checksum (sum of bytes 12..16,
    previously 'not reverse-engineered') and documents a likely 28C capture
    mislabel (0x90 vs library 0x80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
    [bosch144_protocol.h, main.cpp]
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2026-06-10 v1.2 Tier 1: H1.4 value fixes + LCSC backfill (via kicad-edit MCP, netlist-verified)
    Values: R13 gate resistor 10k->470R (38kHz IR switching speed), L1
    3.9uH->4.7uH (SWPA6045S4R7MT C78804: Isat 5.5A, DCR 26mOhm, 6x6mm; no
    Basic-library 4.7uH power inductor exists anymore - SWPA series moved to
    Extended, accepted one feeder fee), R16 D7-green 150R->470R (consolidates
    with R17-R19).
    LCSC backfill on the 15 H1.2 gap parts (C10, D1, D4-D12, F1, SW1, SW2)
    function-matched per the ROADMAP table. Also FIXED a latent BOM bug found
    during census: R13/R22 (10k) carried C17955 - the 18-ohm code from the
    R9-R12 group; R22 corrected to C17414 matching R3-R8.
    Netlist diff verified: fields/values only, n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
    [esp32-ir-remote.kicad_sch]
2026-06-10 v1.2: standardize 8 PCM_JLCPCB symbols to generic libs (electrically empty)
    R20/R21/R23-R26 -> Device:R, Q4/Q5 -> Transistor_FET:Q_NMOS_GSD; footprints
    PCM_JLCPCB:* -> Resistor_SMD / Package_TO_SOT_SMD:SOT-23. Removes the last
    dependency on the third-party PCM_JLCPCB plugin libs.
    Gotchas found and fixed during the swap (kicad-edit MCP lessons):
    - The PCM NMOS symbol is the MIRROR of Q_NMOS_GSD: a naive replace left
    Q4/Q5 pins floating in air. Fixed with (mirror y) on both instances -
    all three pins land exactly on the original wire endpoints.
    - replace_schematic_component resets Datasheet to '~'; restored all 8 URLs.
    - The MCP rewrite perturbed the embedded USB-C lib symbol (new
    lib_s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
    [esp32-ir-remote.kicad_sch]
2026-06-10 v1.2: remove redundant PWR_FLAG #FLG03 + its wire stub - ERC now 0 errors
    The flag sat on +3.3V which is already driven by CH340C V3 (power output),
    producing the long-standing pin_to_pin error from H1.1. Deleted the symbol
    and the 5mm dangling stub it hung from. Netlist: zero electrical change
    (date line only).
    ERC: 0 errors, 8 warnings - exactly the documented H1.1 dual-label set
    (ESP_GPIOxx + functional name on each MCU net, deliberate, cleaned up
    naturally by the H1.3 hierarchical refactor). Earlier reports showed only
    5 of these warnings; KiCad suppresses some multiple_net_names reports
    while other violations exist.
    [esp32-ir-remote.kicad_sch]
2026-06-10 Re-format schematic after kicad-edit MCP flattened it to one line
    The MCP's delete operations serialize the whole .kicad_sch as a single
    line (the previous commit's 18k-line 'deletion' was this, not content
    loss). Re-expanded via s-expression pretty-printer (tokenize -> parse ->
    emit, KiCad-ish style). Validated: regenerated netlist is byte-identical
    except the date line; ERC 0 errors; full-page render eyeballed. The next
    KiCad GUI save will normalize to canonical formatting.
    [esp32-ir-remote.kicad_sch]
2026-06-10 v1.2: remove J1 DevKitC debug breakout header (38 pins)
    Removed J1, its 4 power symbols, 47 harness wires, 33 net labels and a
    junction (scripted s-expr surgery; the J1 harness was verified fully
    self-contained first - no boundary-crossing wires). The 22 GPIO nets that
    existed only for the breakout (5, 6-11 flash, 12-14, 21-23, 25-27, 32-35,
    SENSOR_VP/VN) had their U3-side stubs+labels removed and explicit
    no_connect flags placed; 12 of them come back in the v1.2 connection
    points (Qwiic 21/22, spare header 23/25/26/32/33/34, JTAG 12/13/14/15).
    GPIO2/15 keep their strapping pulldowns (R7/R8); GPIO6-11 flash pins are
    now not broken out anywhere, resolving the H1.4 'confirm J1 GPIO6-11
    intent'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
    [esp32-ir-remote.kicad_sch]
2026-06-10 v1.2: add TSOP Vs RC filter (H1.4 MED fix)
    +3.3V -> R27 100R (1206, C17901 Basic) -> new IR_RX_VS net -> U4 Vs, with
    the existing C9 100nF now decoupling the filtered node (datasheet's
    recommended supply ripple filter for the TSOP receiver). PWR_FLAG #FLG04
    marks the node as intentionally resistor-fed (KiCad power_pin_not_driven).
    Netlist: /IR_RX_VS = {R27.2, U4.3, C9.1}; C9.2 stays on GND; no other nets
    touched. ERC 0 errors.
    [esp32-ir-remote.kicad_sch]
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2026-06-10 v1.2 wrap-up: regenerate BOM from schematic, demote BOM.md, roadmap
    BOM CSV regenerated with DNP column; only the 3 hand-solder pin headers
    lack LCSC (deliberate). Restored LCSC on the 8 symbol-swapped parts (the
    replace tool drops custom fields) and fixed two more latent code bugs
    found while re-verifying every code on LCSC/JLCPCB: Q3 IRLML6344 carried
    C8545 (the 2N7002 code) -> C53550; R14 100k and R15 1k carried 0805 codes
    on 1206 footprints -> C17900 / C4410 (both Basic, >900k stock).
    BOM.md demoted to rationale-only with a stale-data warning banner.
    ROADMAP: v1.2 change set marked done; kicad-edit MCP bug list documented
    (angle param ignored, field-dropping replace, file flattening, Ki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
    [esp32-ir-remote.kicad_sch, esp32-ir-remote_bom.csv]
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2026-06-10 H2.0: sync v1.2 schematic into PCB - footprints, values, nets all verified
    - sync_schematic_to_board added J3-J6 + R27-R30 footprints and the v1.2 nets,
    but left J1 in place, kept stale footprints/values, and SPLIT the 7
    dual-labelled GPIO nets (U3 pads on ESP_GPIOxx vs peripherals on functional
    names) - all repaired:
    - J1 (38-pin DevKitC breakout) deleted from board
    - Footprint swaps via pcbnew (position/orientation/path/nets preserved):
    L1 -> lib:IND-SMD_L6.7-W6.7 (4.7uH), Q4/Q5 -> SOT-23,
    R20/R25 -> R_0805_2012Metric, R21/R23/R24/R26 -> R_0603_1608Metric
    - Values: R13 10k->470R, R16 150R->470R, L1 3.9uH->4.7uH (H1.4 fixes)
    - Net repairs: U3 GPIO pads rejoined to USER_LED1/2, TEM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
    [esp32-ir-remote.kicad_pcb]
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2026-06-10 H2.2: board outline 80x55 + full placement, zero courtyard overlaps
    - Outline (100,60)-(180,115) with 4x M3 NPTH mounting holes (H1 pulled east
    of the WROOM antenna courtyard wedge; H3/H4 in corners)
    - All 76 footprints placed per hardware/notes/layout.md zones:
    WROOM antenna overhangs west edge 1.5mm; IR fan D2-D5 north edge rotated
    -67.5/-22.5/+22.5/+67.5 with R9-R12 row behind; TSOP+RC NE corner facing
    east; DHT22 + Qwiic + spare header east; USB-C south-center (mouth
    overhang fixed - courtyard is offset 2mm from origin, was recessed 1.9mm);
    buck cluster SW clear of the antenna keepout strip; CH340C between USB and
    module; status-LED bar D6-D9 along south-west edge; user LED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
    [esp32-ir-remote.kicad_pcb]
2026-06-10 Fix BOM blockers found by adversarial LCSC validation (pre-routing)
    Subagent validated all 35 LCSC codes against the live catalog; findings fixed:
    - BLOCKER: Q1/Q2 used Q_NPN_BCE symbol but S8050 (C2146) SOT-23 is B-E-C -
    collector/emitter were swapped on the physical part (auto-reset would not
    work). Embedded symbol pin numbers swapped -> Q_NPN_BEC, wires untouched,
    netlist nodes confirm C: pad2->3, E: pad3->2; PCB pad nets swapped to match.
    - BLOCKER: SW1/SW2 carried SMD switch code C455280 (TS-1088R 4x3mm) on a THT
    6mm footprint - unassemblable. Footprint -> JLC-MCP:SW-SMD_L3.9-W3.0-P4.45
    (fetched via jlcpcb MCP, validated 2 pads, clean layers); now SMT-line
    assemblable.
    - HIG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
    [esp32-ir-remote.kicad_pcb, esp32-ir-remote.kicad_sch, esp32-ir-remote_bom.csv]
2026-06-10 H2.3 WIP: routed board v11 (1010 tracks, 143 vias, 17 legs open) + routing toolchain
    - scripts/pcb_router.py: deterministic A* grid router (0.1mm grid, netclass
    widths, antenna keepout, J2 seed stubs, power-prefers-B, corridor penalties)
    - scripts/pcb_finish.py: connectivity finisher with bounded rip-up + history
    - scripts/pcb_pour.py: GND pours both layers + antenna keepout rule areas +
    stitching vias (not yet run)
    - scripts/pcb_silk.py, scripts/drc_summary.py: silk + DRC passes (pending)
    - placement deltas during routing: H1 into antenna-wedge corner (nylon screw
    note), J5/R30 west, C6 beside U2, R5-R7 pullups to NE, board min
    clearance/track relaxed to JLCPCB floor 0.127
    - scripts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
    [esp32-ir-remote.kicad_pcb]
2026-06-10 H2.3: routing COMPLETE - all nets connected
    Final sequence: local-families-first ordering, transit highways rerouted
    around the module pad row, R5/R6/R7 pullup pitch fix (the entire ESP_EN
    failure traced to R5/R6 courtyard overlap entombing R5's pad), R23
    relocated to free space, connectivity finisher converged round 2:
    ALL NETS CONNECTED (machine-verified component analysis of pads+tracks+vias).
    Courtyards: 1 accepted exception (H1 in the antenna-wedge corner, nylon
    screw documented in bring-up.md).
    [esp32-ir-remote.kicad_pcb]
2026-06-10 H2.3/H2.4 WIP: surgical short elimination - DRC errors 150->22
    Reset to routing-complete baseline, then: endpoint landings (router lands on
    pad bbox cells; roundrect corners aren't copper - 68 landing segments),
    SW-corner replacement (C1 pad physically overlapped L1's 2.65x7.3mm pad),
    R22 clear of U5, minimal rip-cover of all shorted net pairs (the old
    finisher healed same-round nets along identical paths - USB pair etc),
    short-safe router-only reroute. Shorts 59->7, crossings 32->0.
    6 unrouted legs + small fix families remain; pour deferred until copper
    stable. Netclass clearances aligned to 0.127 fab floor; min hole 0.2.
    [esp32-ir-remote.kicad_pcb]
2026-06-10 H2.3: pours + stitching in; one real unconnected leg fixed (U1/3)
    Key discovery: the router's 'unrouted legs' were mostly phantom - KiCad
    connectivity showed trunk copper already touching those pads; the only true
    gap was +5V->U1/3 (hand-routed via + stub). GND pour both layers + antenna
    keepout + 57 stitching vias. DRC: 55 errors remaining (shorts 17, dangling
    27, courtyards 4, hole_to_hole 6, clearance 7, thermal 12, keepout 2) -
    all enumerated, surgical fixes in progress.
    [esp32-ir-remote.kicad_pcb]
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2026-06-10 H2.3: recover good hand-routes; only ESP_GPIO25/26 split remain
    USB_D+/-, F1-Pad2 (VBUS), D12-A hand routes verified connected; the
    perimeter attempt for GPIO25/26 (109 shorts) surgically removed.
    [esp32-ir-remote.kicad_pcb]
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2026-06-11 H2.3/H2.4 COMPLETE: freerouting base + heals; DRC errors = 3 accepted H1 items
    Final approach that worked: strip copper, export DSN (kicad-edit MCP), route
    with the official freerouting container via podman (115 nets -> 2 unrouted in
    26s), import SES, heal the 2 + GND pour orphan-fragment bonding with validated
    via spots. Remaining: 3 errors = H1 mounting hole in the antenna keepout
    corner (documented, nylon screw); 7 zone-fragment pair notices (pour islands,
    electrically complete - every pad/track connected); 57 silk warnings (next).
    Board rules pinned: clearance 0.127, hole 0.2, via 0.45/0.2 annular 0.09,
    edge 0.2 - all within JLCPCB 2-layer documented capability.
    [esp32-ir-remote.dsn, esp32-ir-remote.kicad_pcb]
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2026-06-11 H3.1: JLCPCB fab outputs - gerbers.zip, BOM (35 lines, DNP excluded), CPL (67 placements)
    + board renders (top/bottom/iso) staged in fab/; site script render flags fixed
    [esp32-ir-remote-B_Cu.gbr, esp32-ir-remote-B_Mask.gbr, esp32-ir-remote-B_Paste.gbr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]
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2026-06-11 H3.1 fix: fab-verifier findings - all drills >=0.3mm (JLCPCB 2-layer floor), no drill marks on gerbers, annulars >=0.09, fresh CPL/renders
    Fab verification report: BOM/CPL PASS; gerber blockers fixed (12x 0.2mm U3
    thermal vias + 3x 0.25 vias enlarged; plot drillshape=none). Remaining
    advisories documented: verify rotations in JLCPCB preview (SOT-23/SOIC/TVS/
    USB-C/LEDs), AM2302 stock=37 order risk, J4/J5 hand-solder.
    [esp32-ir-remote-B_Cu.gbl, esp32-ir-remote-B_Mask.gbr, esp32-ir-remote-B_Mask.gbs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]
2026-06-11 H2.5 remediation complete: layout-review fixes verified, fab files re-exported
    Review fixes (second pass after the H-1/H-2/M-1..M-4 rework broke nets):
    - H-2: +3.3V/+5V/LED-anode nets widened 0.2->0.5 in place; DRC-driven
    selective neckdowns where lanes are tight (64 segs)
    - H-1: SW-node direct route kept; 2 segs necked 0.6->0.5 for GND pad
    clearance
    - M-1: buck B-keepout final extent (104.3,93.5)-(117.5,103.7); south edge
    set by the BST bootstrap B-jog (BST and JP1-B provably cross on F.Cu
    alone - see layout.md). pcb_finish.py learned BLOCK env to respect it.
    - Repaired rework collateral: BST ripped-not-rehealed (bootstrap cap!),
    JP1-B corridor war (rip + hand BST jog + reroute),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
    [esp32-ir-remote-B_Cu.gbl, esp32-ir-remote-B_Mask.gbs, esp32-ir-remote-B_Paste.gbp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]
2026-06-11 3D viewer: populate all components + 2D layer-toggle viewer
    Nick's feedback: GLB showed bare board (no pads) and only L1 rendered.
    - GLB export now passes --include-pads --include-silkscreen
    --include-soldermask (the board no longer looks unpopulated copper-less)
    - Fetched real EasyEDA 3D models via jlcpcb MCP (include_3d):
    TS-1088R switches (SW1/SW2 path now resolves), JST-SH (J3), AM2302 (U5)
    - Substituted models KiCad ships only as .wrl (GLB needs STEP):
    U3 ESP32-WROOM-32D -> ESP32-WROOM-32 (same body), F1 fuse -> C_1812 body
    - viewer.html: added 2D layer stack under the 3D view - per-layer SVGs
    (F/B Cu, F/B silk, F/B mask, edge) exported with a shared viewBox,
    checkbox toggles,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
    [esp32-ir-remote.kicad_pcb]
2026-06-11 Vendor 3D models into repo so CI/Pages renders the populated board
    Root cause of the bare deployed viewer: the kicad/kicad:9.0 CI container
    ships no 3D model library, so every ${KICAD9_3DMODEL_DIR} model silently
    dropped out of the GLB/renders built on CI - only L1 (project-local model)
    survived. Local builds looked fine, which masked it.
    Fix: copy the 21 unique STEP models this board uses into
    hardware/lib/3dshapes/ (13 MB) and rewrite all 71 footprint model paths to
    ${KIPRJMOD}-relative. The build is now environment-independent: same output
    locally, on CI, and for anyone cloning the repo. Verified locally: GLB
    export adds all 71 components, zero 'Could not add 3D model' warnings.
    [esp32-ir-remote.kicad_pcb]
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2026-06-11 Board silk: Claude spark + 'designed by Claude'; fix white GLB; seat AM2302 model
    - F.Silkscreen: 8-ray spark mark (filled polys) + two-line 'designed by
    Claude' at (129-141, 99.5-102.5), above the USB-C - clear of all pads/
    silk, DRC unchanged (3 accepted errors)
    - GLB white-models fix: kicad-cli omits metallicFactor/roughnessFactor and
    the glTF default is full metal -> washed-out white in model-viewer.
    scripts/fix_glb_materials.py rewrites factors post-export (dielectric
    0.05/0.65; gold-toned materials stay metallic 0.9/0.35), self-validates,
    hooked into build-site.sh
    - U5 AM2302 EasyEDA model seated: offset (3.81, -0.7, 9.2) - was centered
    through the board; verified by side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
    [esp32-ir-remote-B_Cu.gbl, esp32-ir-remote-B_Mask.gbs, esp32-ir-remote-B_Paste.gbp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]
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2026-06-11 GLB fixer: recolor materialless component primitives by mesh name
    Root cause of grey/white components on the deployed viewer (still present
    after the 9.0.6 pin): Linux KiCad builds fail to read STEP colors entirely
    - component primitives arrive with NO material (renderer default white).
    macOS exports the same board with 30 colored materials.
    The fixer now assigns a named material per component mesh (mesh names are
    the 3D model filenames) to any primitive lacking one: red LEDs, black ICs,
    tan capacitors, silver WROOM shield/USB-C, white AM2302, etc. No-op on
    correctly-colored exports (verified: local=0 recolored, CI file=6826).
    Validates zero materialless component primitives after rewrite.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
    [fix_glb_materials.py]
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2026-06-11 GLB: center before compress; opaque deeper soldermask
    - center must run before draco compression (after = re-inflates 0.7->8.5MB)
    - centering also fixes model-viewer framing: the board now fills the view
    and orbits its own center instead of the KiCad page origin
    - translucent soldermask (alpha .83) rendered milky in model-viewer ->
    solid slightly-deeper green, alphaMode OPAQUE
    Verified locally in Chrome: centered, full-frame, colored, instant load.
    [fix_glb_materials.py]
2026-06-11 Viewer: real per-face STEP colors via KiCad 10 CI image
    KiCad 9 Linux builds drop STEP model colors in GLB export, which is why
    every component rendered as one flat hand-picked color. KiCad 10.0.2
    exports them correctly (verified in-container on the real board: 0
    material-less primitives, 24 component materials vs 0).
    - pages.yml: kicad/kicad:9.0.6 -> 10.0.2; drop nodesource (trixie ships
    node 20, enough for gltf-transform)
    - fix_glb_materials.py: classify metals by color (gold/brass + silver/
    grey) instead of recoloring whole parts; clamp the soldermask deepen
    (the unclamped 1.1 multiplier pushed white silkscreen out of spec and
    tinted it green); validate color ranges; keep the rec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
    [fix_glb_materials.py]
2026-06-11 Auto-reset Q1/Q2: S8050 NPN BJTs -> 2N7002 N-MOSFETs (board v1.3)
    Swap the cross-coupled auto-reset transistors to the 2N7002 already used
    at Q4/Q5. The SOT-23 pinouts map 1:1 (B->G, E->S, C->D on the same pads),
    so the swap is layout-neutral: no copper, placement, or gerber changes.
    Consolidates the BOM 35->34 unique lines (C2146 dropped; Q1/Q2/Q4/Q5 all
    C8545, JLCPCB Basic, 779k stock).
    Verified headlessly in kicad/kicad:9.0.6 (files also read clean under
    10.0.2, the Pages CI image):
    - ERC: -2 warnings (old Q1/Q2 lib_symbol_mismatch gone), no new
    violations; the 2 GPIO25/26 dangling-label errors pre-exist (J4
    deviation).
    - Netlist diff electrically empty: same pads, same net partition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
    [esp32-ir-remote-jlcpcb-bom.csv, esp32-ir-remote.kicad_pcb, esp32-ir-remote.kicad_sch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]
2026-06-11 Auto-reset bypass links R21/R26: 0R -> 470R; purge unused lib symbols
    Nick OK'd larger changes in favor of circuit correctness. The FET swap's
    one real regression: holding RESET/BOOT with the port idle forward-biases
    the 2N7002 body diode (RTS->EN / DTR->GPIO0) and, through 0R links,
    shorted a CH340C pin to GND at ~25mA (the BJT circuit leaked 0.27mA via
    its 10k base path). Making the bypass links 470R (C23179, 0603, Basic,
    2.3M stock) caps that at ~5mA while staying transparent to auto-reset:
    EN/GPIO0 lows ~0.15V vs 0.825V VIL (5x margin even at worst-case Rds),
    EN-cap discharge 470R x 1uF = 0.5ms inside esptool's ~100ms pulses, and
    desolder-to-disable is preserved. BOM line count unchanged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
    [esp32-ir-remote-B_Cu.gbl, esp32-ir-remote-B_Mask.gbs, esp32-ir-remote-B_Paste.gbp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]
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2026-06-11 Schematic: Q3 -> AO3400A, SW1/SW2 -> TS-1187A (both Basic); ERC 0/7
    Cost/availability pass before the fab order (Nick OK'd part swaps):
    - Q3 IR driver: IRLML6344 (C53550, Extended) -> AO3400A (C20917, Basic,
    1.7M stock). Same SOT-23 pinout, logic-level, 48mOhm@2.5V vs 29mOhm
    - 8mV extra drop at the 0.42A IR burst, immaterial. Field-only change.
    - SW1/SW2: TS-1088R (C455280, Extended) -> XKB TS-1187A-B-A-B (C318884,
    Basic, 1.8M stock, $0.02). New footprint lib:SW-SMD_TS-1187A-5.1x5.1
    drawn from the datasheet land pattern (pads 1.0x0.75 at +/-3.0/+/-1.875).
    Datasheet circuit: same-row terminals are internally common, so the two
    rows are numbered 1/1 and 2/2 - the generic 2-pin SW_P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
    [esp32-ir-remote.kicad_sch]
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
